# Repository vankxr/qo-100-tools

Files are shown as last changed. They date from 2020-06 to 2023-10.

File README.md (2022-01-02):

# qo-100-tools
Various tools for transmission and reception on the QO-100 satellite amateur transponder bands. Includes everything I need (hopefully) to build a fully remote managed RF frontend to be placed on the roof, near the antenna while only bringing a few cables between it and the shack: power, two coax cables (TX IF and RX IF) and one UTP ethernet cable.

## Included tools
 - Upconverter - Converts the VHF/UHF IF signal to the uplink frequency of the satellite (2.4 GHz)
 - PA - Boosts the output power to 20 W (v1) and 250 W (v2) maximum
 - PA Driver - Amplifier to drive the main 250W PA
 - Directional Couplers - Experimental, manually constructed with simple scalpel cut traces on some Rogers RO4350B substrate
 - GPSDO - GPS Disciplined Oscillator to generate different precise reference frequencies
 - LNB Controller - LNB Bias and reference injection controller
 - Digital Power Meter - Module to measure DC power, used to calculate the PA efficiency
 - Digital RF Power Meter - Module to measure RF power, used to calculate the PA efficiency
 - Generic Filter - Footprints to build up to 11th order Butterworth/Chebyshev filters
 - Orange Pi Dock - Main board to house an OPi that will be the main brain of the system
 - Relay Controller - Module to provide relay coil switching capabilities
 - RF Switch - Implements a 5PST or 4PST RF switch for routing purposes
 - PSU Interface - Interface board for HP Common Slot Power supplies
 - SAW Filter adapter - Footprints for various SAW filter packages
 - PA Bias controller - Bias generator and monitor for the Power Amplifiers
 - PA TEC controller - Peltier cooler controller for the big PA
 - I2C Buffer - I2C bus signal buffer
 - Environment sensors - Sensor carrier board
 - LoRa Transceiver - SX1276 breakout for LoRa experiments

## Dependencies
 - [icyradio](https://github.com/vankxr/icyradio/tree/qo100) - IcyRadio Software Defined Radio to transmit and receive IF signals to the roof RF frontend
 - [icestorm](https://github.com/cliffordwolf/icestorm) - FPGA toolchain
 - [arm-none-eabi-gcc](https://developer.arm.com/tools-and-software/open-source-software/developer-tools/gnu-toolchain/gnu-rm/downloads) - MCUs toolchain
 - [Device CMSIS](https://www.keil.com/dd2/) - CMSIS headers defining the MCU memories, peripherals, etc...
 - [Core CMSIS](https://github.com/ARM-software/CMSIS_5) - CMSIS headers defining the ARM Cores
 - [armmem](https://github.com/vankxr/armmem) - ELF file analyzer (required for the MCU Makefiles to work)

## Authors

* **João Silva** - [vankxr](https://github.com/vankxr)

## Special thanks

* [JLCPCB](https://jlcpcb.com) for sponsoring most of the PCBs needed for this project.
* [raplin](https://github.com/raplin) for the work on [reverse engineering the HP power supplies](https://github.com/raplin/DPS-1200FB)

## License

The content of this repository is licensed under the [GNU General Public License v3.0](LICENSE).

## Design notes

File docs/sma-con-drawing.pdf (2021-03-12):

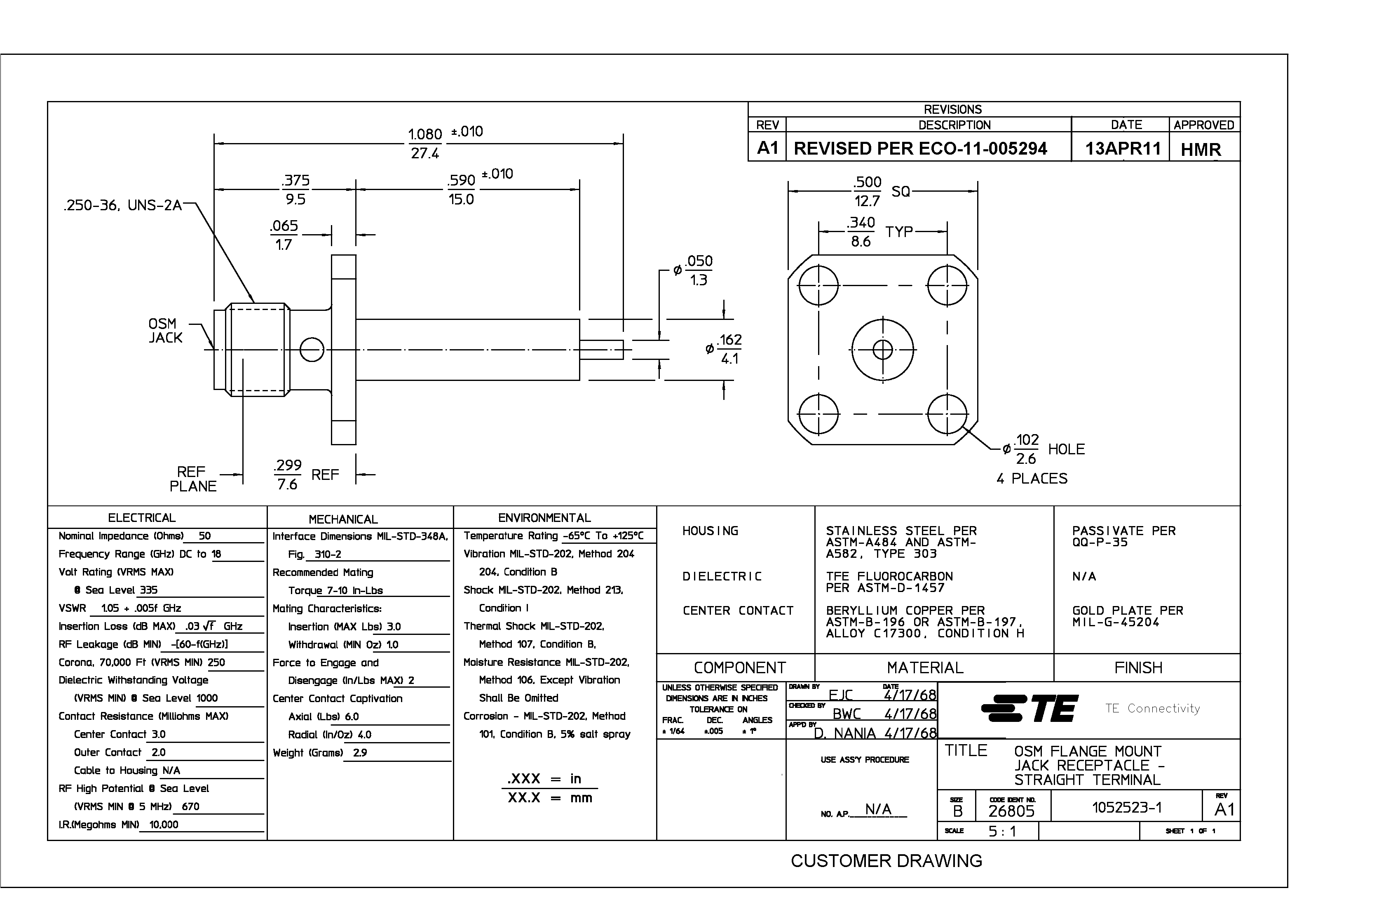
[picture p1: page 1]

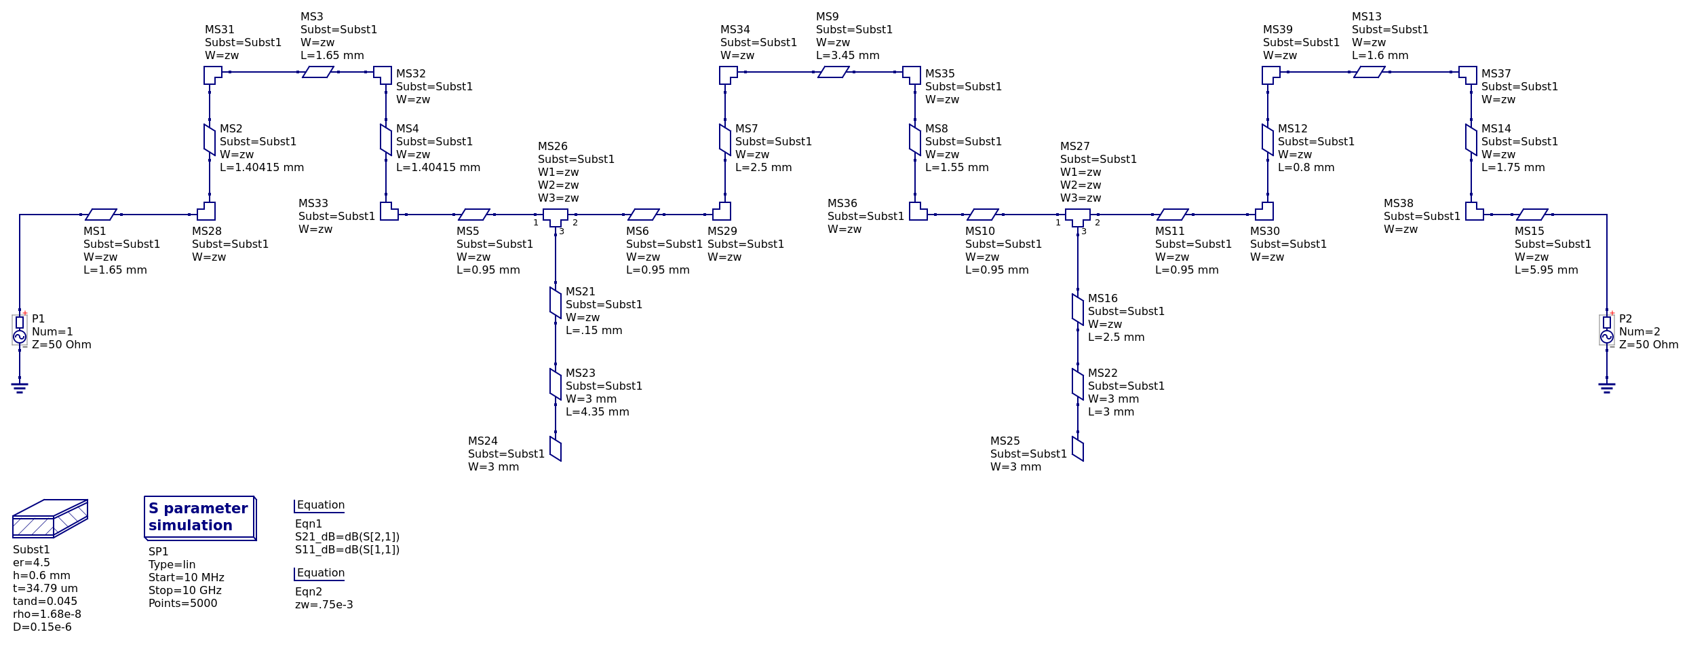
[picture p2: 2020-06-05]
util/pa-lpf-simulation/schematic.png

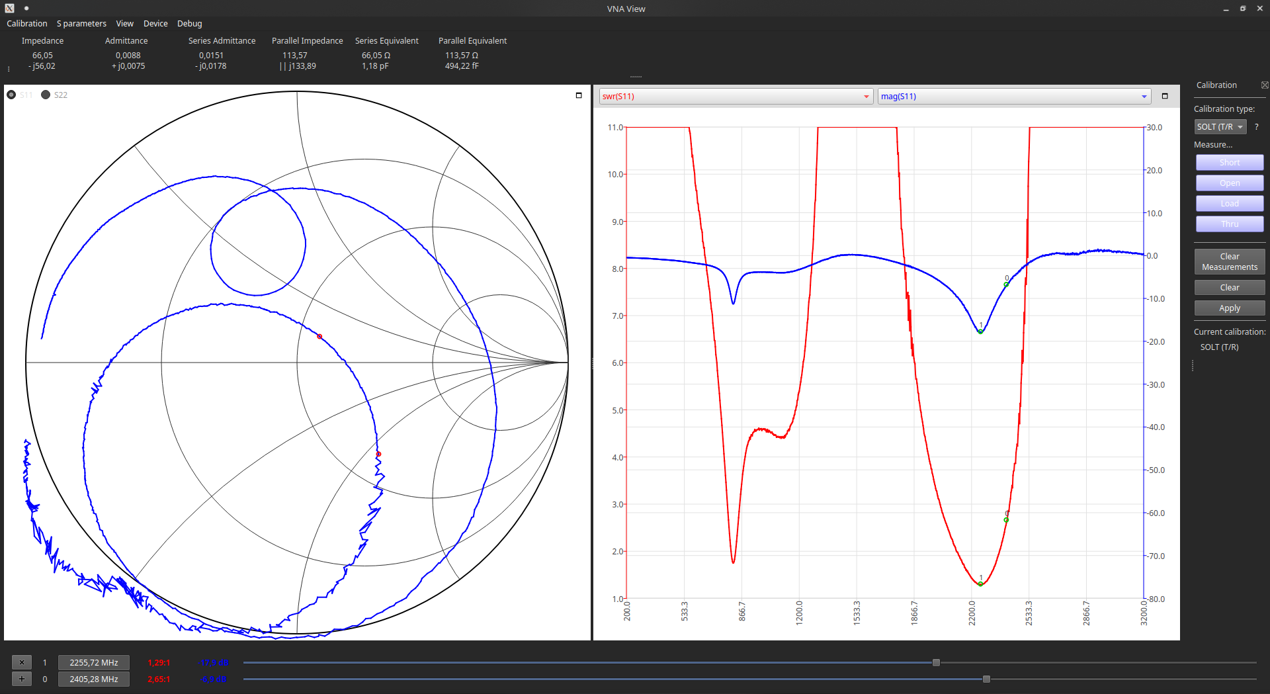
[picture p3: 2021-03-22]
docs/upconverter/upconverter_v3_mixer_output.png

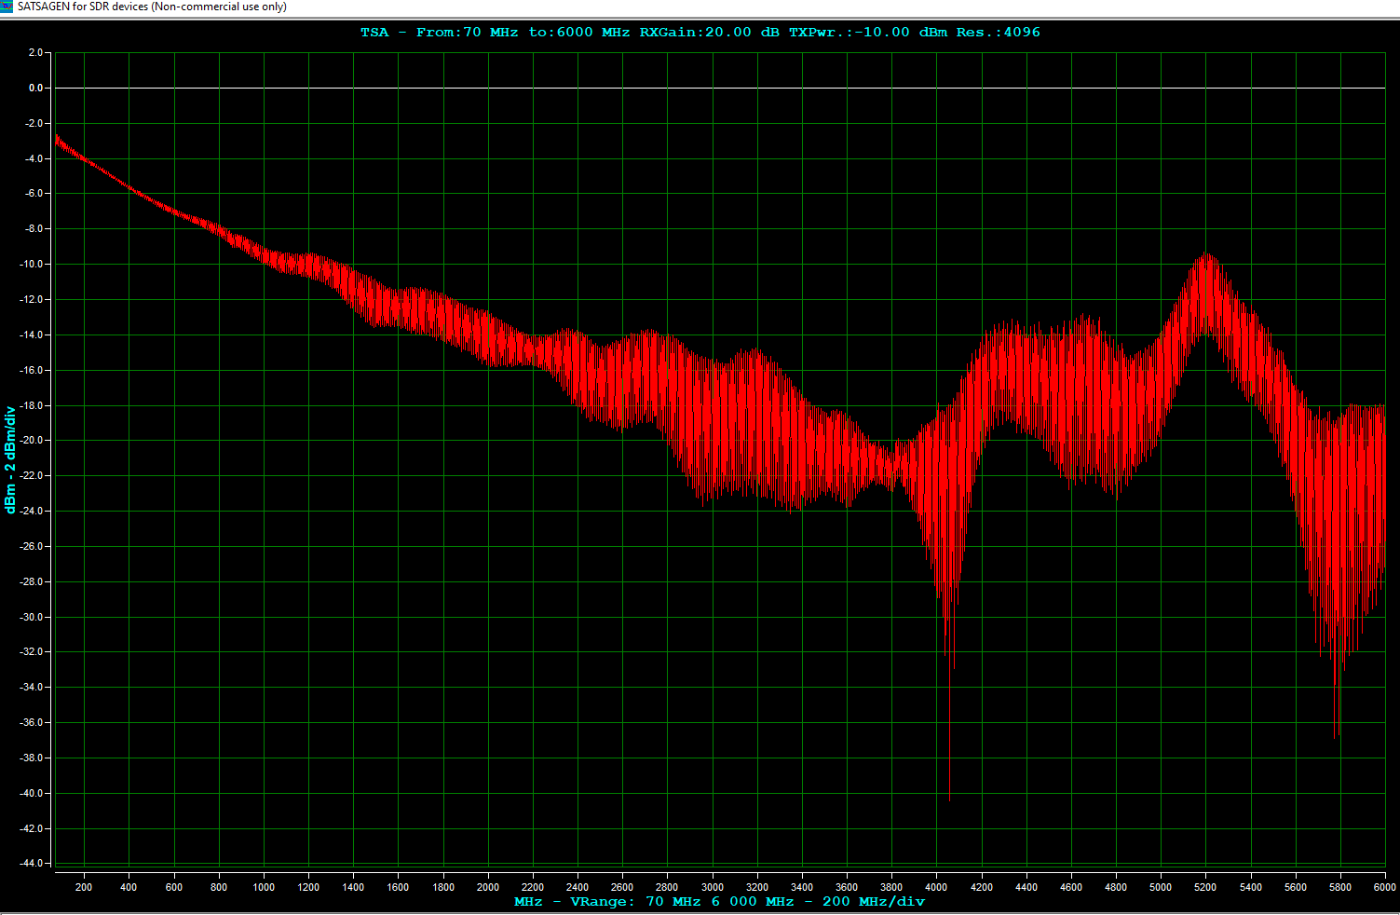
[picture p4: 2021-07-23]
docs/roof-cables/atten_1_2.png

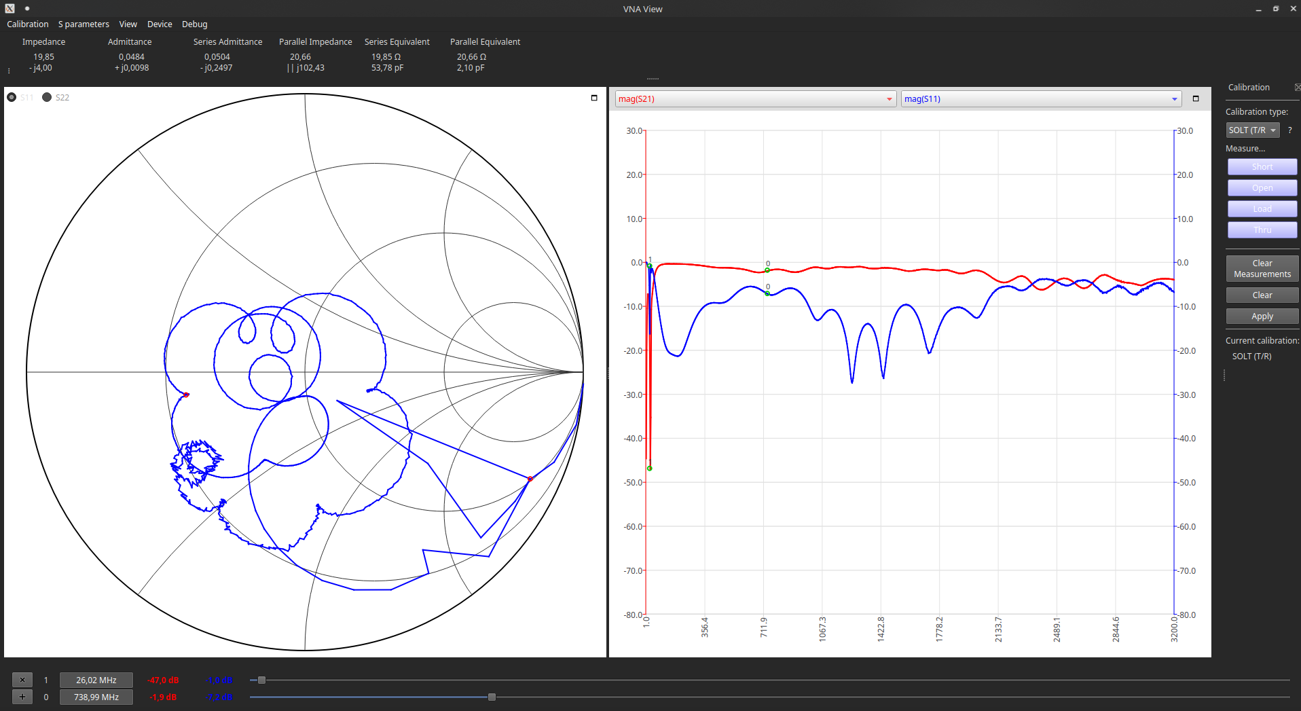
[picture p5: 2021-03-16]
docs/lnb-controller/lnb-controller-v2-path1-IF-to-RF.png

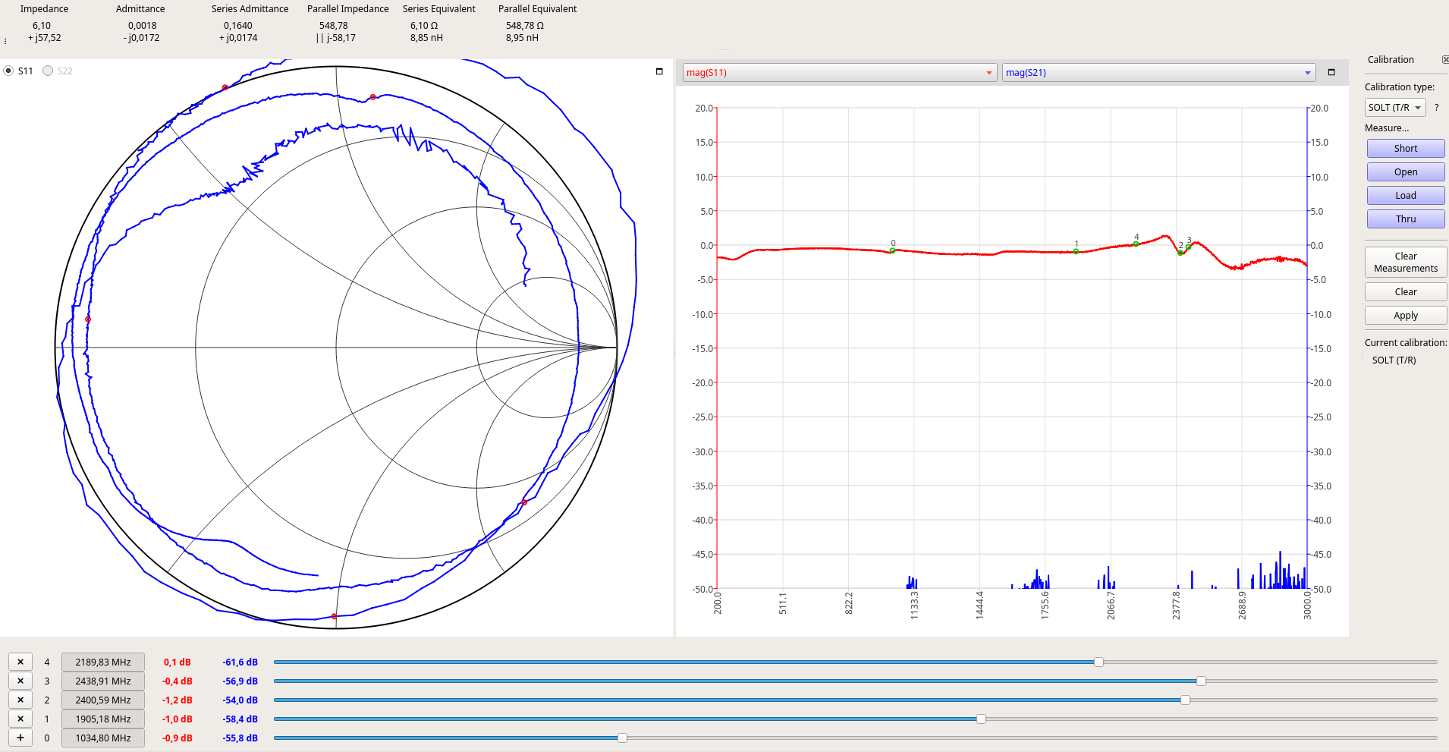
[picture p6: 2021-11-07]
docs/pa-driver/pa_20W_vdd_31V_idq_400mA_s22.png

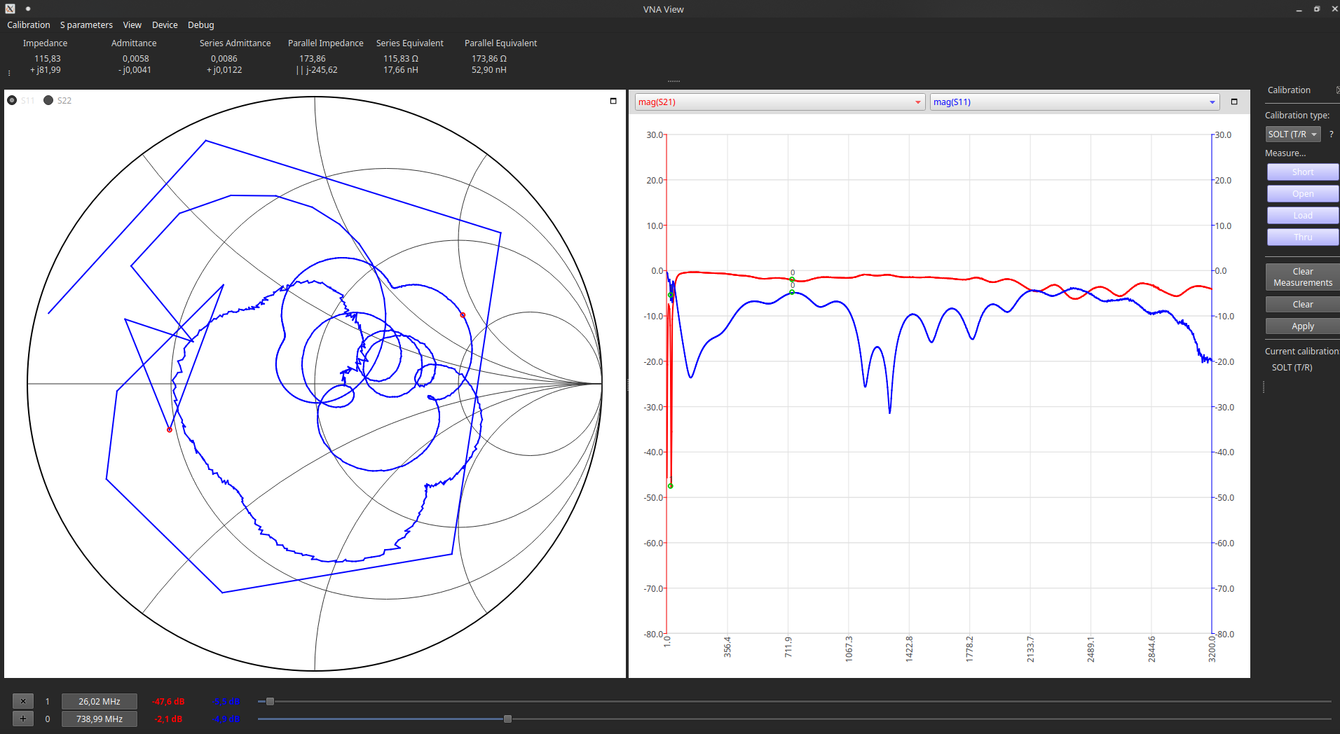
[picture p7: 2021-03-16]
docs/lnb-controller/lnb-controller-v2-path1-RF-to-IF.png

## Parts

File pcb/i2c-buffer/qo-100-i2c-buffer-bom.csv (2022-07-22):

Comment | Footprint | Designator
100nF | CAP0402 | C1, C2, C3, C5, C6, C7, C8, C9, C10, C11, C12
10K Ohms | RES0402 | R1, R13, R14, R15, R16, R17, R18, R19, R20
10uF | CAP0603 | C13, C14
1K Ohms | RES0402 | R2, R3, R5, R6, R7, R8, R9, R10, R11, R12, R21, R22, R23, R24, R25
1uF | CAP0402 | C4, C15
330 Ohms | RES0402 | R4
LED0603 | 0603 | D1
LED0603 | 0603 | D2, D3, D4, D5
LED0603 | 0603 | D10
LED0603 | 0603 | D6, D7, D8, D9

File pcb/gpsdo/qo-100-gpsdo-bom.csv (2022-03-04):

Comment | Footprint | Designator
0 Ohms | RES0402 | R22, R41, R42, R43, R44, R45
10 Ohms | RES0603 | R10
100 Ohms | RES0402 | R2, R3, R27, R29, R31, R33, R35
100K Ohms | POT3MM | R36, R37, R38, R39, R40
100K Ohms | RES0402 | R57, R59
100nF | CAP0402 | C2, C3, C4, C5, C6, C7, C9, C12, C13, C14, C18, C19, C24, C25, C27, C29, C31, C32, C42, C45, C68, C69, C70, C71, C72, C73, C74, C75, C76, C77, C80, C81, C82, C83, C84, C88, C89, C90, C101, C103, C104, C106, C107, C112, C114
100nH | IND0402 | L36
100pF | CAP0402 | C55, C56
100uF | CAP1206 | C11, C30, C108, C110, C111
10K Ohms | RES0402 | R7, R9, R14, R15, R16, R17, R23, R24, R25, R47, R48, R49, R50, R58
10nF | CAP0402 | C93, C96, C99, C109
10pF | CAP0402 | C40, C105
10uF | CAP0603 | C1, C10, C16, C17, C20, C23, C33, C43, C100, C102, C113
10uF | CAP1206 | C117
10uH | IND0603 | FB3
120nH | IND0402 | L21, L29, L30
150nH | IND0402 | L6, L34, L35
180nH | IND0402 | L16, L19, L20, L26
180pF | CAP0402 | C58, C59, C63, C64
1K Ohms | RES0402 | R12
1M Ohms | RES0402 | R54
1uF | CAP0402 | C8, C21, C22, C26, C28, C34, C35, C36, C37, C38, C39, C41, C44, C46, C48, C49, C78, C79, C85, C86, C87, C98
1uF | CAP0603 | C94, C95
1uH | IND0603 | FB1, FB2, FB4, FB5, FB6
2.2uH | IND3515 | L37
2.6A Hold | 1206 | F1
220nF | CAP0402 | C47, C50
220nH | IND0402 | L4, L5
226K Ohms | RES0402 | R55
22nH | IND0402 | L11
270 Ohms | RES0402 | R21
270nH | IND0402 | L14, L15, L24, L25
270pF | CAP0402 | C53, C54
27nH | IND0805 | L1
280 Ohms | RES0402 | R18
2EDG-2P-5MM | 2EDG-2P-5MM | CON4
3.9nF | CAP0402 | C51, C52
309K Ohms | RES0402 | R52
330 Ohms | RES0402 | R4, R19
330nH | IND0402 | L27, L28
33nH | IND0402 | L9, L10
390nH | IND0402 | L32, L33
3P-SH-SIDE | SH-03-SIDE | CON1
3P-SH-TOP | SH-03-TOP | CON3
4.7K Ohms | RES0402 | R1, R5, R6, R8
4.7uF | CAP0603 | C91, C92
4.7uH | IND0404 | L38
41.2K Ohms | RES0402 | R51
470 Ohms | RES0402 | R13
470nH | IND0402 | L17, L18
470pF | CAP0402 | C97, C115, C116
47pF | CAP0402 | C15, C62, C67
49.9 Ohms | RES0402 | R26, R28, R30, R32, R34
4P-SH-TOP | SH-04-TOP | CON2
510 Ohms | RES0402 | R20, R56
560nH | IND0402 | L2, L3
680nH | IND0402 | L22, L23
68pF | CAP0402 | C57, C60, C61, C65, C66
71.5K Ohms | RES0402 | R53
74LVC1G17 | SC70-5 | U2, U3, U11, U12, U13, U14, U15
75K Ohms | RES0402 | R46, R60
820nH | IND0402 | L12, L13
82nH | IND0402 | L7, L8, L31
AD5541ACPZ | DFN10 | U6
AD9544 | QFN48_2 | U10
ADM7171ACPZ-1.8 | LFCSP8_3X3 | U16
ADM7171ACPZ-3.3 | LFCSP8_3X3 | U20
ADM7171ACPZ-5.0 | LFCSP8_3X3 | U17
B0530W | SOD-123 | D3
BAV99 | SOT23 | D4, D5, D6, D7, D8
CR2032 | CR2032 | BAT1
DCJACK | DC-050 | J1
DNP | RES0603 | R11
DSB321SDA | TCXO-3225 | U9
EFM32GG11B420F2048GL112 | BGA112 | U1
JS-5MM | JS_5MM | LOGO1
LED0603 | 603 | D1, D9
LEDTH3MM | LED_3MM | D2, D10
LT8636 | QFN20_ASYM_3X4_CORNER | U19
MAX-M8Q | MAX-M8 | U4
MCP1501-40 | SOT23-6 | U5
MCP6V31 | SOT23-5 | U7
MIC23155 | DFN10 | U18
OSC5A2B02 | OSC5A2B02 | U8
RFCON-SMA-EDGE | SMA-EDGE | RFCON1
RFCON-U.FL | U.FL | RFCON2, RFCON3, RFCON4, RFCON5, RFCON6, RFCON7, RFCON8, RFCON9, RFCON10, RFCON11
SMAJ24A | DO214AC | D11
TC2050-IDC | TC2050-IDC | TC1

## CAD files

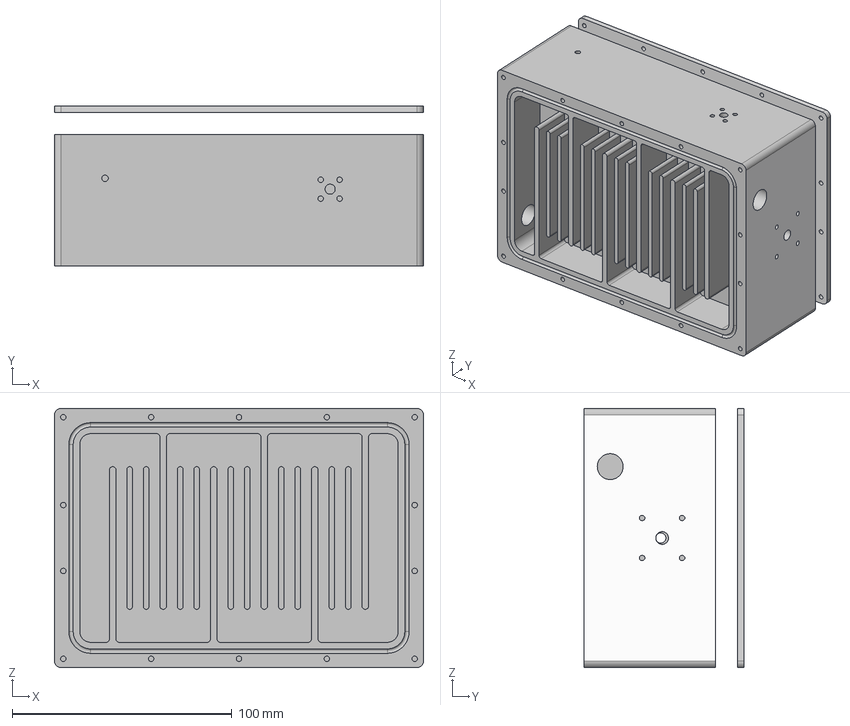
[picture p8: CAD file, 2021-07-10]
models/pa-case/pa-case.step
168.0 x 73.0 x 118.0 mm

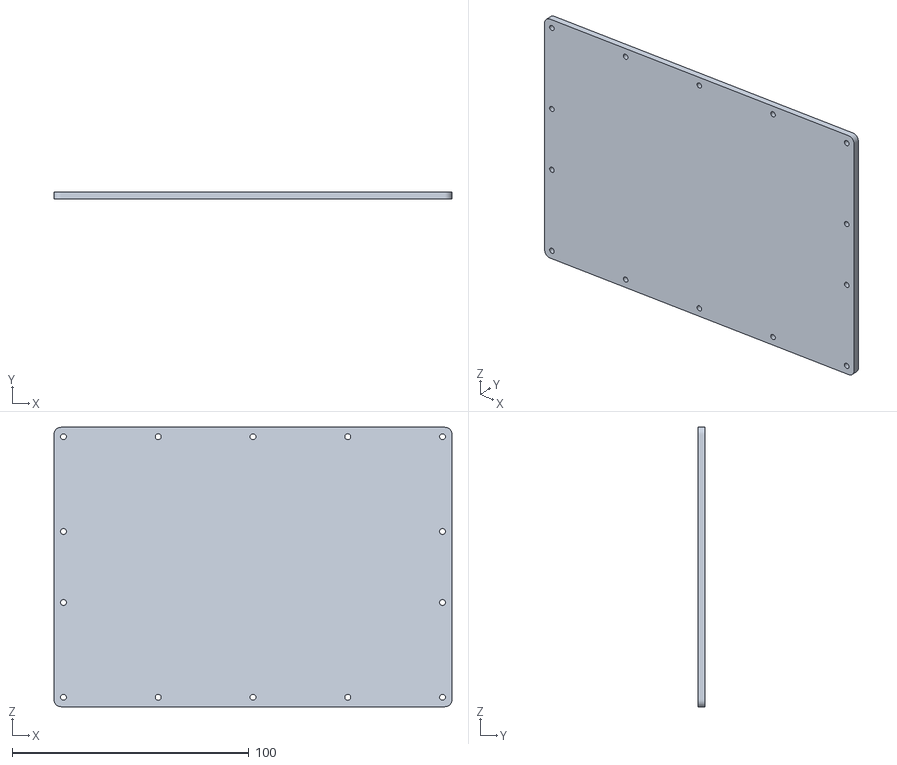
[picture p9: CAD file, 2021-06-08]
models/pa-case/pa-case-lid.stl
168.0 x 3.00 x 118.0

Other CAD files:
docs/pa-driver/BLP9G0722-20G_2100MHz_ref_pcb.dwg
docs/pa/BLC2425M9LS250_ref_pcb.dxf
models/pa-case/pa-case.stl

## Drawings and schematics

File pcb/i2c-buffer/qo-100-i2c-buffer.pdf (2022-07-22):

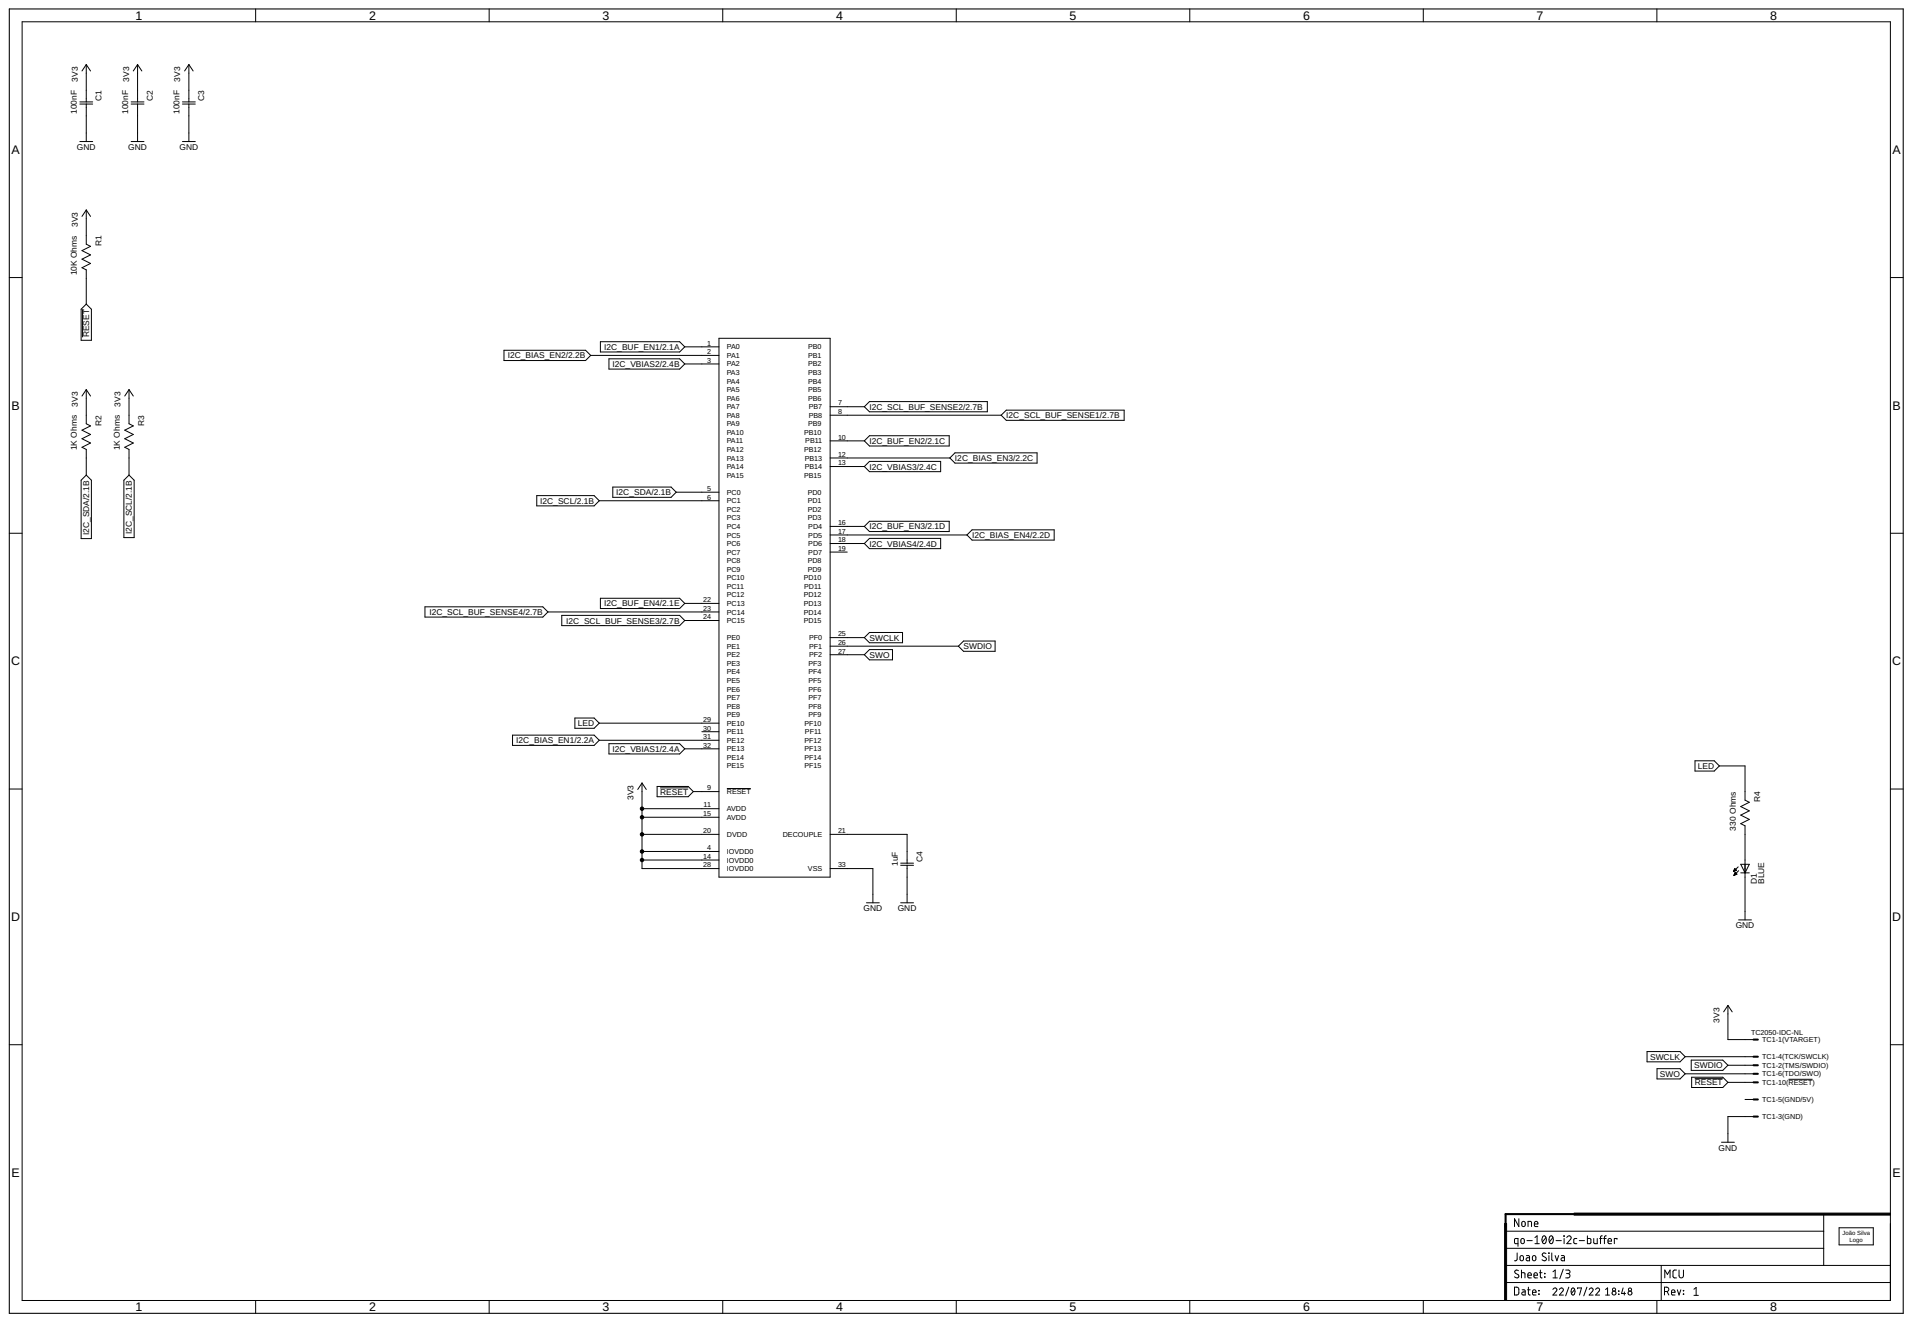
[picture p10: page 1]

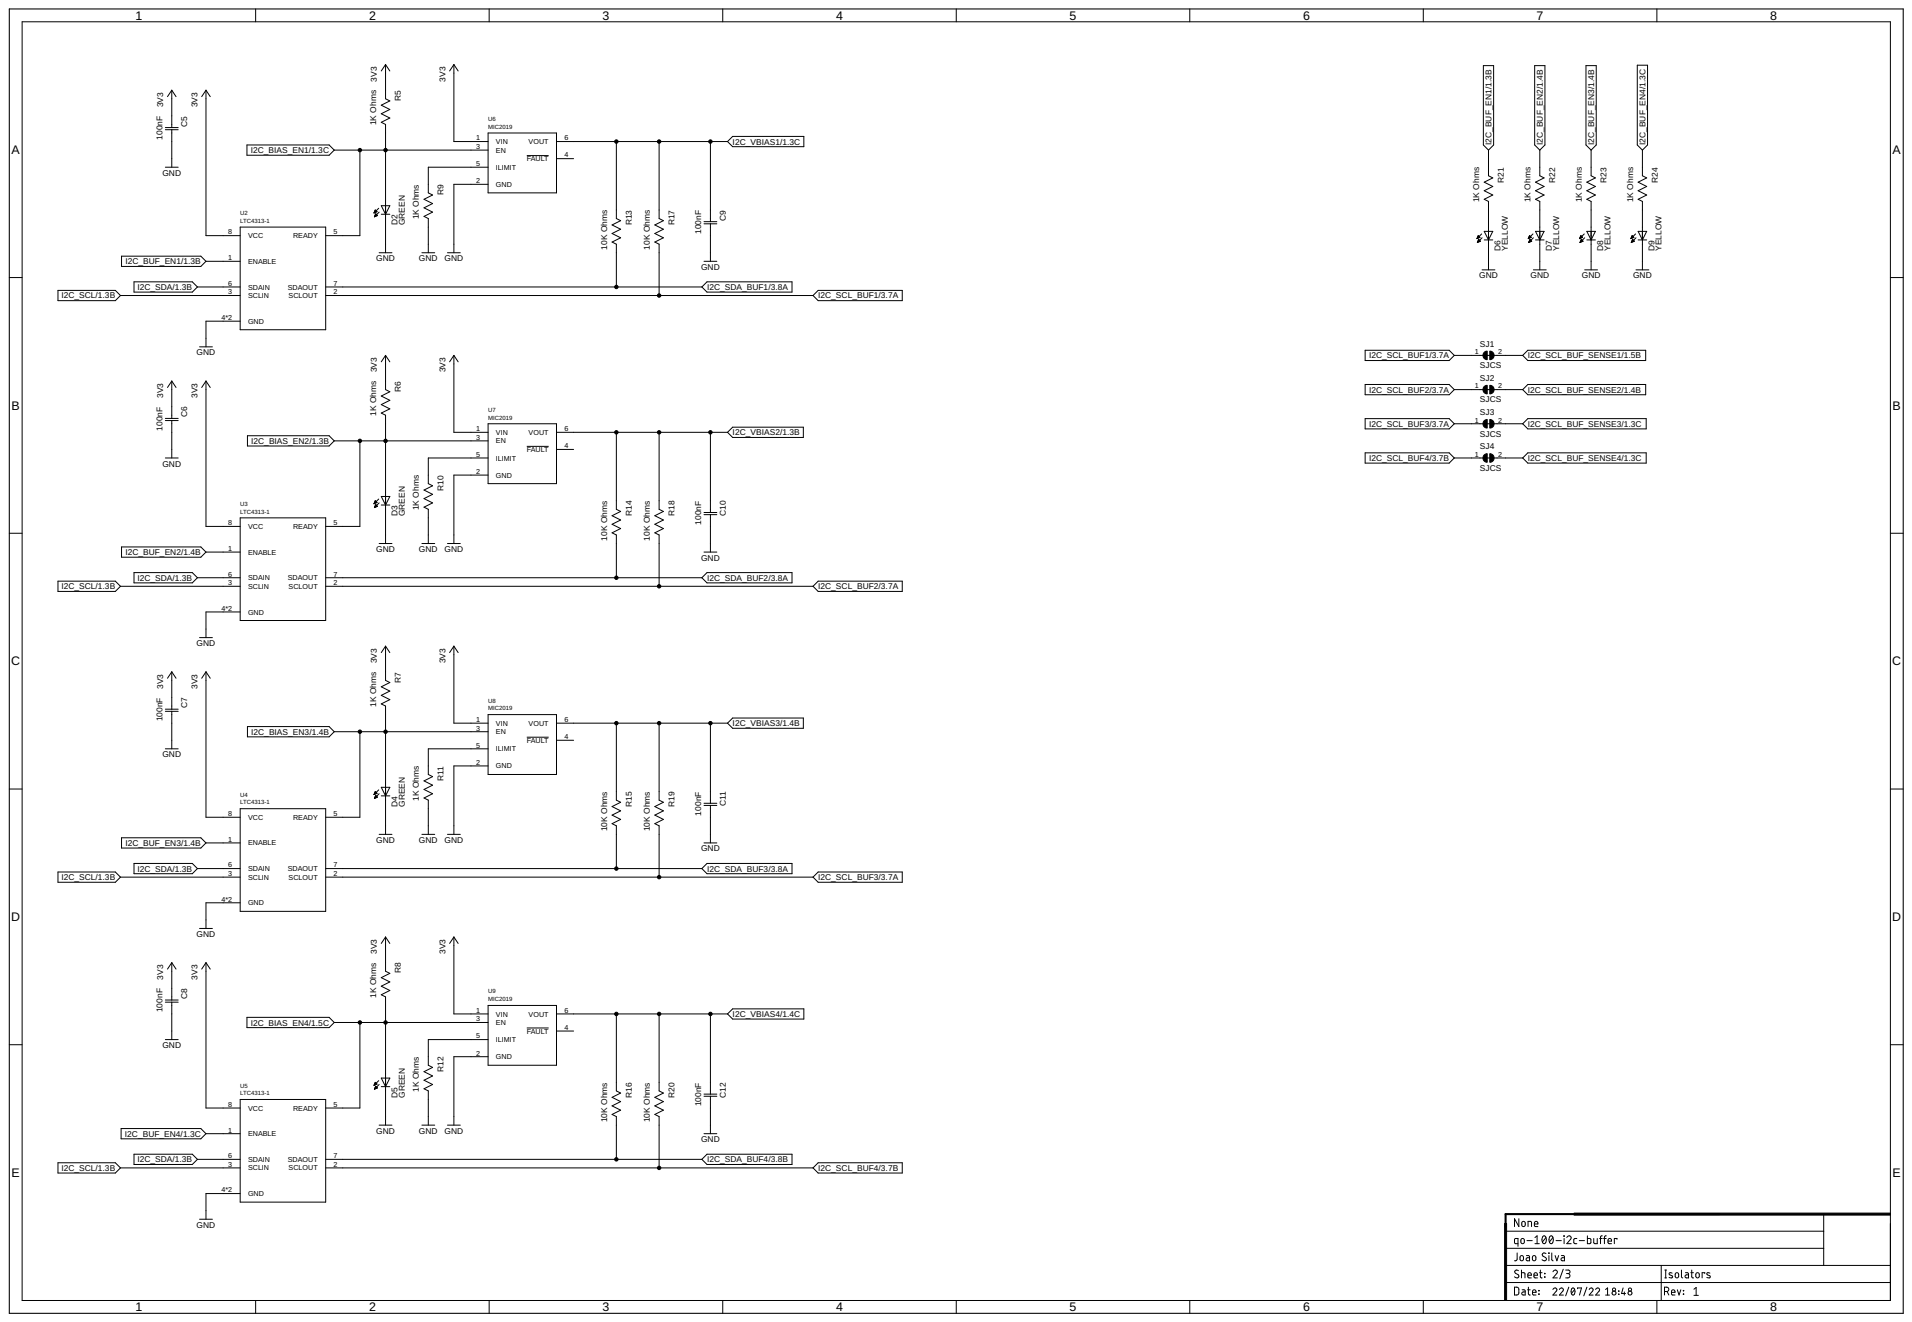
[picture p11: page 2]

10K Ohms 10K Ohms LTC4313-1 100nF GND 3V3 GND 3V3 1K Ohms GREEN 3V3 GND MIC2019 1K Ohms GND GND 3V3 100nF GND 10K Ohms 10K Ohms LTC4313-1 100nF GND 3V3 GND 3V3 1K Ohms GREEN 3V3 GND MIC2019 1K Ohms GND GND 3V3 100nF GND 10K Ohms 10K Ohms LTC4313-1 100nF GND 3V3 GND 3V3 1K Ohms GREEN 3V3 GND MIC2019 1K Ohms GND GND 3V3 100nF GND 10K Ohms 10K Ohms LTC4313-1 100nF GND 3V3 GND 3V3 1K Ohms GREEN 3V3 GND MIC2019 1K Ohms GND GND 3V3 100nF GND YELLOW GND 1K Ohms YELLOW GND 1K Ohms YELLOW GND 1K Ohms YELLOW GND 1K Ohms SJCS SJCS SJCS SJCS R13 R17 SDAIN 6 SCLIN 3 VCC 8 GND 4*2 SDAOUT 7 SCLOUT 2 ENABLE 1 READY 5 U2 C5 R5 D2 VOUT 6 FAULT 4 EN 3 GND 2 VIN 1 ILIMIT 5 U6 R9 C9 R14 R18 SDAIN 6 SCLIN 3 VCC 8 GND 4*2 SDAOUT 7 SCLOUT 2 ENABLE 1 READY 5 U3 C6 R6 D3 VOUT 6 FAULT 4 EN 3 GND 2 VIN 1 ILIMIT 5 U7 R10 C10 R15 R19 SDAIN 6 SCLIN 3 VCC 8 GND 4*2 SDAOUT 7 SCLOUT 2 ENABLE 1 READY 5 U4 C7 R7 D4 VOUT 6 FAULT 4 EN 3 GND 2 VIN 1 ILIMIT 5 U8 R11 C11 R16 R20 SDAIN 6 SCLIN 3 VCC 8 GND 4*2 SDAOUT 7 SCLOUT 2 ENABLE 1 READY 5 U5 C8 R8 D5 VOUT 6 FAULT 4 EN 3 GND 2 VIN 1 ILIMIT 5 U9 R12 C12 D6 R21 D7 R22 D8 R23 D9 R24 1 2 SJ1 1 2 SJ2 1 2 SJ3 1 2 SJ4 I2C_SCL/1.3B I2C_SCL/1.3B I2C_SCL/1.3B I2C_SCL/1.3B I2C_SDA/1.3B I2C_SDA/1.3B I2C_SDA/1.3B I2C_SDA/1.3B I2C_SDA_BUF1/3.8A I2C_SCL_BUF1/3.7A I2C_SCL_BUF1/3.7A I2C_BIAS_EN1/1.3C I2C_BUF_EN1/1.3B I2C_BUF_EN1/1.3B I2C_VBIAS1/1.3C I2C_BUF_EN2/1.4B I2C_BUF_EN2/1.4B I2C_BIAS_EN2/1.3B I2C_VBIAS2/1.3B I2C_SDA_BUF2/3.8A I2C_SCL_BUF2/3.7A I2C_SCL_BUF2/3.7A I2C_SDA_BUF3/3.8A I2C_SCL_BUF3/3.7A I2C_SCL_BUF3/3.7A I2C_SDA_BUF4/3.8B I2C_SCL_BUF4/3.7B I2C_SCL_BUF4/3.7B I2C_VBIAS4/1.4C I2C_BIAS_EN4/1.5C I2C_BUF_EN4/1.3C I2C_BUF_EN4/1.3C I2C_VBIAS3/1.4B I2C_BIAS_EN3/1.4B I2C_BUF_EN3/1.4B I2C_BUF_EN3/1.4B I2C_SCL_BUF_SENSE1/1.5B I2C_SCL_BUF_SENSE2/1.4B I2C_SCL_BUF_SENSE3/1.3C I2C_SCL_BUF_SENSE4/1.3C ABCDE 1 2 3 4 5 6 7 8 ABCDE 1 2 3 4 5 6 7 8

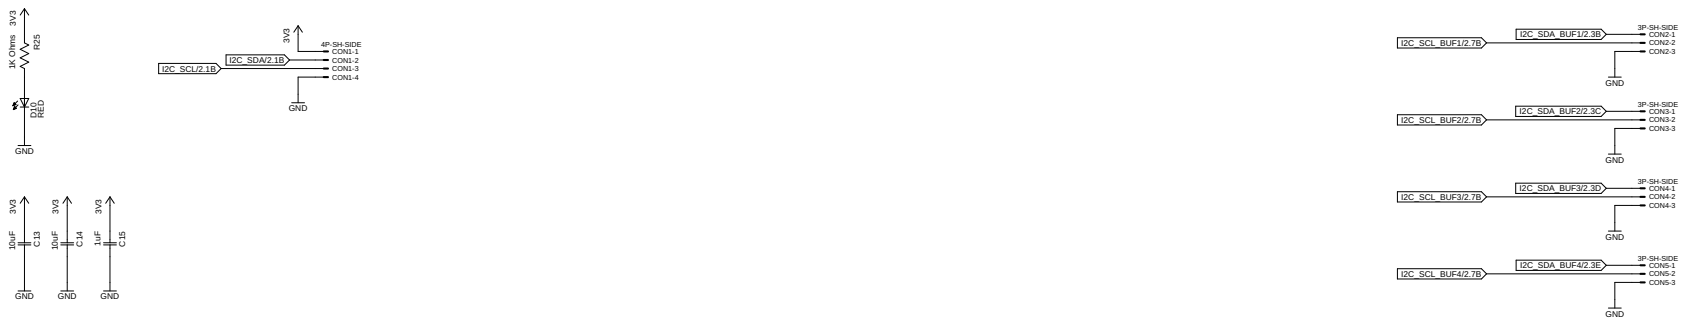
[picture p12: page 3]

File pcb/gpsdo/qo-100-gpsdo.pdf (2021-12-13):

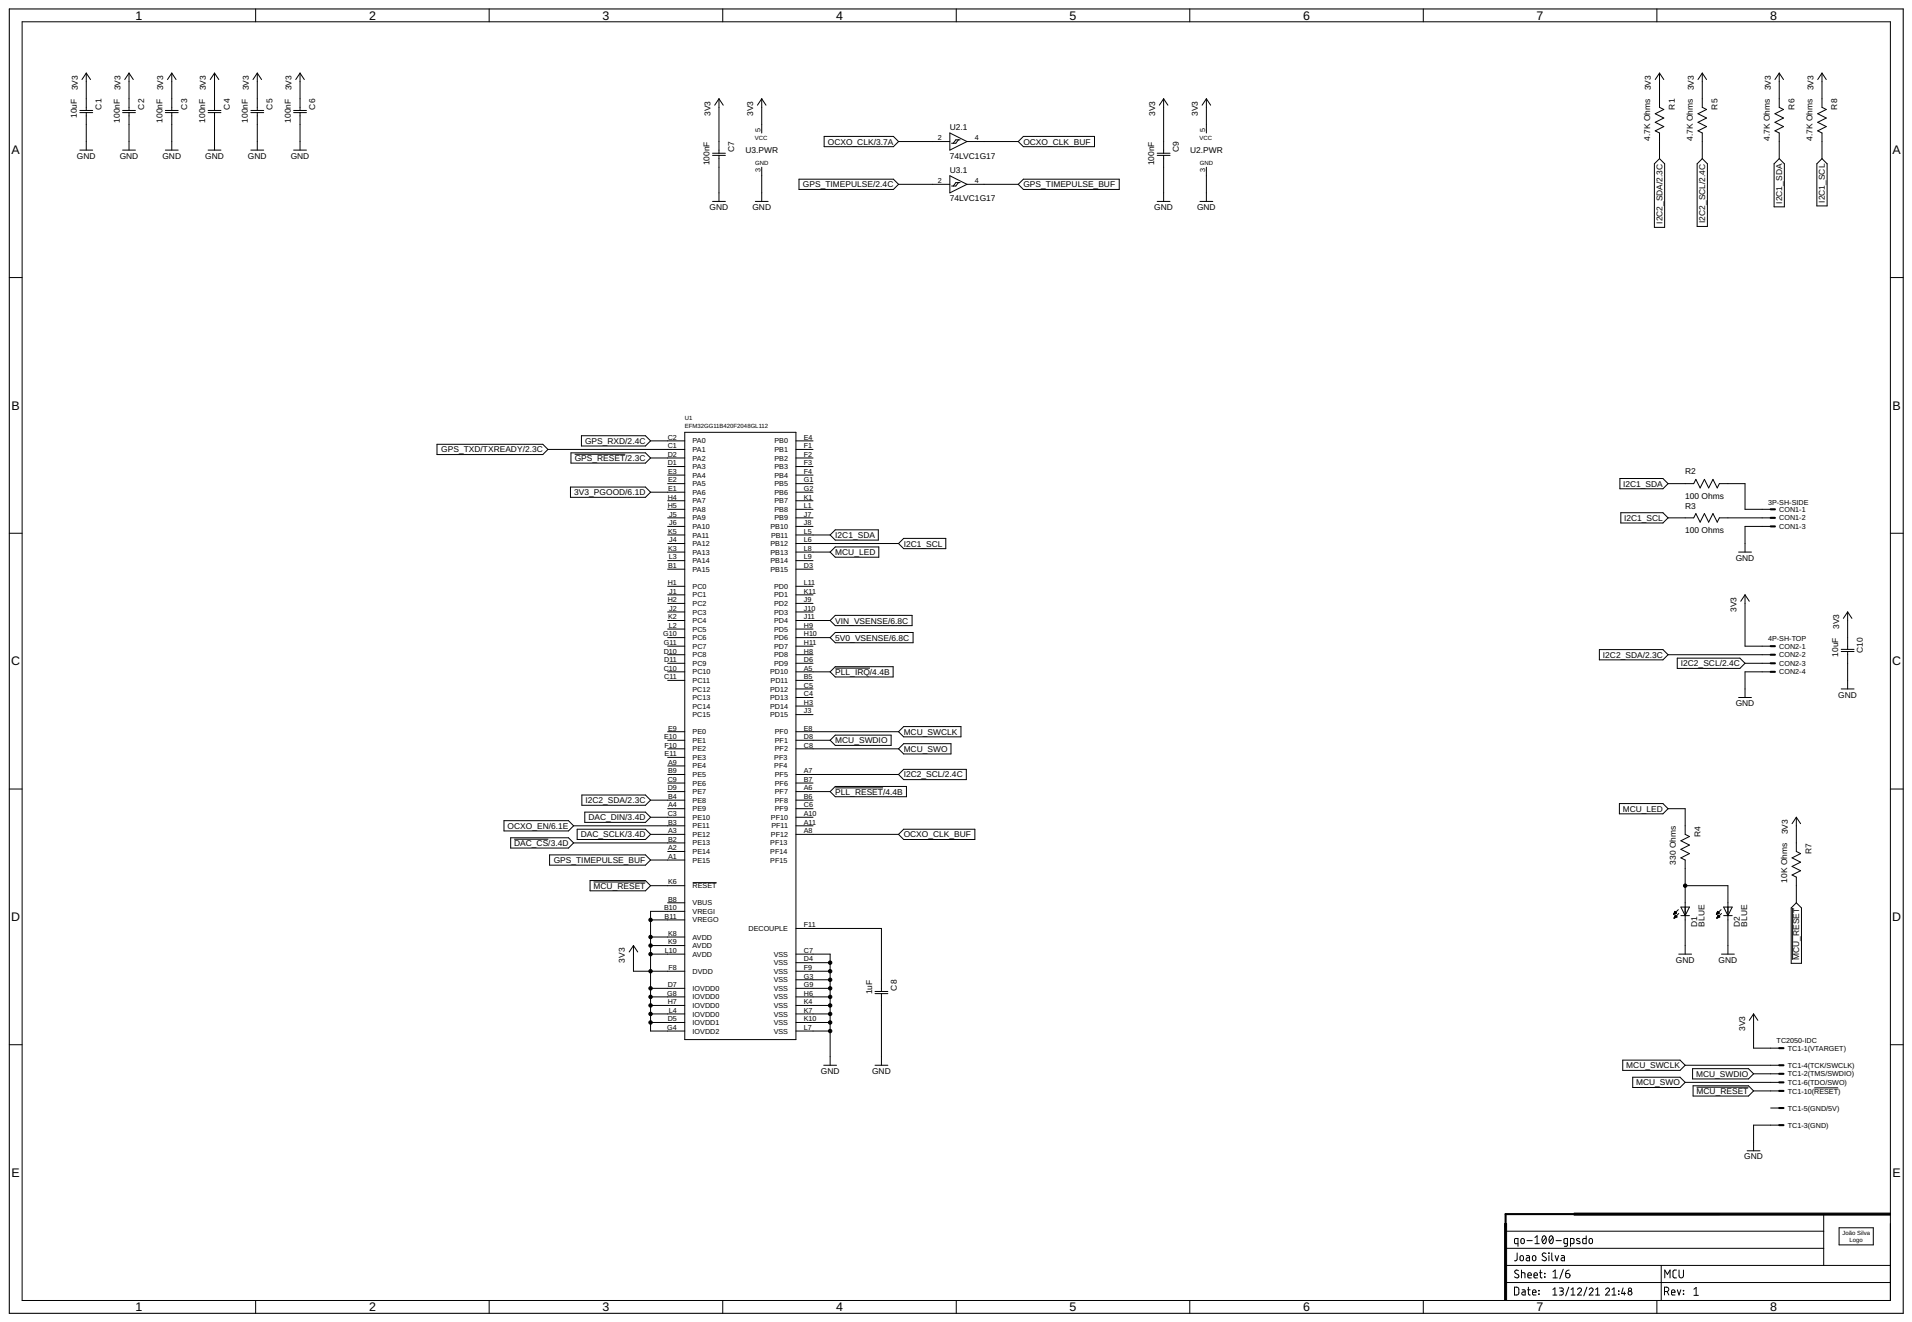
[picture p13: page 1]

10uF GND 3V3 100nF GND 3V3 100nF GND 3V3 100nF GND 3V3 100nF GND 3V3 4.7K Ohms 3V3 4.7K Ohms 3V3 10K Ohms 3V3 330 Ohms BLUE 3GND V3 GND GND 1uF TC2050-IDC GND 3V3 BLUE GND 4P-SH-TOP 3P-SH-SIDE GND 100 Ohms 100 Ohms GND 3V3 4.7K Ohms 3V3 4.7K Ohms 3V3 10uF GND 3V3 100nF GND 3V3 74LVC1G17 3V3 GND 74LVC1G17 100nF GND 3V3 3V3 GND 100nF GND 3V3 EFM32GG11B420F2048GL112 C1 C2 C3 C4 C5 R8 R6 R7 R4 D1 C8 TC1-1(VTARGET) TC1-2(TMS/SWDIO) TC1-3(GND) TC1-4(TCK/SWCLK) TC1-5(GND/5V) TC1-6(TDO/SWO) TC1-10(RESET) D2 CON2-1 CON2-2 CON2-3 CON2-4 CON1-1 CON1-2 CON1-3 R2 R3 R5 R1 C10 C7 5 3 VCC GND U3.PWR 2 4 U3.1 5 3 VCC GND U2.PWR 2 4 U2.1 C9 C6 PA0 C2 PA1 C1 PA2 D2 PA3 D1 PA4 E3 PA5 E2 PA6 E1 PA7 H4 PA8 H5 PA9 J5 PA10 J6 PA11 K5 PA12 J4 PA13 K3 PA14 L3 PA15 B1 PB0 E4 PB1 F1 PB2 F2 PB3 F3 PB4 F4 PB5 G1 PB6 G2 PB7 K1 PB8 L1 PB9 J7 PB10 J8 PB11 L5 PB12 L6 PB13 L8 PB14 L9 PC0 H1 PC1 J1 PC2 H2 PC3 J2 PC4 K2 PC5 L2 PC7 G11 PC8 D10 PC9 D11 PC10 C10 PC11 C11 PD0 L11 PD1 K11 PD2 J9 PD3 J10 PD4 J11 PD5 H9 PD6 H10 PD7 H11 PD8 H8 PD9 D6 PD10 A5 PD11 B5 PD12 C5 PE1 E10 PE2 F10 PE3 E11 PE4 A9 PE5 B9 PE6 C9 PE7 D9 PE8 B4 PE9 A4 PE10 C3 PE11 B3 PE12 A3 PE13 B2 PE14 A2 PE15 A1 PF0 E8 PF1 D8 PF2 C8 PF5 A7 PF6 B7 PF7 A6 PF8 B6 PF9 C6 PF10 A10 PF11 A11 PF12 A8 RESET K6 IOVDD0 D7 AVDD K9 DVDD F8 DECOUPLE F11 VBUS B8 VREGI B10 VREGO B11 VSS C7 IOVDD0 G8 IOVDD0 H7 IOVDD0 L4 IOVDD1 D5 VSS D4 VSS F9 VSS G3 PC6 G10 PE0 E9 AVDD K8 PB15 D3 PD13 C4 PD14 H3 PD15 J3 IOVDD2 G4 VSS G9 VSS H6 VSS K4 VSS K7 VSS K10 VSS L7 AVDD L10 U1 MCU_LED MCU_LED I2C2_SDA/2.3CI2C2_SDA/2.3C I2C2_SDA/2.3C I2C2_SCL/2.4C I2C2_SCL/2.4C I2C2_SCL/2.4C MCU_SWO MCU_SWO MCU_SWDIO MCU_SWDIO MCU_SWCLK MCU_SWCLK MCU_RESET MCU_RESET MCU_RESET I2C1_SDA I2C1_SDA I2C1_SDA I2C1_SCL I2C1_SCL I2C1_SCL GPS_TIMEPULSE/2.4C OCXO_CLK/3.7A VIN_VSENSE/6.8C 5V0_VSENSE/6.8C DAC_DIN/3.4D DAC_SCLK/3.4D DAC_CS/3.4D OCXO_EN/6.1E GPS_TIMEPULSE_BUF GPS_TIMEPULSE_BUF OCXO_CLK_BUF OCXO_CLK_BUF 3V3_PGOOD/6.1D GPS_RXD/2.4C GPS_TXD/TXREADY/2.3C GPS_RESET/2.3C PLL_IRQ/4.4B PLL_RESET/4.4B ABCDE 1 2 3 4 5 6 7 8 ABCDE 1 2 3 4 5 6 7 8 João Silva Logo PC12 PC13 PC14 PC15 PF3 PF4 PF13 PF14 PF15

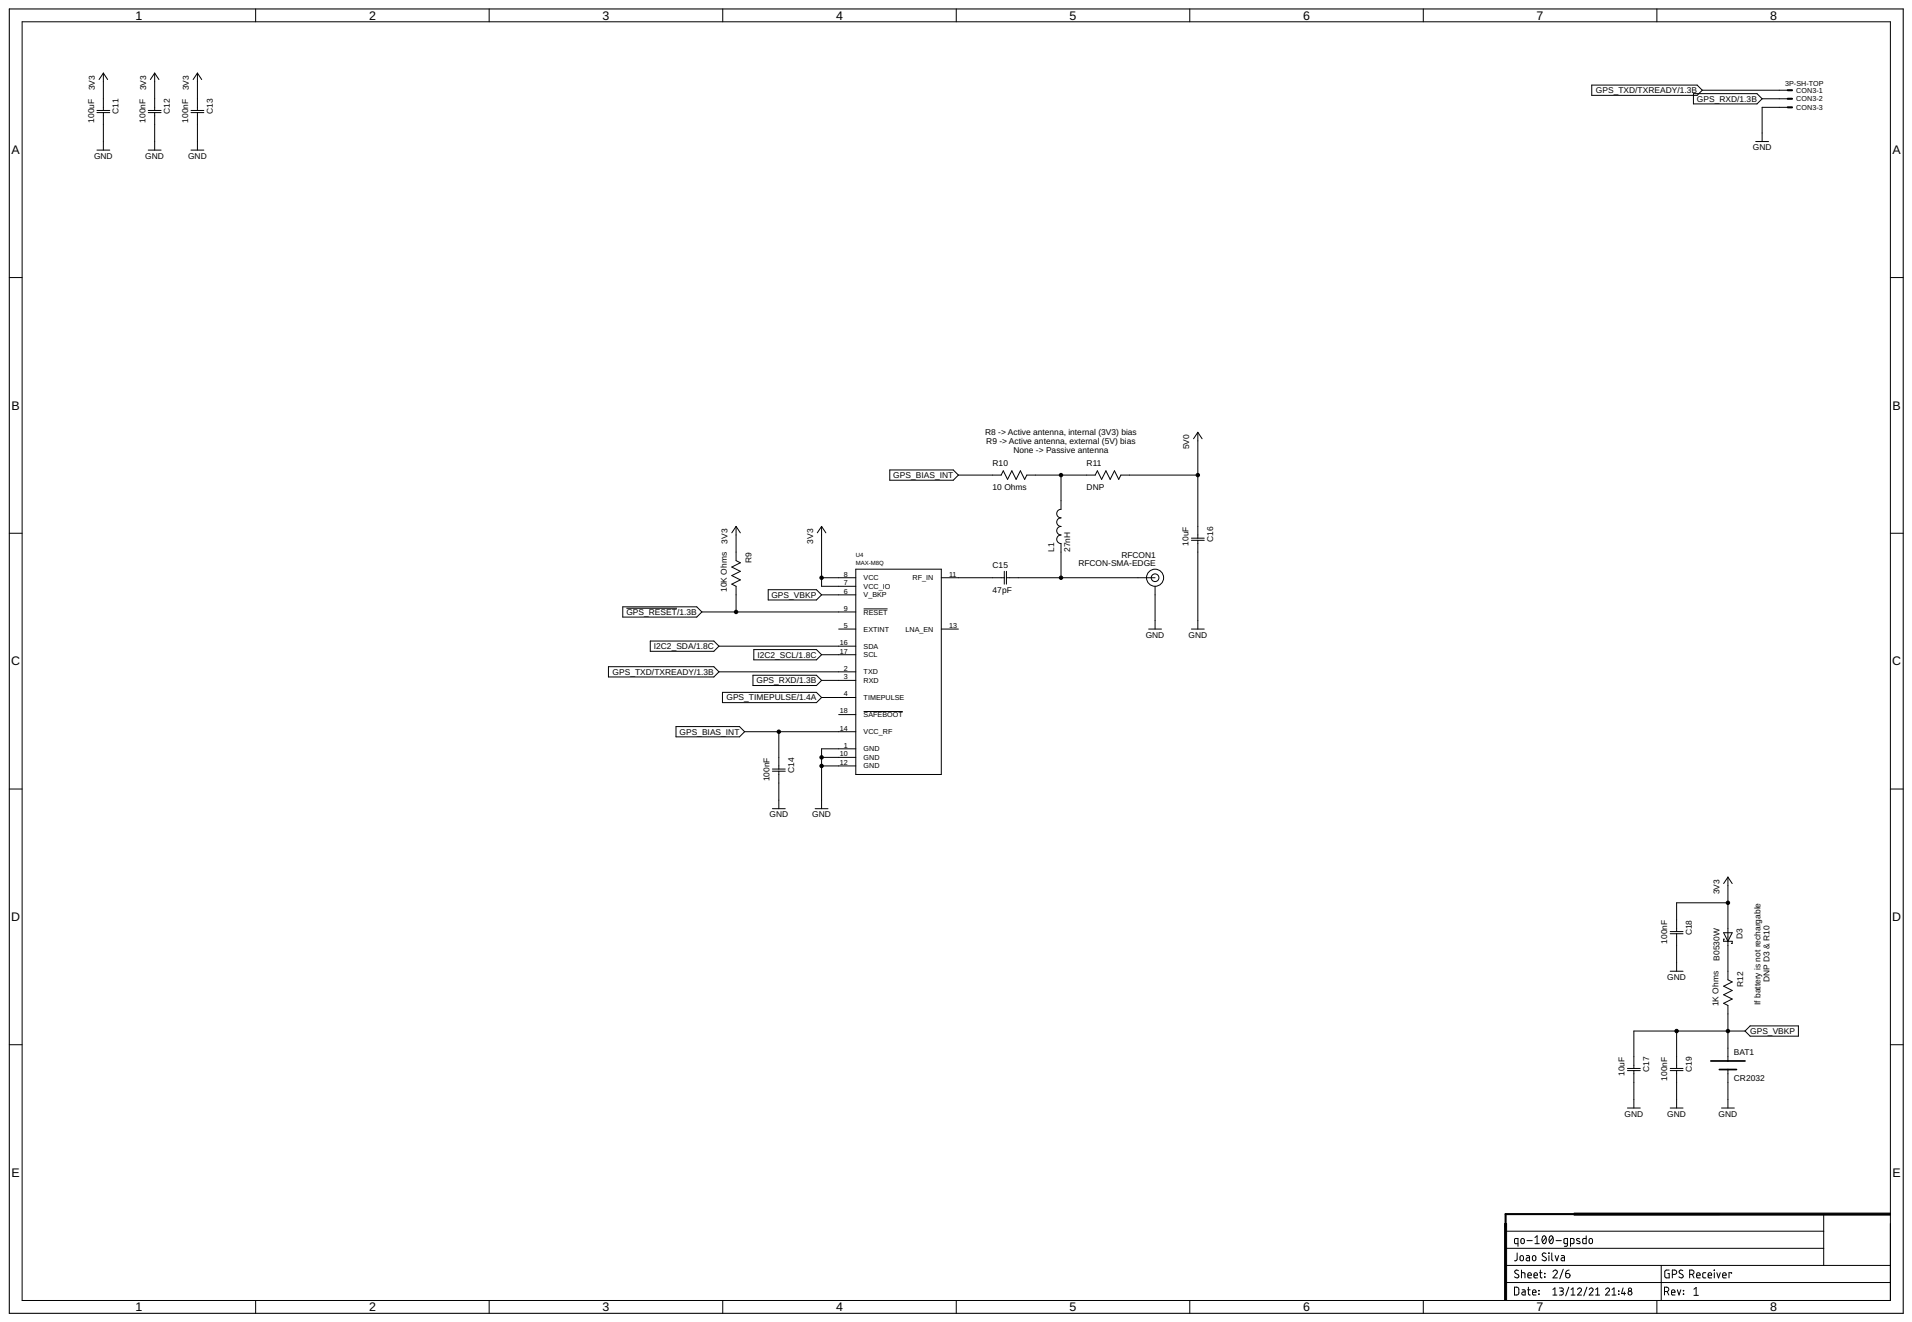
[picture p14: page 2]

R8 -> Active antenna, internal (3V3) bias R9 -> Active antenna, external (5V) bias None -> Passive antenna

If battery is not rechargable DNP D3 & R10

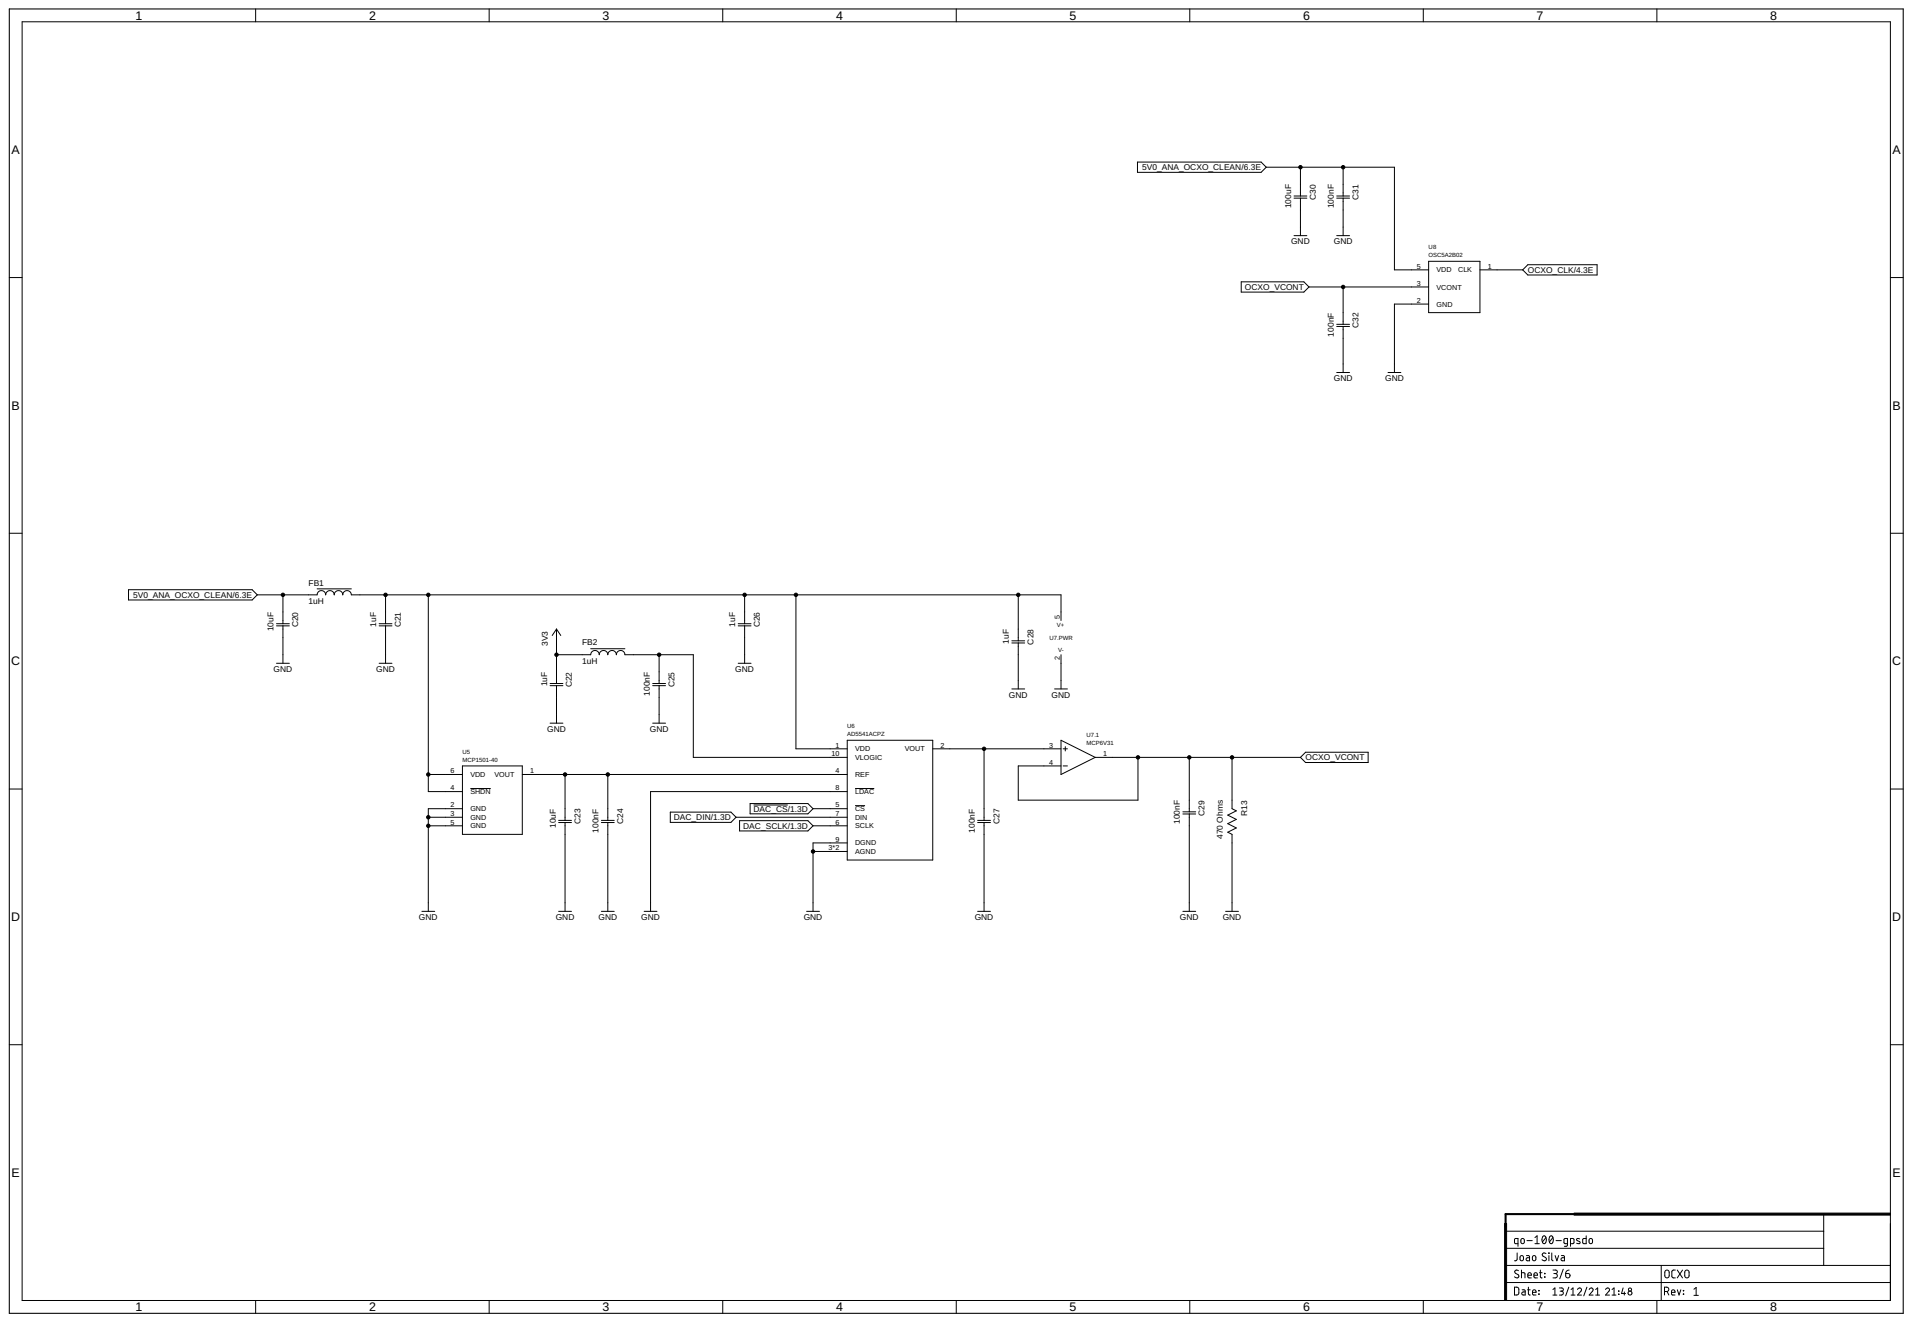
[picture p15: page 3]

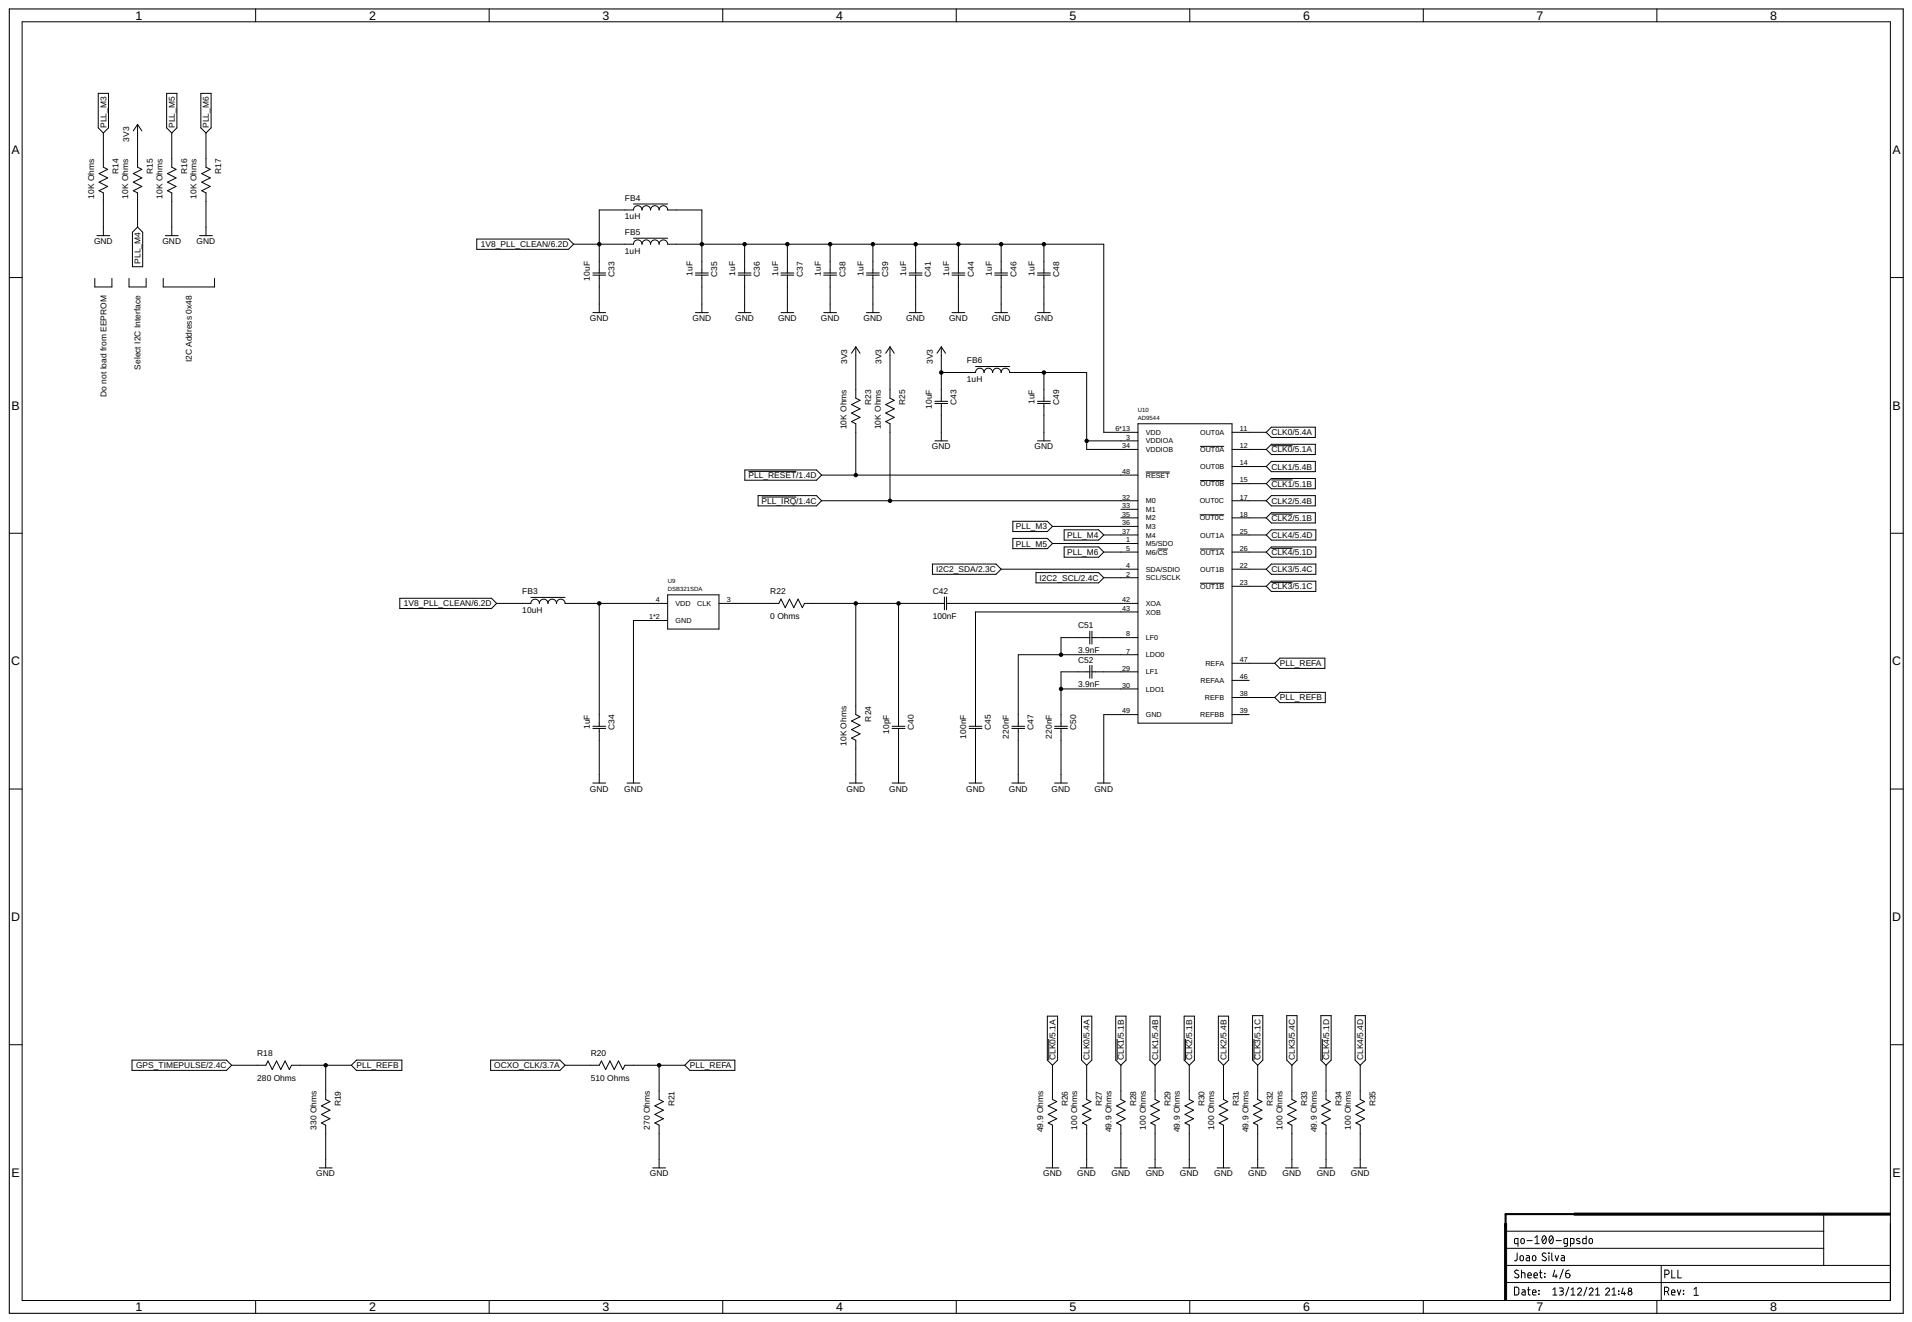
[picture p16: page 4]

Do not load from EEPRO

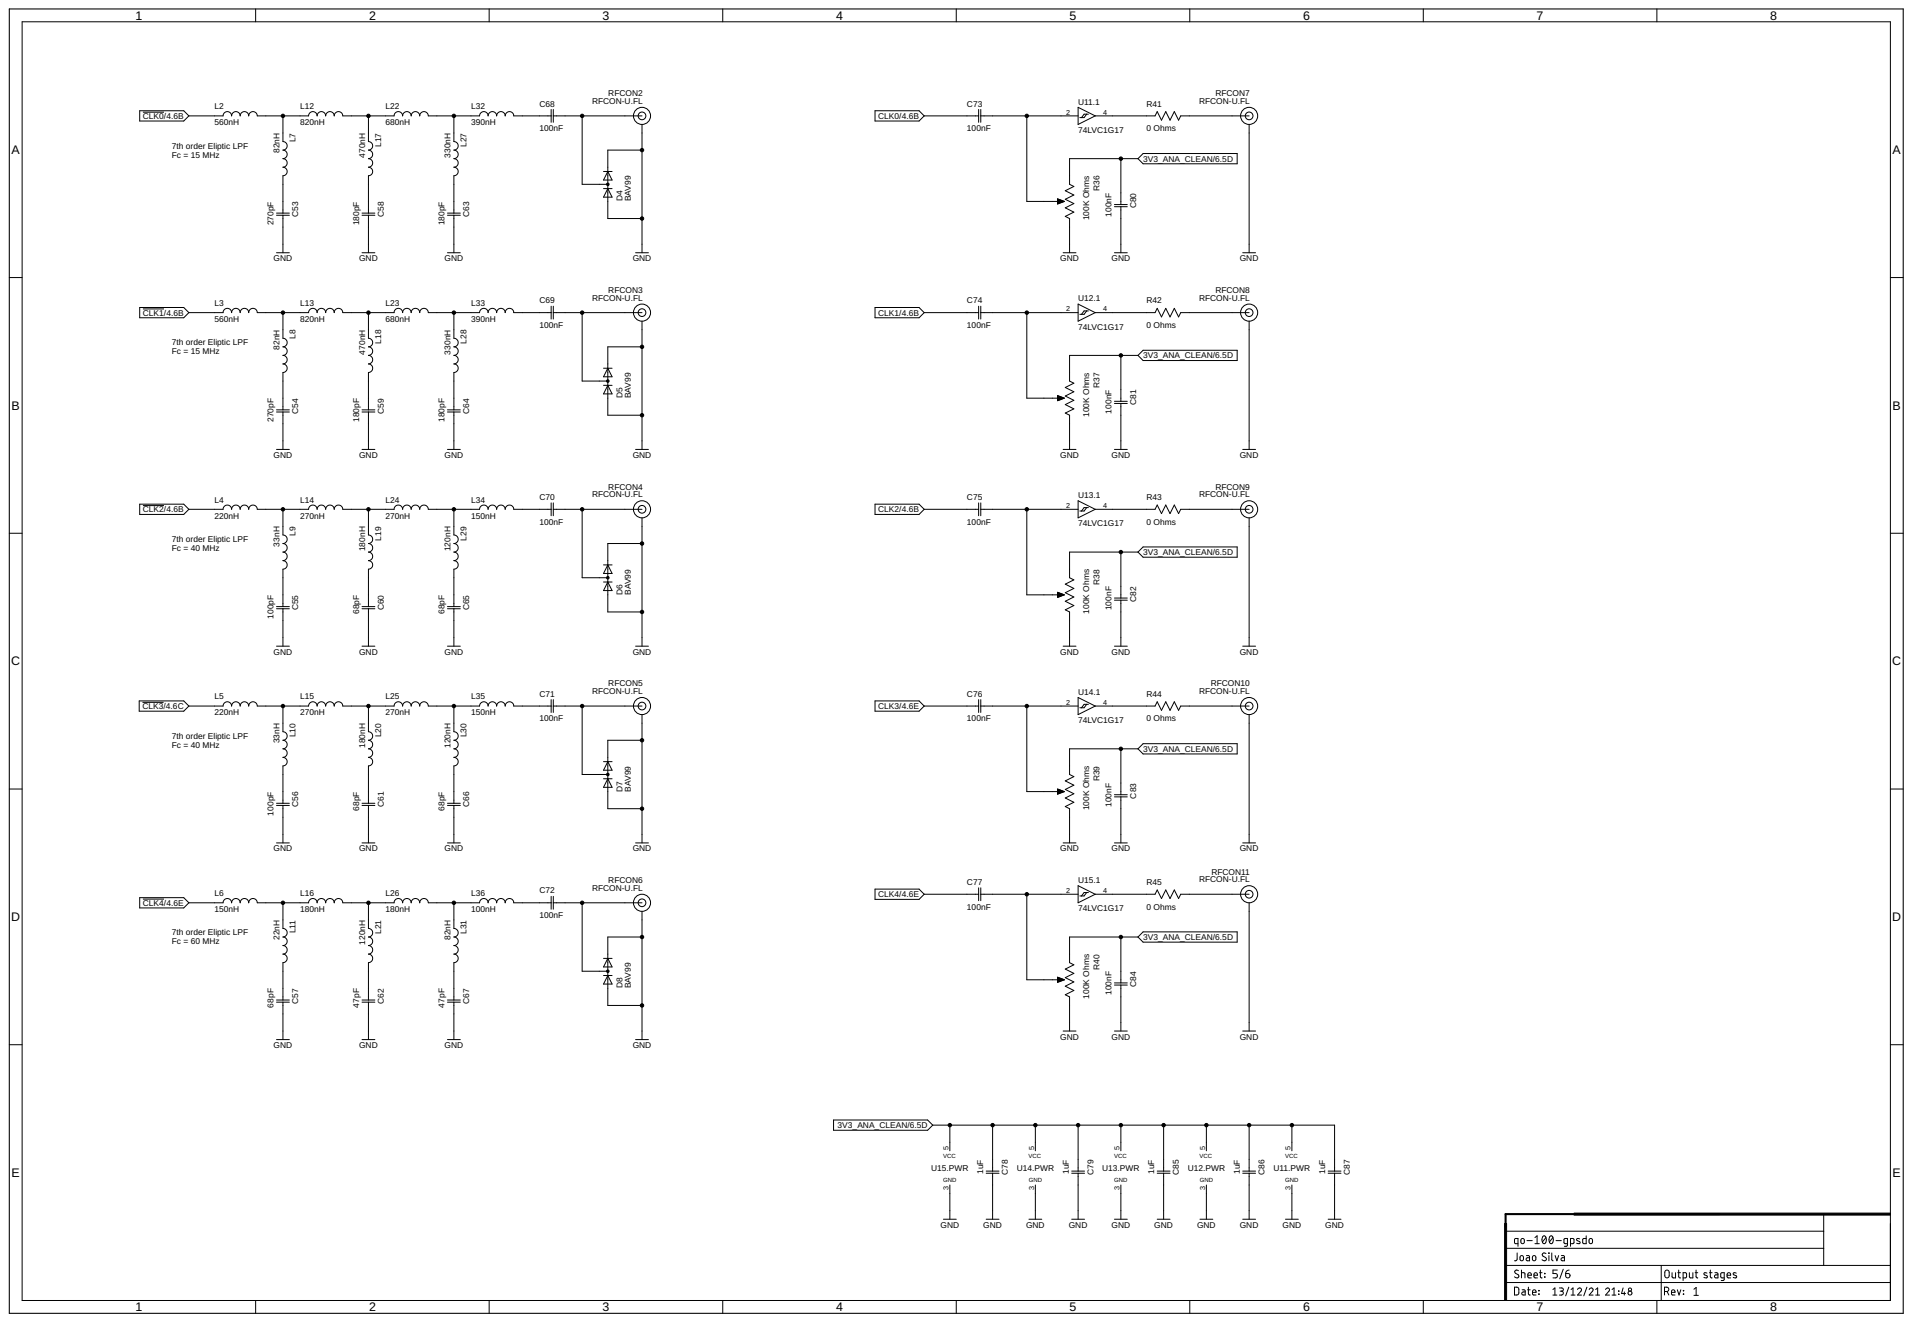
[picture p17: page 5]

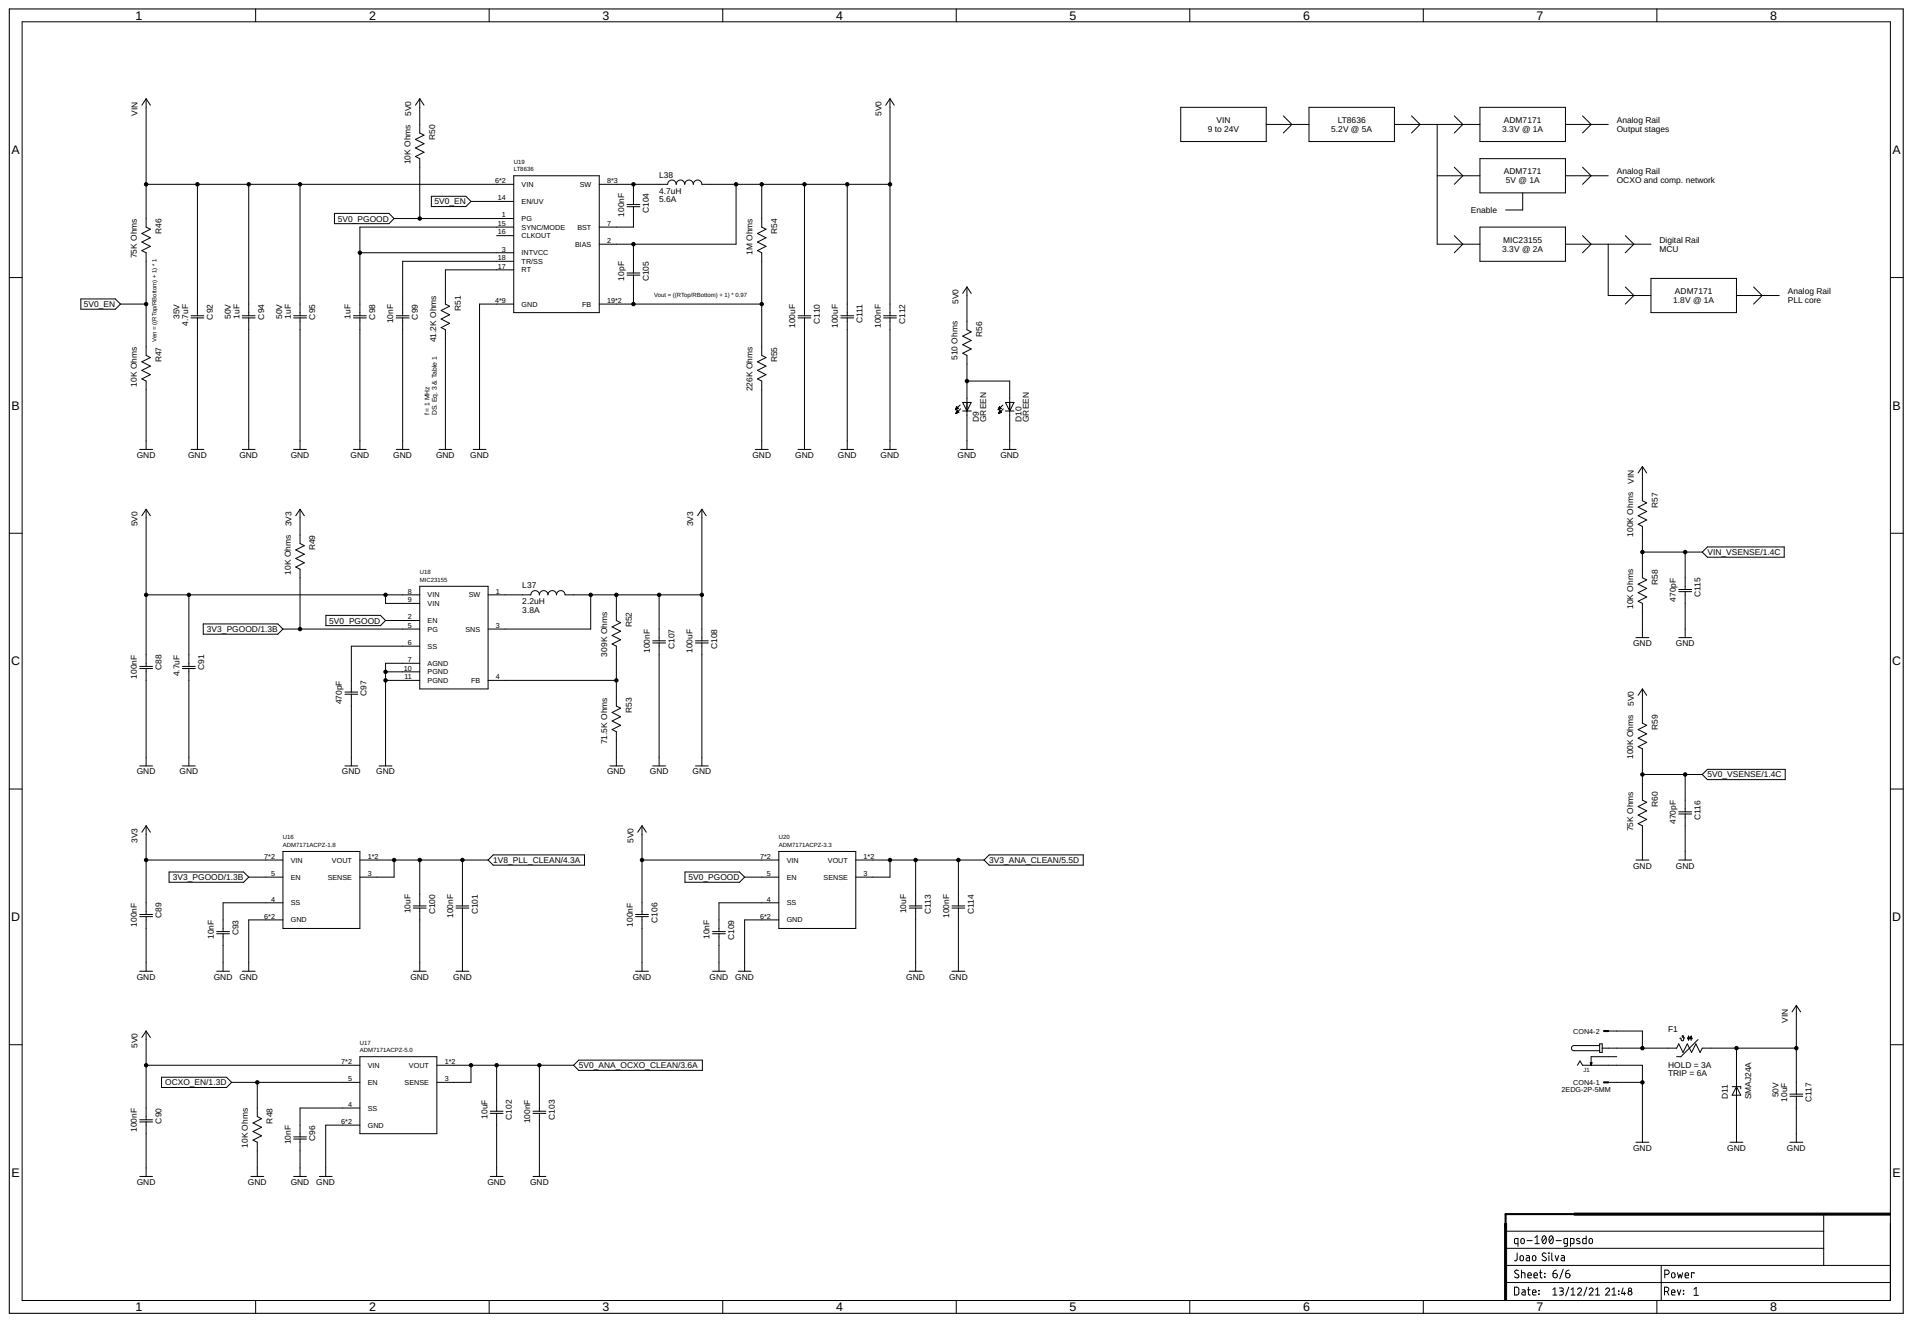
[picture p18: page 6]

Analog Rail
OCXO and comp. network

Vout = ((RTop/RBottom) + 1) * 0.97 Ven = ((RTop/RBottom) + 1) * 1

4.7uF GND GND GND GND GND GND

f = 1 MHz DS. Eq. 3 & Table 1

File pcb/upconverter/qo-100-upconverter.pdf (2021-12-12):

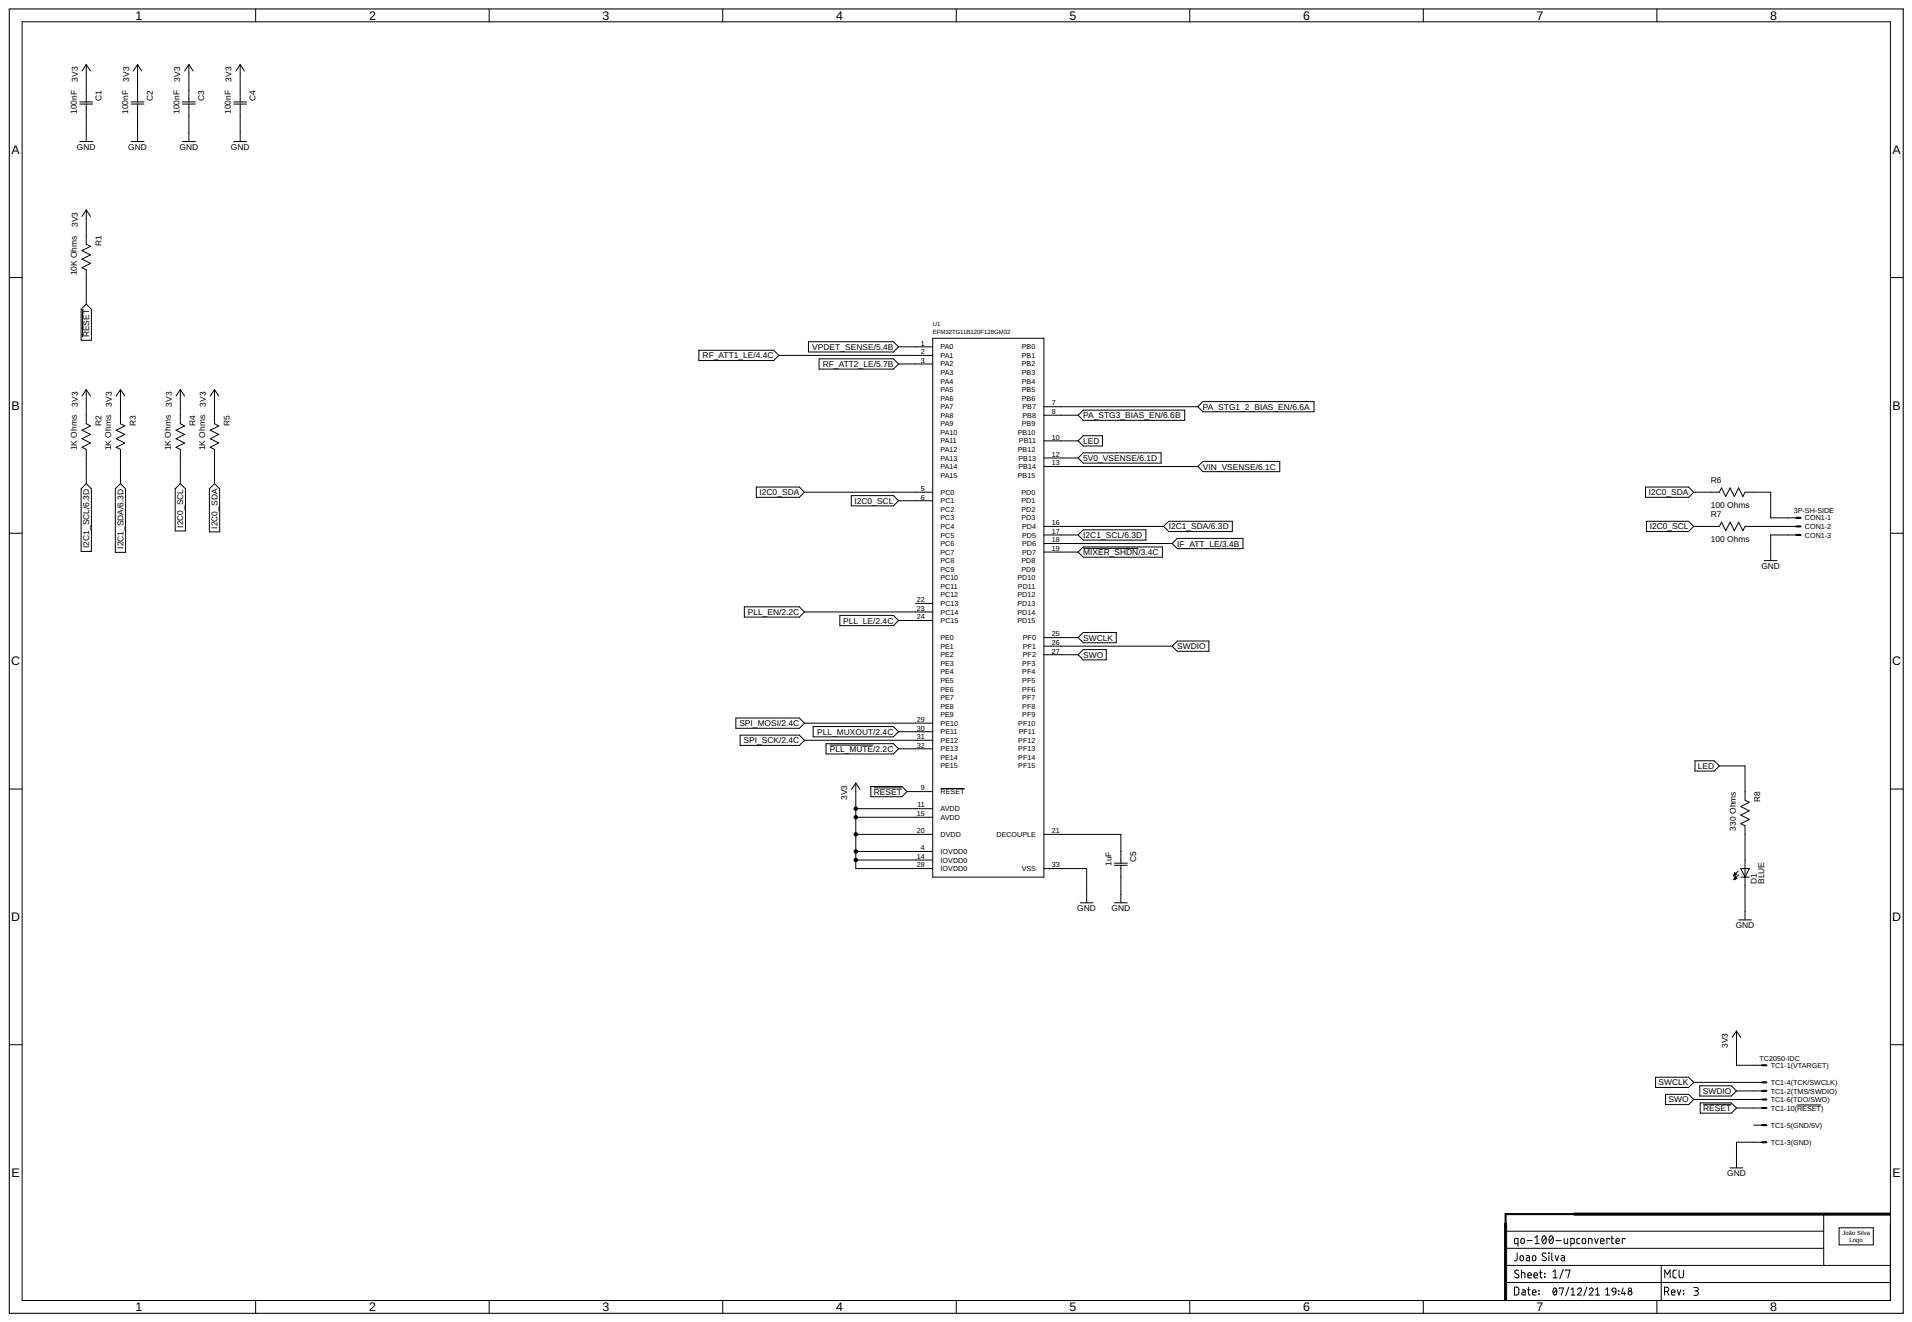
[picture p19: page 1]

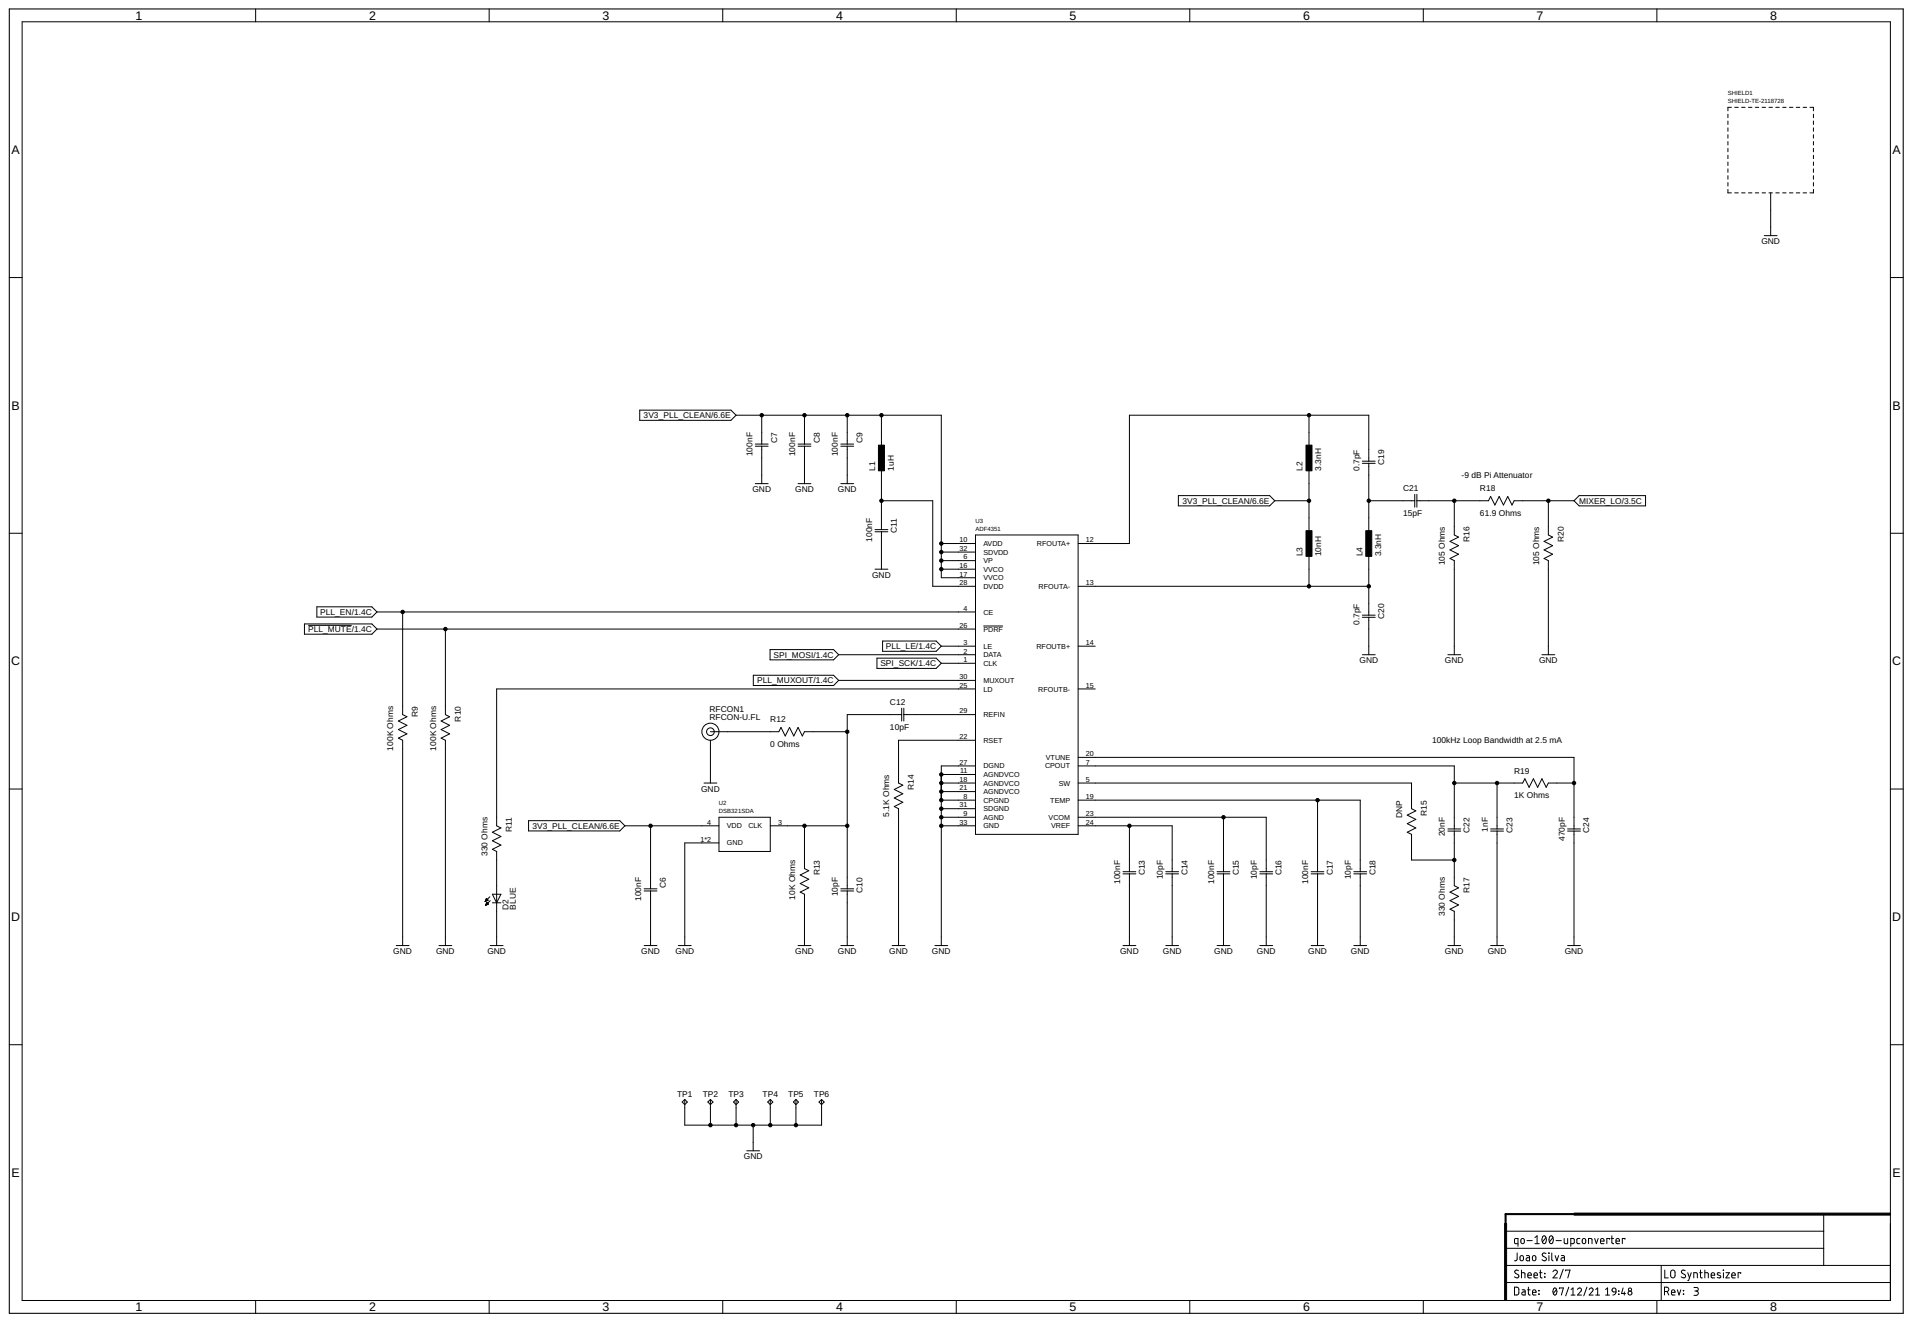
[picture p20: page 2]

100kHz Loop Bandwidth at 2.5 mA

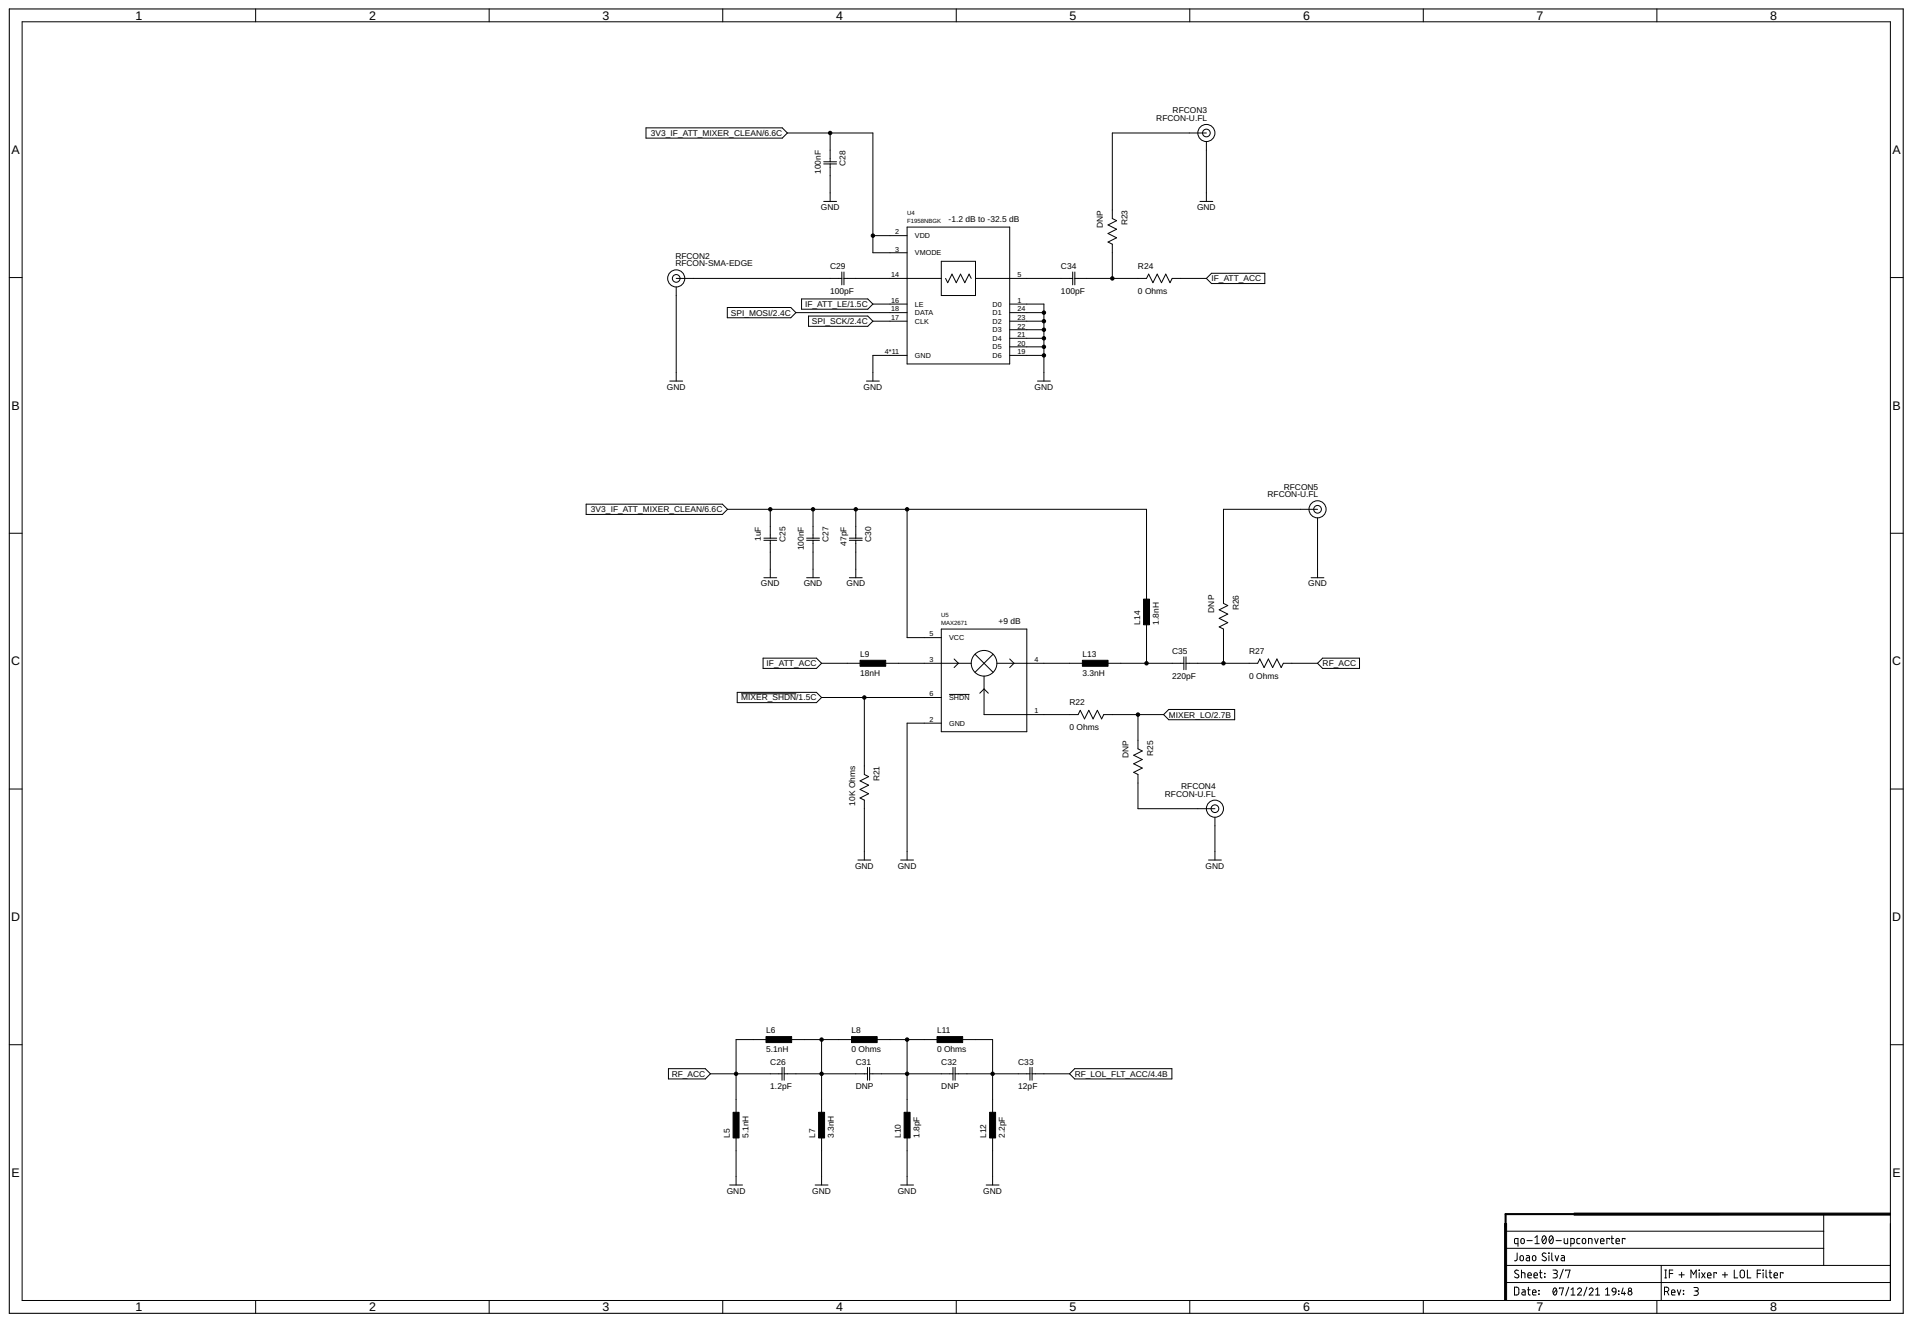
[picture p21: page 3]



100uF GND GND GND GND


4.7uF GND GND GND GND GND GND

f = 1 MHz DS. Eq. 3 & Table 1


RF Attenuators, Power detector ADP150/ADP7142

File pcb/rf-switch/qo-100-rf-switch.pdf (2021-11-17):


Always check PWR_SENSE before asserting PWR_FILTER_EN.
If PWR_SENSE = 1 and PWR_FILTER_EN = 0, external power is applied and PWR_FILTER_EN should NOT be asserted if this is the

case. Doing so will short out both supplies!

Install R4 for F2914
Do not install R4 for F2915

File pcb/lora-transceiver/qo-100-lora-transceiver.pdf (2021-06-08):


10K Ohms TC2050-IDC GND 100nF GND 3V3 3V3 3V3 330 Ohms BLUE GND 100nF GND 3V3 3P-SH-SIDE GND 100 Ohms 100 Ohms 100nF GND 3V3 3V3 GND GND 1uF EFM32TG11B120F128GM32 47K Ohms 3V3 47K Ohms 3V3 R1 TC1-1(VTARGET) TC1-2(TMS/SWDIO) TC1-3(GND) TC1-4(TCK/SWCLK) TC1-5(GND/5V) TC1-6(TDO/SWO) TC1-10(RESET) C1 R6 D1 C2 CON1-1 CON1-2 CON1-3 R4 R5 C3 C4 PA0 1 PA1 2 PB11 10 PB13 12 PB14 13 PC14 23 PC15 24 PD4 16 PD5 17 PD6 18 PD7 19 PF0 25 PF1 26 PF2 27 RESET 9 IOVDD0 4 AVDD 11 DVDD 20 DECOUPLE 21 VSS 33 AVDD 15 PC0 5 PC1 6 PC13 22 PA2 3 PB7 7 PB8 8 PE12 31 PE13 32 PE11 30 PE10 29 IOVDD0 14 IOVDD0 28 U1 R2 R3 SWO SWO SWDIO SWDIO SWCLK SWCLK RESET RESET RESET LED LED I2C0_SDA I2C0_SDA I2C0_SDA I2C0_SCL I2C0_SCL I2C0_SCL VIN_VSENSE/3.1C 5V0_VSENSE/3.2C SPI_MOSI/2.4B SPI_MISO/2.4B SPI_SCK/2.4B LORA_CS/2.4B LORA_DIO5/2.4C LORA_DIO4/2.4C LORA_DIO3/2.4C LORA_DIO2/2.4C LORA_DIO1/2.4C LORA_DIO0/2.4C LORA_RX/TX/2.4C LORA_RESET/2.4B João Silva Logo ABCDE 1 2 3 4 5 6 7 8 ABCDE 1 2 3 4 5 6 7 8 LoRa PC6 PC7 PC8 PC9 PC10 PE0 PA6 PA7 PA9 PA10 PA11 PA13 PA15 PC4 PC5 PC3 PC2 PC12 PC11 PE1 PE2 PE3 PF5 PF13 PF14 PF15 PB10 PB9 PB2 PB1 PB0 PF6 PF7 PF8 PF9 PF10 PF11 PF12 PE5 PE6 PE7 PE4 PE8 PE9 PE14 PE15 PD8 PD9 PD3 PD2 PD1 PD0 PB3 PB4 PB5 PB6 PA14 PA12 PA8 PA5 PA4 PA3 PB12 PB15 PD13 PD14 PD15 PD10 PD11 PD12 PF3 PF4



4.7uF GND GND GND GND GND GND

f = 1 MHz DS. Eq. 3 & Table 1







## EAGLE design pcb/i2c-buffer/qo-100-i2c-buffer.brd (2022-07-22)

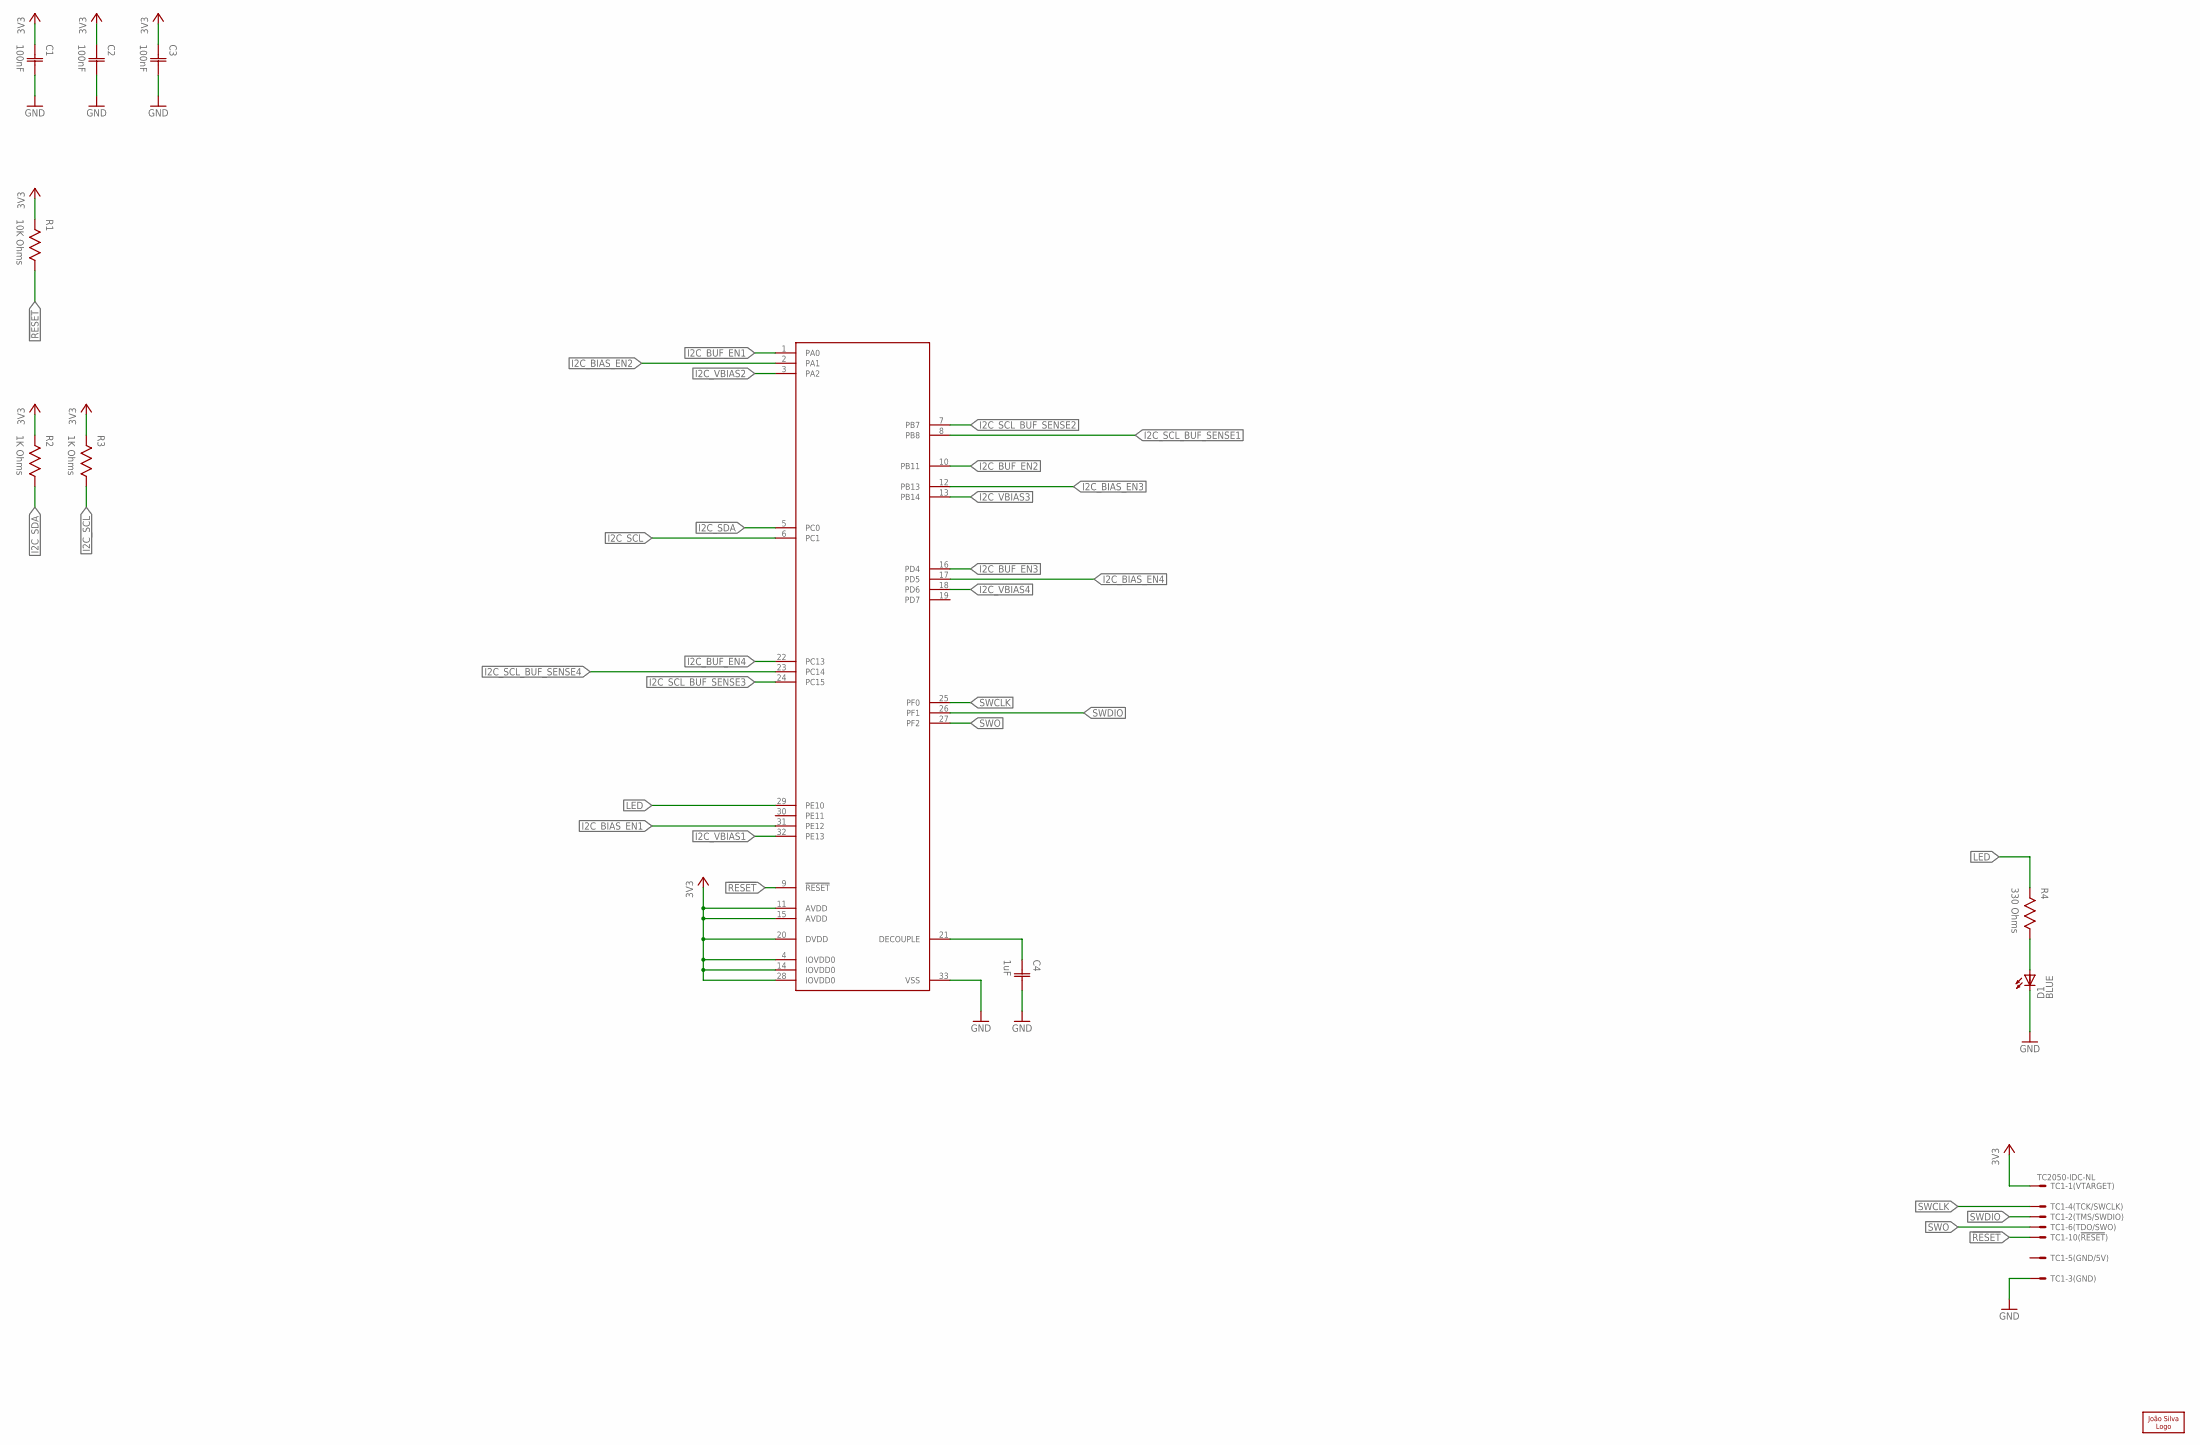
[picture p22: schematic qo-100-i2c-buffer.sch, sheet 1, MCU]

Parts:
C1, C2, C3: 100nF; CAP0402
C4: 1uF; CAP0402
D1: LED0603; 0603
LOGO1: JS-5MM; JS_5MM
R1: 10K Ohms; RES0402
R2, R3: 1K Ohms; RES0402
R4: 330 Ohms; RES0402
TC1: TC2050-IDC-NL
U1: EFM32TG11B120F128GM32; QFN32_0.5P_TG

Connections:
3V3: C1.1 (C1), C2.1 (C1), C3.1 (C1), R1.2, R2.2, R3.2, TC1.1, U1.4 (IOVDD0), U1.11 (AVDD), U1.14 (IOVDD0), U1.15 (AVDD), U1.20 (DVDD), U1.28 (IOVDD0); also elsewhere on the board
!RESET: R1.1, TC1.10, U1.9 (!RESET)
GND: C1.2 (C2), C2.2 (C2), C3.2 (C2), C4.2 (C2), D1.C, TC1.3, U1.33 (VSS); also elsewhere on the board
I2C_BIAS_EN1: U1.31 (PE12); also elsewhere on the board
I2C_BIAS_EN2: U1.2 (PA1); also elsewhere on the board
I2C_BIAS_EN3: U1.12 (PB13); also elsewhere on the board
I2C_BIAS_EN4: U1.17 (PD5); also elsewhere on the board
I2C_BUF_EN1: U1.1 (PA0); also elsewhere on the board
I2C_BUF_EN2: U1.10 (PB11); also elsewhere on the board
I2C_BUF_EN3: U1.16 (PD4); also elsewhere on the board
I2C_BUF_EN4: U1.22 (PC13); also elsewhere on the board
I2C_SCL: R3.1, U1.6 (PC1); also elsewhere on the board
I2C_SCL_BUF_SENSE1: U1.8 (PB8); also elsewhere on the board
I2C_SCL_BUF_SENSE2: U1.7 (PB7); also elsewhere on the board
I2C_SCL_BUF_SENSE3: U1.24 (PC15); also elsewhere on the board
I2C_SCL_BUF_SENSE4: U1.23 (PC14); also elsewhere on the board
I2C_SDA: R2.1, U1.5 (PC0); also elsewhere on the board
I2C_VBIAS1: U1.32 (PE13); also elsewhere on the board
I2C_VBIAS2: U1.3 (PA2); also elsewhere on the board
I2C_VBIAS3: U1.13 (PB14); also elsewhere on the board
I2C_VBIAS4: U1.18 (PD6); also elsewhere on the board
LED: R4.2, U1.29 (PE10)
unnamed: C4.1 (C1), U1.21 (DECOUPLE)
unnamed: D1.A, R4.1
SWCLK: TC1.4, U1.25 (PF0)
SWDIO: TC1.2, U1.26 (PF1)
SWO: TC1.6, U1.27 (PF2)

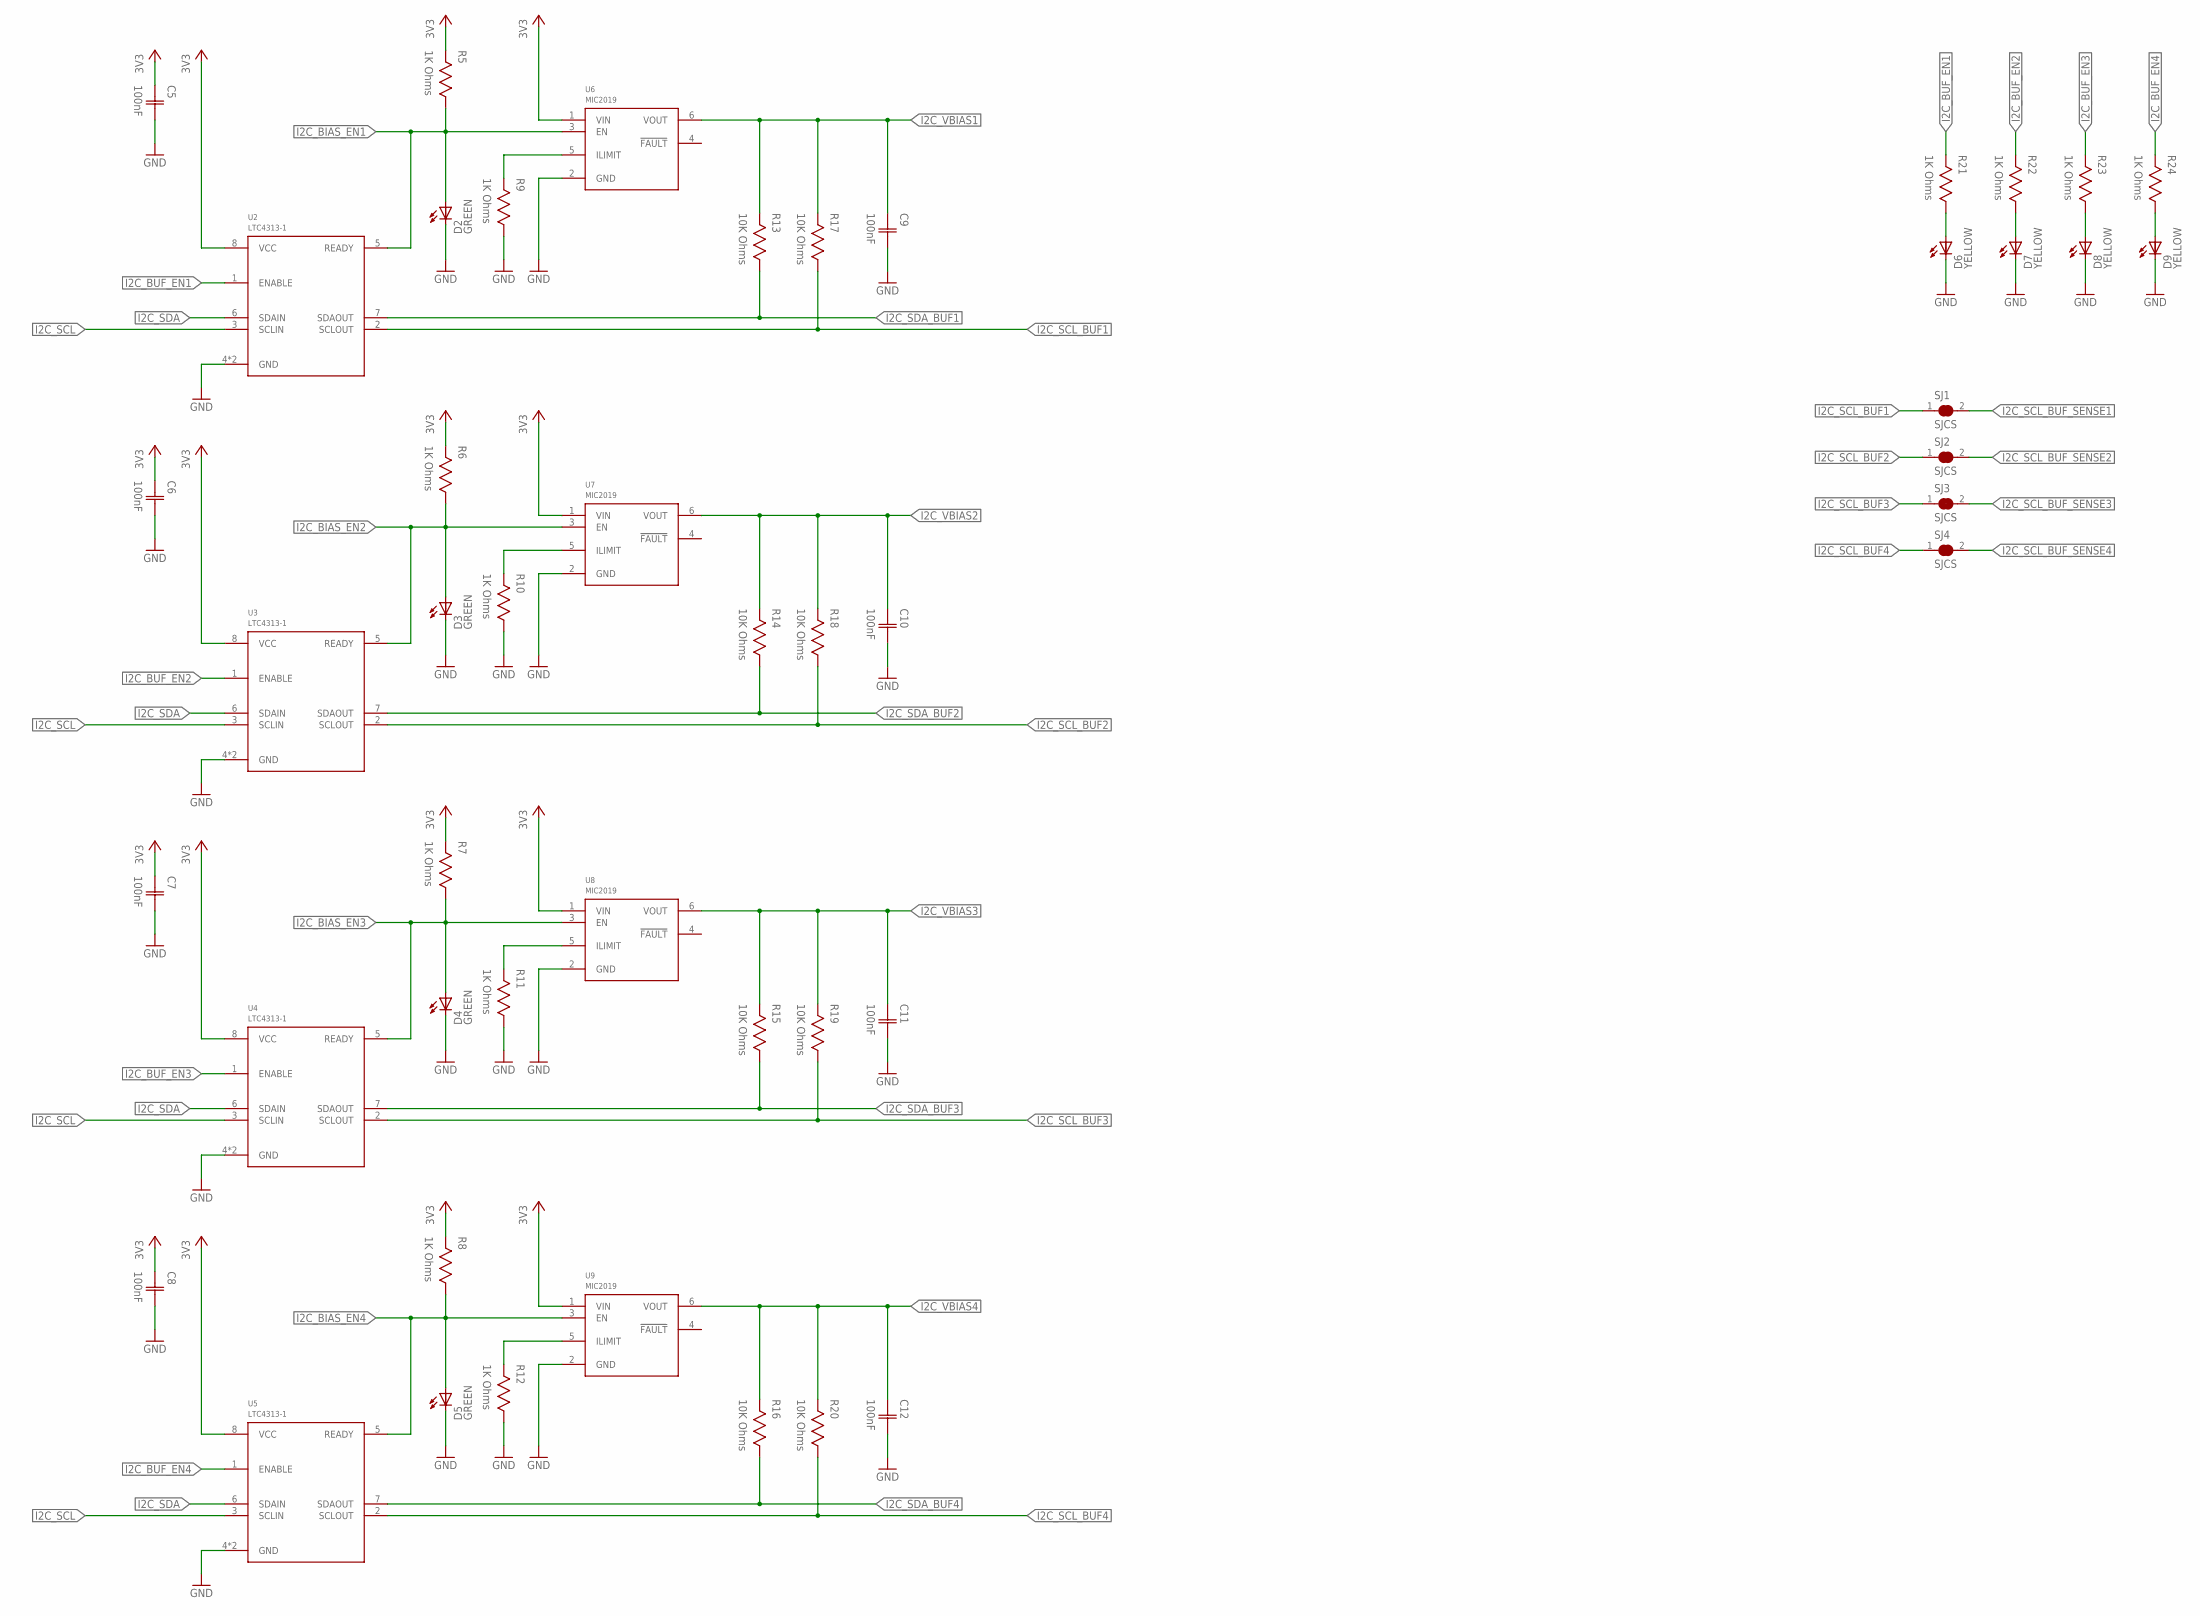
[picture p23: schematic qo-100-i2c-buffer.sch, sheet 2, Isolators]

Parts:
C5, C6, C7, C8, C9, C10, C11, C12: 100nF; CAP0402
D2, D3, D4, D5, D6, D7, D8, D9: LED0603; 0603
R5, R6, R7, R8, R9, R10, R11, R12, R21, R22, R23, R24: 1K Ohms; RES0402
R13, R14, R15, R16, R17, R18, R19, R20: 10K Ohms; RES0402
SJ1, SJ2, SJ3, SJ4: SJCS; SJC_S
U2, U3, U4, U5: LTC4313-1; DFN8
U6, U7, U8, U9: MIC2019; SOT23-6

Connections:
3V3: C5.1 (C1), C6.1 (C1), C7.1 (C1), C8.1 (C1), R5.2, R6.2, R7.2, R8.2, U2.8 (VCC), U3.8 (VCC), U4.8 (VCC), U5.8 (VCC), U6.1 (VIN), U7.1 (VIN), U8.1 (VIN), U9.1 (VIN); also elsewhere on the board
GND: C5.2 (C2), C6.2 (C2), C7.2 (C2), C8.2 (C2), C9.2 (C2), C10.2 (C2), C11.2 (C2), C12.2 (C2), D2.C, D3.C, D4.C, D5.C, D6.C, D7.C, D8.C, D9.C, R9.1, R10.1, R11.1, R12.1, U2.4 (GND), U2.9 (GND), U3.4 (GND), U3.9 (GND), U4.4 (GND), U4.9 (GND), U5.4 (GND), U5.9 (GND), U6.2 (GND), U7.2 (GND), U8.2 (GND), U9.2 (GND); also elsewhere on the board
I2C_BIAS_EN1: D2.A, R5.1, U2.5 (READY), U6.3 (EN); also elsewhere on the board
I2C_BIAS_EN2: D3.A, R6.1, U3.5 (READY), U7.3 (EN); also elsewhere on the board
I2C_BIAS_EN3: D4.A, R7.1, U4.5 (READY), U8.3 (EN); also elsewhere on the board
I2C_BIAS_EN4: D5.A, R8.1, U5.5 (READY), U9.3 (EN); also elsewhere on the board
I2C_BUF_EN1: R21.2, U2.1 (ENABLE); also elsewhere on the board
I2C_BUF_EN2: R22.2, U3.1 (ENABLE); also elsewhere on the board
I2C_BUF_EN3: R23.2, U4.1 (ENABLE); also elsewhere on the board
I2C_BUF_EN4: R24.2, U5.1 (ENABLE); also elsewhere on the board
I2C_SCL: U2.3 (SCLIN), U3.3 (SCLIN), U4.3 (SCLIN), U5.3 (SCLIN); also elsewhere on the board
I2C_SCL_BUF1: R17.1, SJ1.1, U2.2 (SCLOUT); also elsewhere on the board
I2C_SCL_BUF2: R18.1, SJ2.1, U3.2 (SCLOUT); also elsewhere on the board
I2C_SCL_BUF3: R19.1, SJ3.1, U4.2 (SCLOUT); also elsewhere on the board
I2C_SCL_BUF4: R20.1, SJ4.1, U5.2 (SCLOUT); also elsewhere on the board
I2C_SCL_BUF_SENSE1: SJ1.2; also elsewhere on the board
I2C_SCL_BUF_SENSE2: SJ2.2; also elsewhere on the board
I2C_SCL_BUF_SENSE3: SJ3.2; also elsewhere on the board
I2C_SCL_BUF_SENSE4: SJ4.2; also elsewhere on the board
I2C_SDA: U2.6 (SDAIN), U3.6 (SDAIN), U4.6 (SDAIN), U5.6 (SDAIN); also elsewhere on the board
I2C_SDA_BUF1: R13.1, U2.7 (SDAOUT); also elsewhere on the board
I2C_SDA_BUF2: R14.1, U3.7 (SDAOUT); also elsewhere on the board
I2C_SDA_BUF3: R15.1, U4.7 (SDAOUT); also elsewhere on the board
I2C_SDA_BUF4: R16.1, U5.7 (SDAOUT); also elsewhere on the board
I2C_VBIAS1: C9.1 (C1), R13.2, R17.2, U6.6 (VOUT); also elsewhere on the board
I2C_VBIAS2: C10.1 (C1), R14.2, R18.2, U7.6 (VOUT); also elsewhere on the board
I2C_VBIAS3: C11.1 (C1), R15.2, R19.2, U8.6 (VOUT); also elsewhere on the board
I2C_VBIAS4: C12.1 (C1), R16.2, R20.2, U9.6 (VOUT); also elsewhere on the board
unnamed: R9.2, U6.5 (ILIMIT)
unnamed: R10.2, U7.5 (ILIMIT)
unnamed: R11.2, U8.5 (ILIMIT)
unnamed: R12.2, U9.5 (ILIMIT)
unnamed: D6.A, R21.1
unnamed: D7.A, R22.1
unnamed: D8.A, R23.1
unnamed: D9.A, R24.1

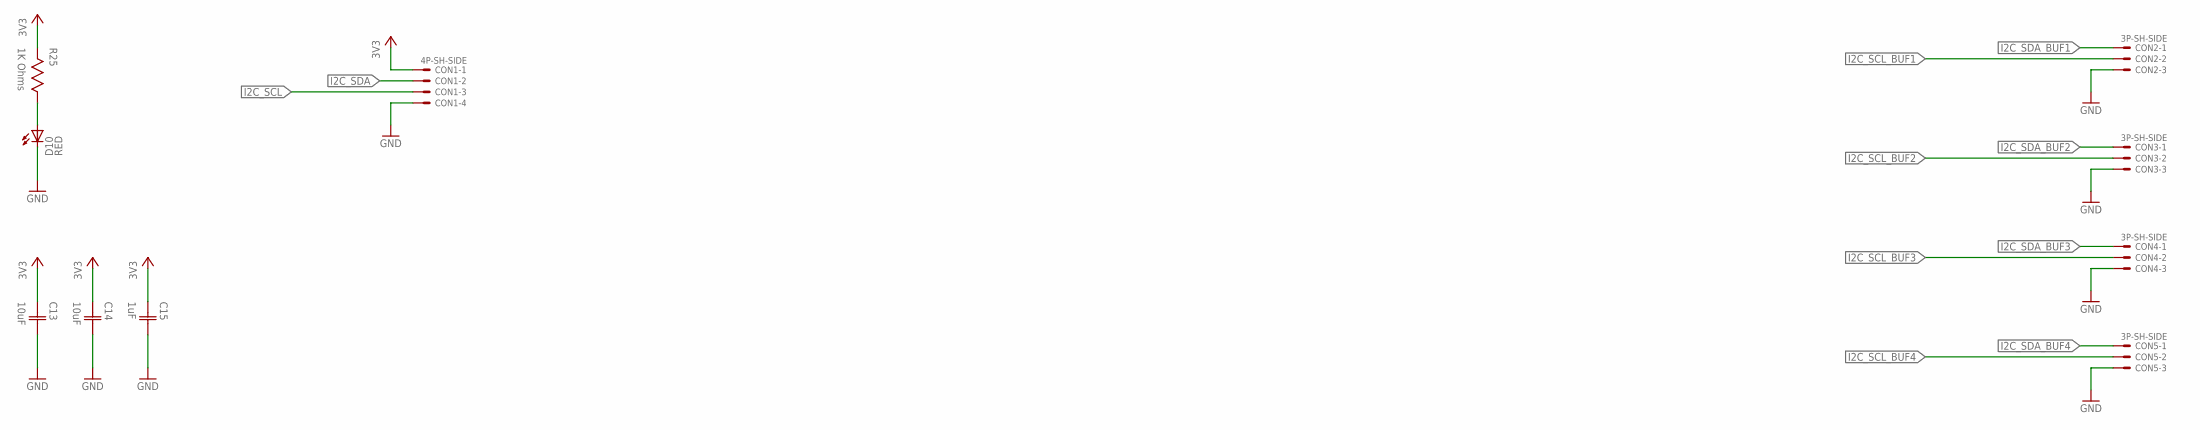
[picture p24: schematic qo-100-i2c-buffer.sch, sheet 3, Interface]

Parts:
C13, C14: 10uF; CAP0603
C15: 1uF; CAP0402
CON1: 4P-SH-SIDE; SH-04-SIDE
CON2, CON3, CON4, CON5: 3P-SH-SIDE; SH-03-SIDE
D10: LED0603; 0603
R25: 1K Ohms; RES0402

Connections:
3V3: C13.1 (C1), C14.1 (C1), C15.1 (C1), CON1.1, R25.2; also elsewhere on the board
GND: C13.2 (C2), C14.2 (C2), C15.2 (C2), CON1.4, CON2.3, CON3.3, CON4.3, CON5.3, D10.C; also elsewhere on the board
I2C_SCL: CON1.3; also elsewhere on the board
I2C_SCL_BUF1: CON2.2; also elsewhere on the board
I2C_SCL_BUF2: CON3.2; also elsewhere on the board
I2C_SCL_BUF3: CON4.2; also elsewhere on the board
I2C_SCL_BUF4: CON5.2; also elsewhere on the board
I2C_SDA: CON1.2; also elsewhere on the board
I2C_SDA_BUF1: CON2.1; also elsewhere on the board
I2C_SDA_BUF2: CON3.1; also elsewhere on the board
I2C_SDA_BUF3: CON4.1; also elsewhere on the board
I2C_SDA_BUF4: CON5.1; also elsewhere on the board
unnamed: D10.A, R25.1

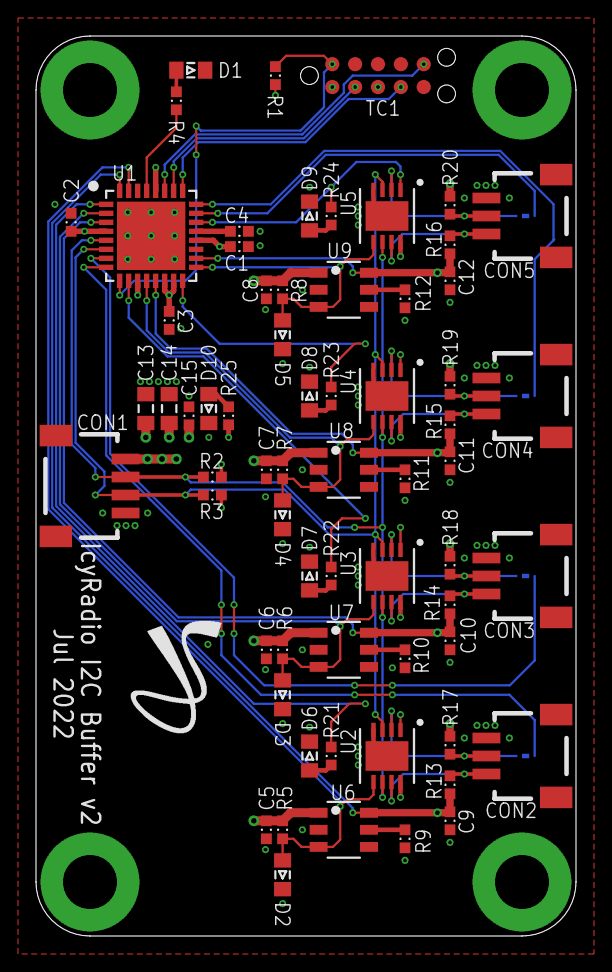
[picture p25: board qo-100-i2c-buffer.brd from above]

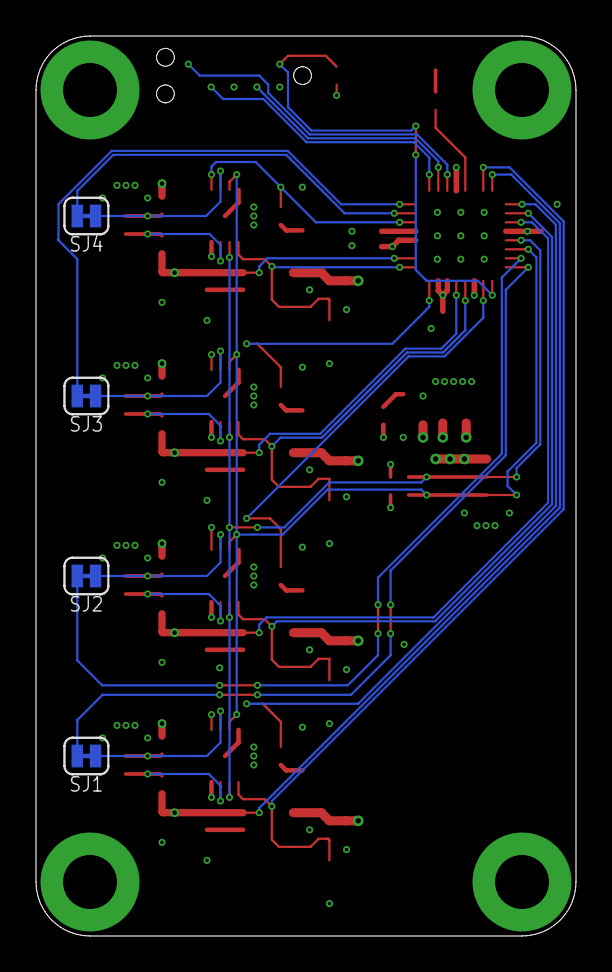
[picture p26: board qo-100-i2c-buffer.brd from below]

Board: 4 copper layers, 30.0 x 50.0 mm, 70 parts (4 on the bottom side), 44 nets.

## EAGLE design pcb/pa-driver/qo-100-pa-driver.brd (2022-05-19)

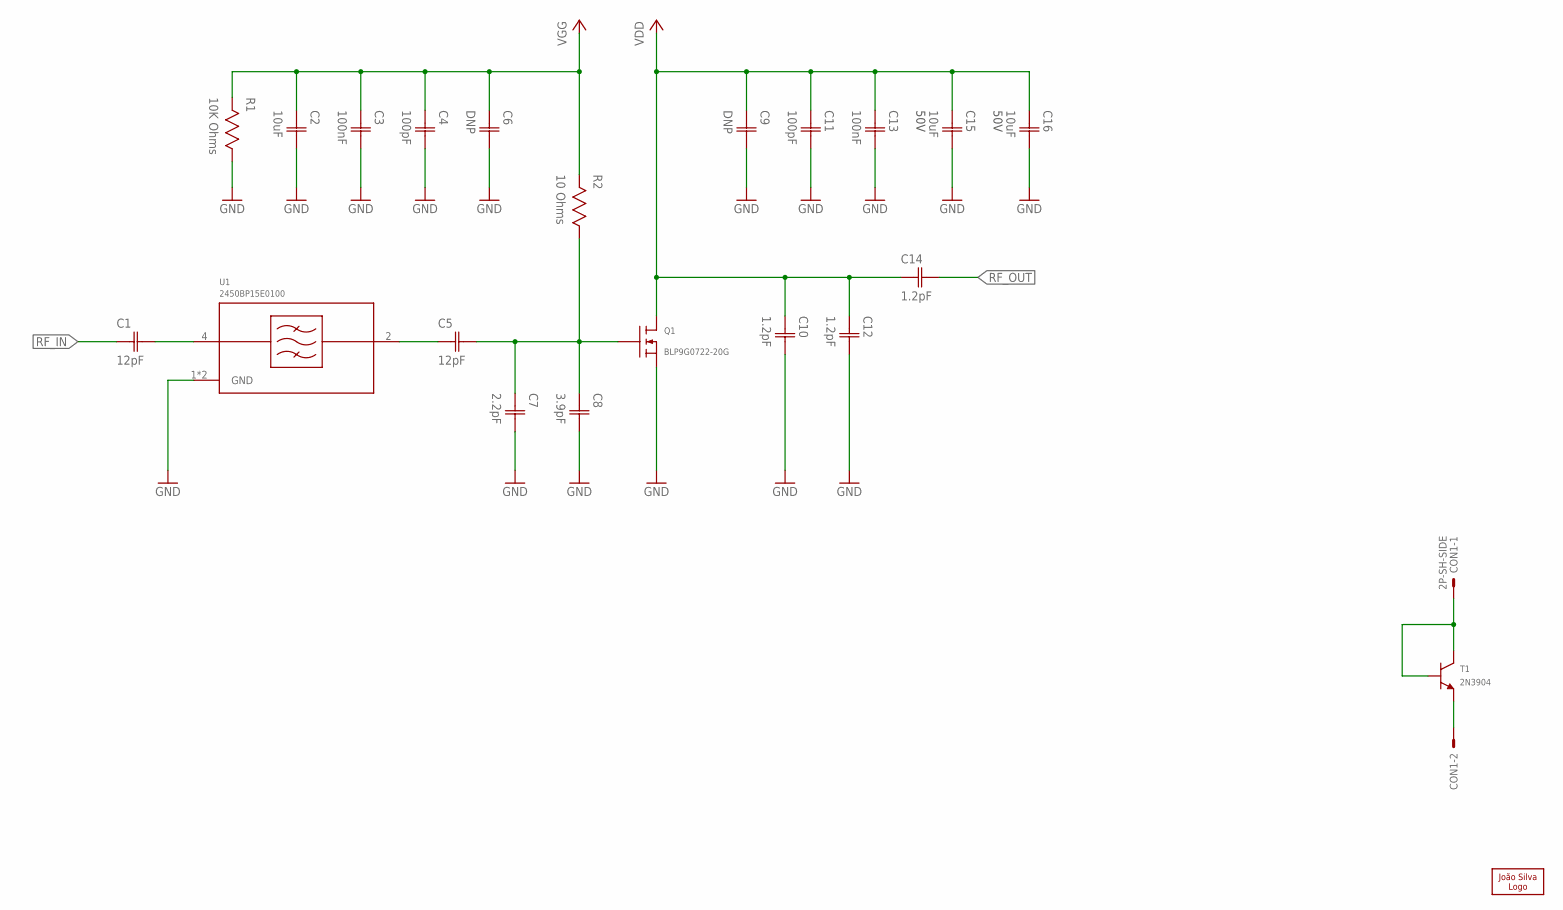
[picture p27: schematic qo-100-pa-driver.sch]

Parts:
C1, C5: 12pF; CAP0603
C2: 10uF; CAP0603
C3, C13: 100nF; CAP0603
C4, C11: 100pF; CAP0603
C6, C9: DNP; CAP0603
C7: 2.2pF; CAP0603
C8: 3.9pF; CAP0603
C10, C12, C14: 1.2pF; CAP0603
C15, C16: 10uF; CAP1206; VOLTAGE 50V
CON1: 2P-SH-SIDE; SH-02-SIDE
LOGO1: JS-5MM; JS_5MM
Q1: BLP9G0722-20G; SOT1483-1
R1: 10K Ohms; RES0603
R2: 10 Ohms; RES0603
T1: 2N3904; SOT23
U1: 2450BP15E0100

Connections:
GND: C2.2 (C2), C3.2 (C2), C4.2 (C2), C6.2 (C2), C7.2 (C2), C8.2 (C2), C9.2 (C2), C10.2 (C2), C11.2 (C2), C12.2 (C2), C13.2 (C2), C15.2 (C2), C16.2 (C2), Q1.3@0 (S), Q1.3@1 (S), Q1.3@2 (S), R1.1, U1.1 (GND), U1.3 (GND)
unnamed: CON1.2, T1.2 (E)
unnamed: C5.2 (C2), C7.1 (C1), C8.1 (C1), Q1.2 (G), R2.1
unnamed: CON1.1, T1.1 (B), T1.3 (C)
unnamed: C5.1 (C1), U1.2 (RFOUT)
unnamed: C1.2 (C2), U1.4 (RFIN)
RF_IN: C1.1 (C1)
RF_OUT: C14.2 (C2)
VDD: C9.1 (C1), C10.1 (C1), C11.1 (C1), C12.1 (C1), C13.1 (C1), C14.1 (C1), C15.1 (C1), C16.1 (C1), Q1.1 (D)
VGG: C2.1 (C1), C3.1 (C1), C4.1 (C1), C6.1 (C1), R1.2, R2.2

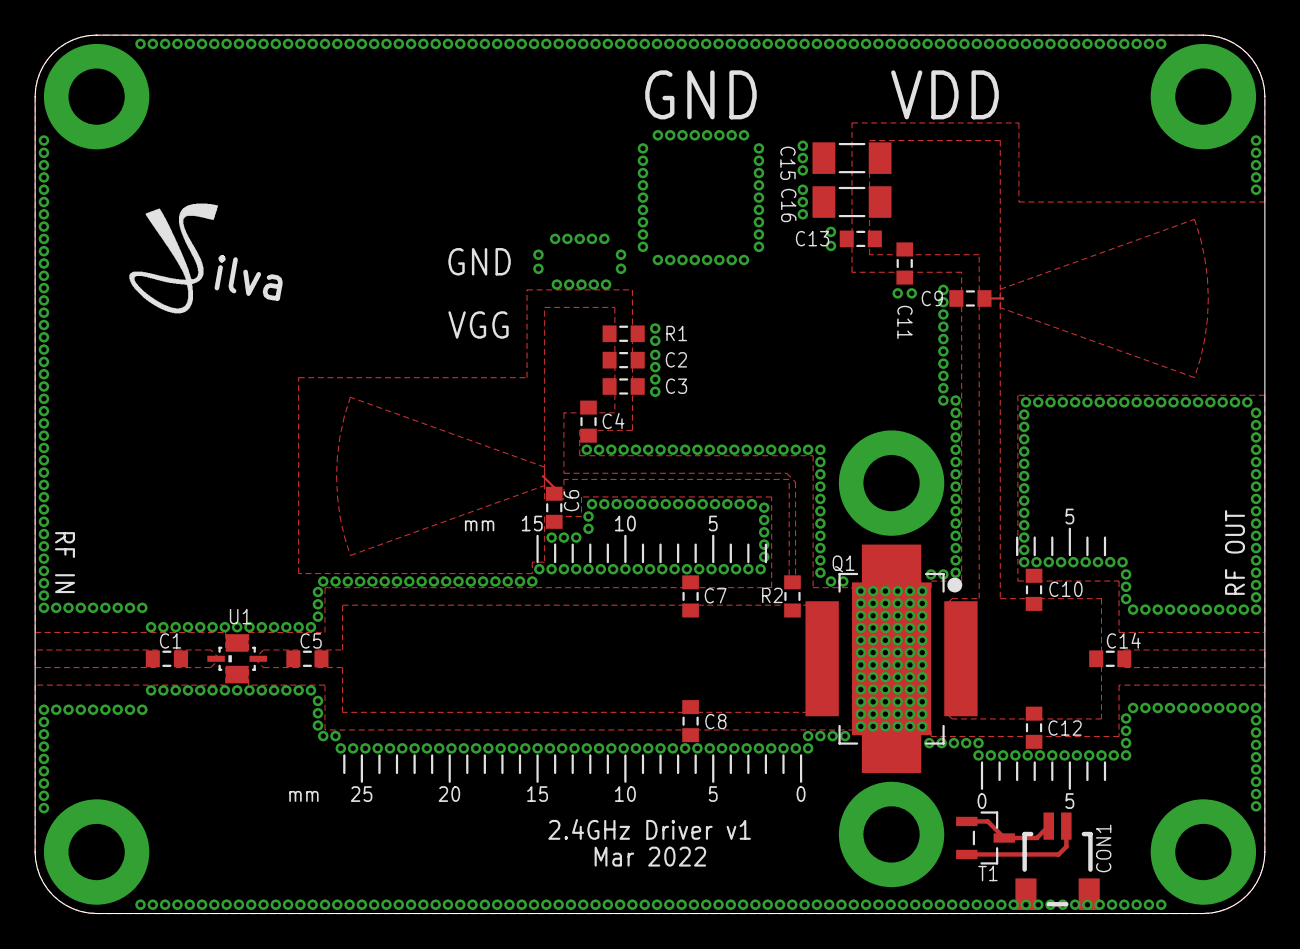
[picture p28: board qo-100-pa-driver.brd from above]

Board: 2 copper layers, 70.0 x 50.0 mm, 23 parts (0 on the bottom side), 8 nets.

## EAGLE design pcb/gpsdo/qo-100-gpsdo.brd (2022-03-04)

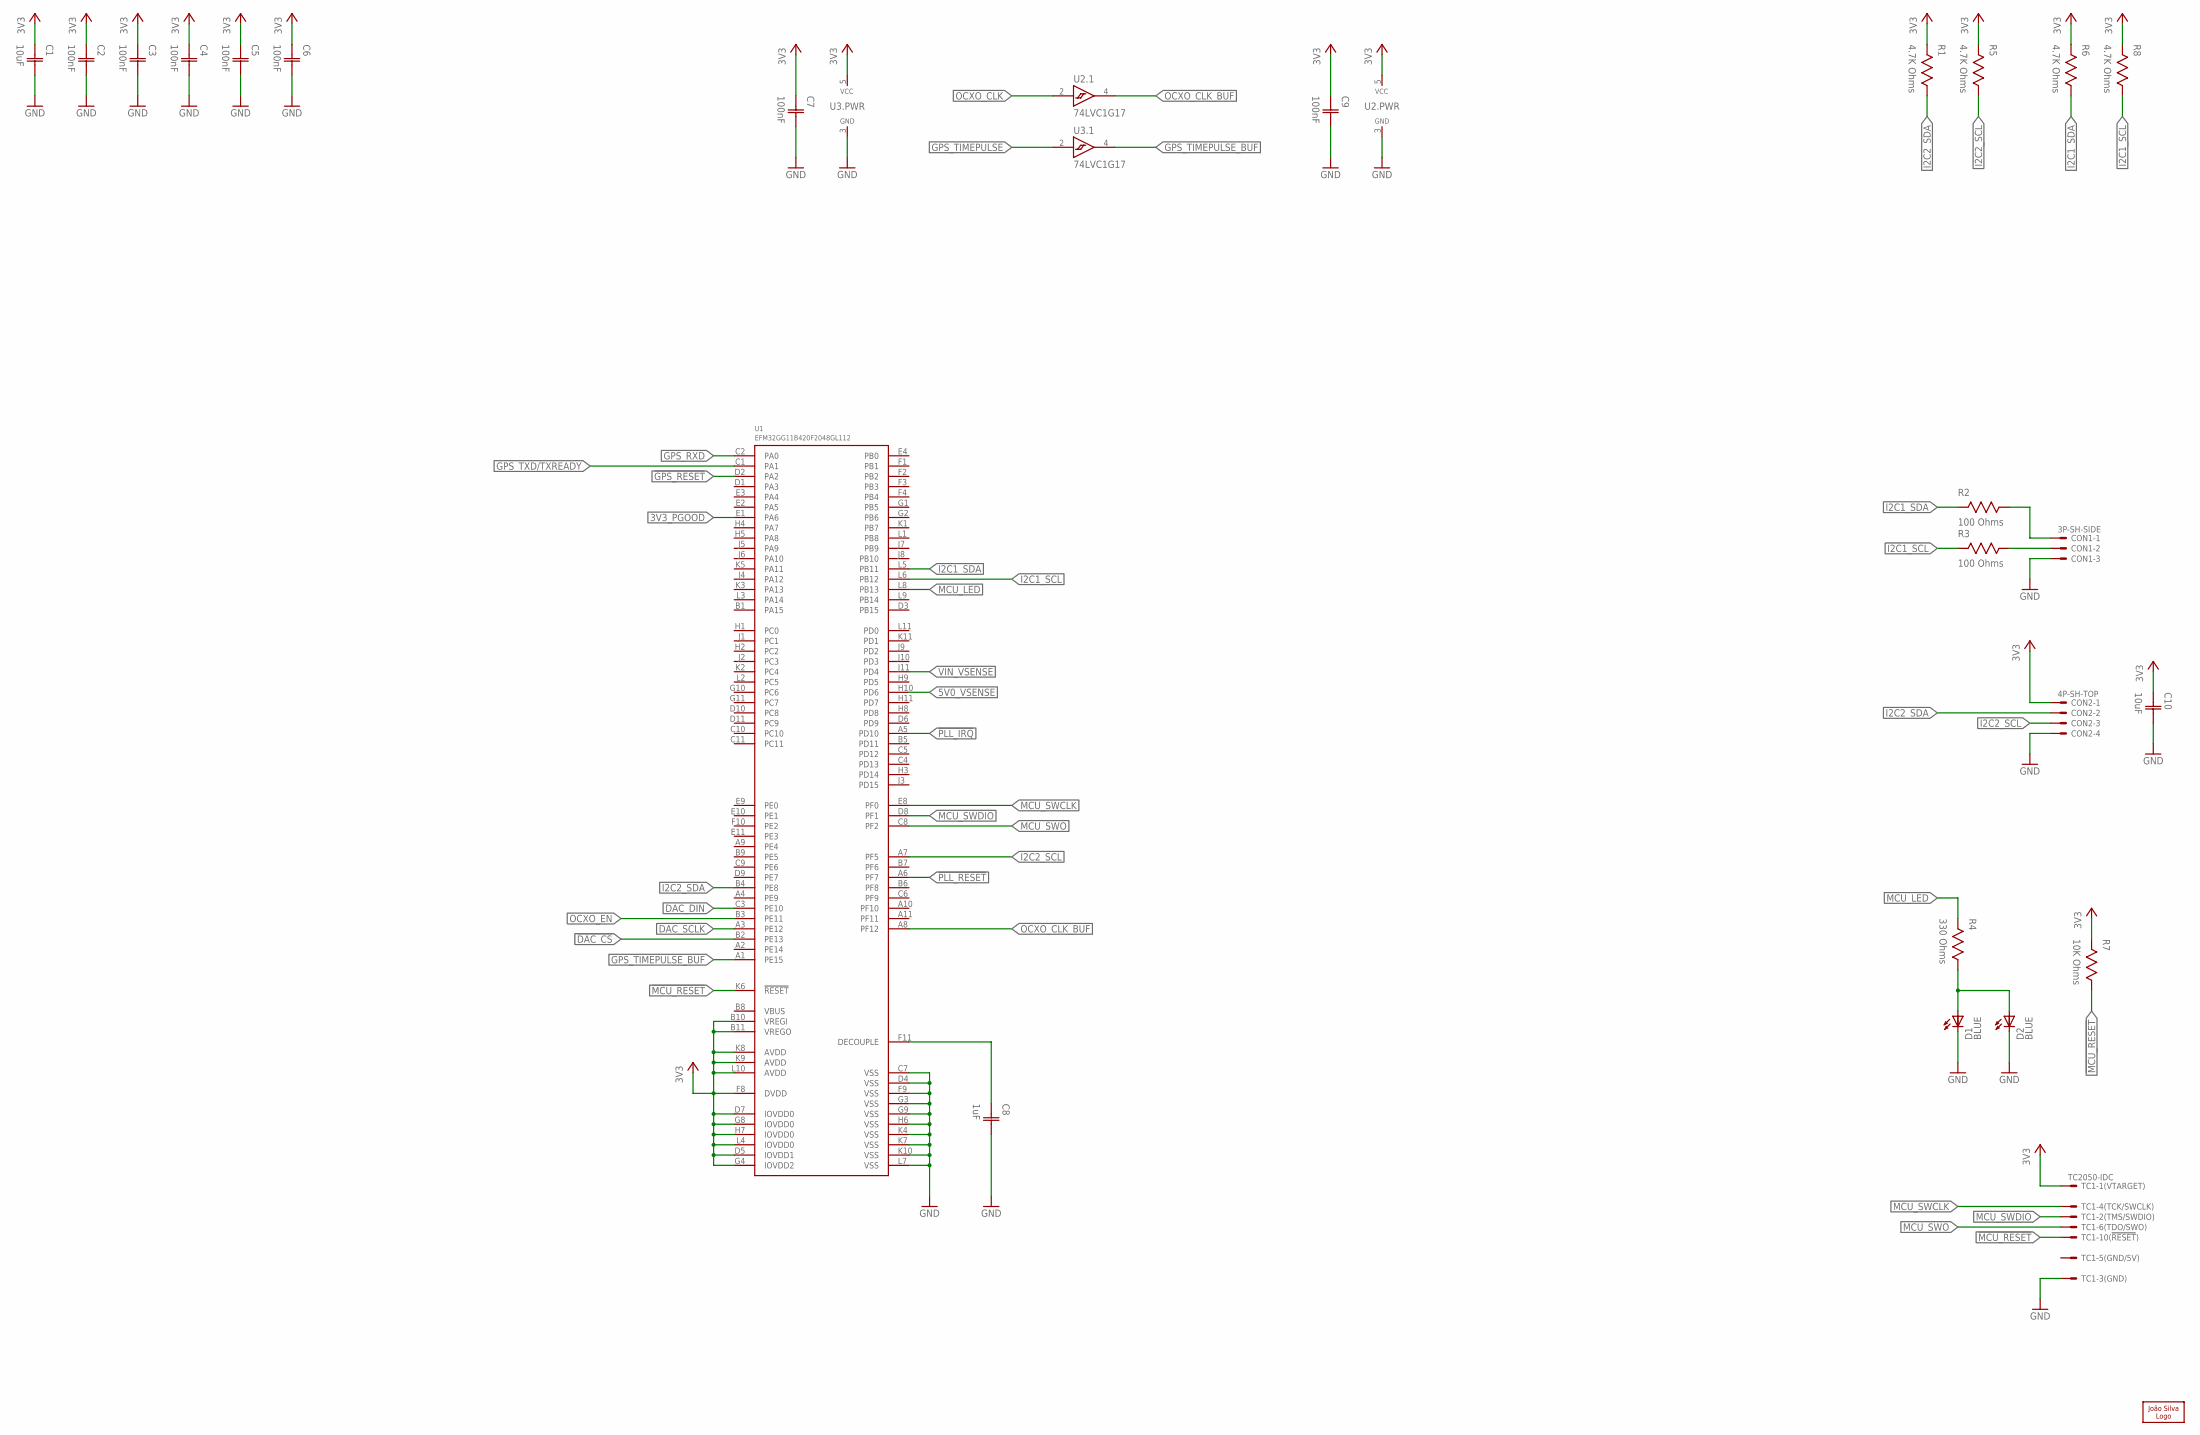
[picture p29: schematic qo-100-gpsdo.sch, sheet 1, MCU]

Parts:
C1, C10: 10uF; CAP0603
C2, C3, C4, C5, C6, C7, C9: 100nF; CAP0402
C8: 1uF; CAP0402
CON1: 3P-SH-SIDE; SH-03-SIDE
CON2: 4P-SH-TOP; SH-04-TOP
D1: LED0603; 0603
D2: LEDTH3MM; LED_3MM
LOGO1: JS-5MM; JS_5MM
R1, R5, R6, R8: 4.7K Ohms; RES0402
R2, R3: 100 Ohms; RES0402
R4: 330 Ohms; RES0402
R7: 10K Ohms; RES0402
TC1: TC2050-IDC
U1: EFM32GG11B420F2048GL112; BGA112
U2, U3: 74LVC1G17; SC70-5

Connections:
3V3: C1.1 (C1), C2.1 (C1), C3.1 (C1), C4.1 (C1), C5.1 (C1), C6.1 (C1), C7.1 (C1), C9.1 (C1), C10.1 (C1), CON2.1, R1.2, R5.2, R6.2, R7.2, R8.2, TC1.1, U1.B10 (VREGI), U1.B11 (VREGO), U1.D5 (IOVDD1), U1.D7 (IOVDD0), U1.F8 (DVDD), U1.G4 (IOVDD2), U1.G8 (IOVDD0), U1.H7 (IOVDD0), U1.K8 (AVDD), U1.K9 (AVDD), U1.L4 (IOVDD0), U1.L10 (AVDD), U2.5 (VCC), U3.5 (VCC); also elsewhere on the board
3V3_PGOOD: U1.E1 (PA6); also elsewhere on the board
5V0_VSENSE: U1.H10 (PD6); also elsewhere on the board
!DAC_CS: U1.B2 (PE13); also elsewhere on the board
!GPS_RESET: U1.D2 (PA2); also elsewhere on the board
!MCU_RESET: R7.1, TC1.10, U1.K6 (!RESET)
!PLL_IRQ: U1.A5 (PD10); also elsewhere on the board
!PLL_RESET: U1.A6 (PF7); also elsewhere on the board
DAC_DIN: U1.C3 (PE10); also elsewhere on the board
DAC_SCLK: U1.A3 (PE12); also elsewhere on the board
GND: C1.2 (C2), C2.2 (C2), C3.2 (C2), C4.2 (C2), C5.2 (C2), C6.2 (C2), C7.2 (C2), C8.2 (C2), C9.2 (C2), C10.2 (C2), CON1.3, CON2.4, D1.C, D2.K (C), TC1.3, U1.C7 (VSS), U1.D4 (VSS), U1.F9 (VSS), U1.G3 (VSS), U1.G9 (VSS), U1.H6 (VSS), U1.K4 (VSS), U1.K7 (VSS), U1.K10 (VSS), U1.L7 (VSS), U2.3 (GND), U3.3 (GND); also elsewhere on the board
GPS_RXD: U1.C2 (PA0); also elsewhere on the board
GPS_TIMEPULSE: U3.2 (A); also elsewhere on the board
GPS_TIMEPULSE_BUF: U1.A1 (PE15), U3.4 (Y)
GPS_TXD/TXREADY: U1.C1 (PA1); also elsewhere on the board
I2C1_SCL: R3.2, R8.1, U1.L6 (PB12)
I2C1_SDA: R2.2, R6.1, U1.L5 (PB11)
I2C2_SCL: CON2.3, R5.1, U1.A7 (PF5); also elsewhere on the board
I2C2_SDA: CON2.2, R1.1, U1.B4 (PE8); also elsewhere on the board
MCU_LED: R4.2, U1.L8 (PB13)
MCU_SWCLK: TC1.4, U1.E8 (PF0)
MCU_SWDIO: TC1.2, U1.D8 (PF1)
MCU_SWO: TC1.6, U1.C8 (PF2)
MCU_VCORE: C8.1 (C1), U1.F11 (DECOUPLE)
unnamed: CON1.2, R3.1
unnamed: CON1.1, R2.1
unnamed: D1.A, D2.A, R4.1
OCXO_CLK: U2.2 (A); also elsewhere on the board
OCXO_CLK_BUF: U1.A8 (PF12), U2.4 (Y)
OCXO_EN: U1.B3 (PE11); also elsewhere on the board
VIN_VSENSE: U1.J11 (PD4); also elsewhere on the board

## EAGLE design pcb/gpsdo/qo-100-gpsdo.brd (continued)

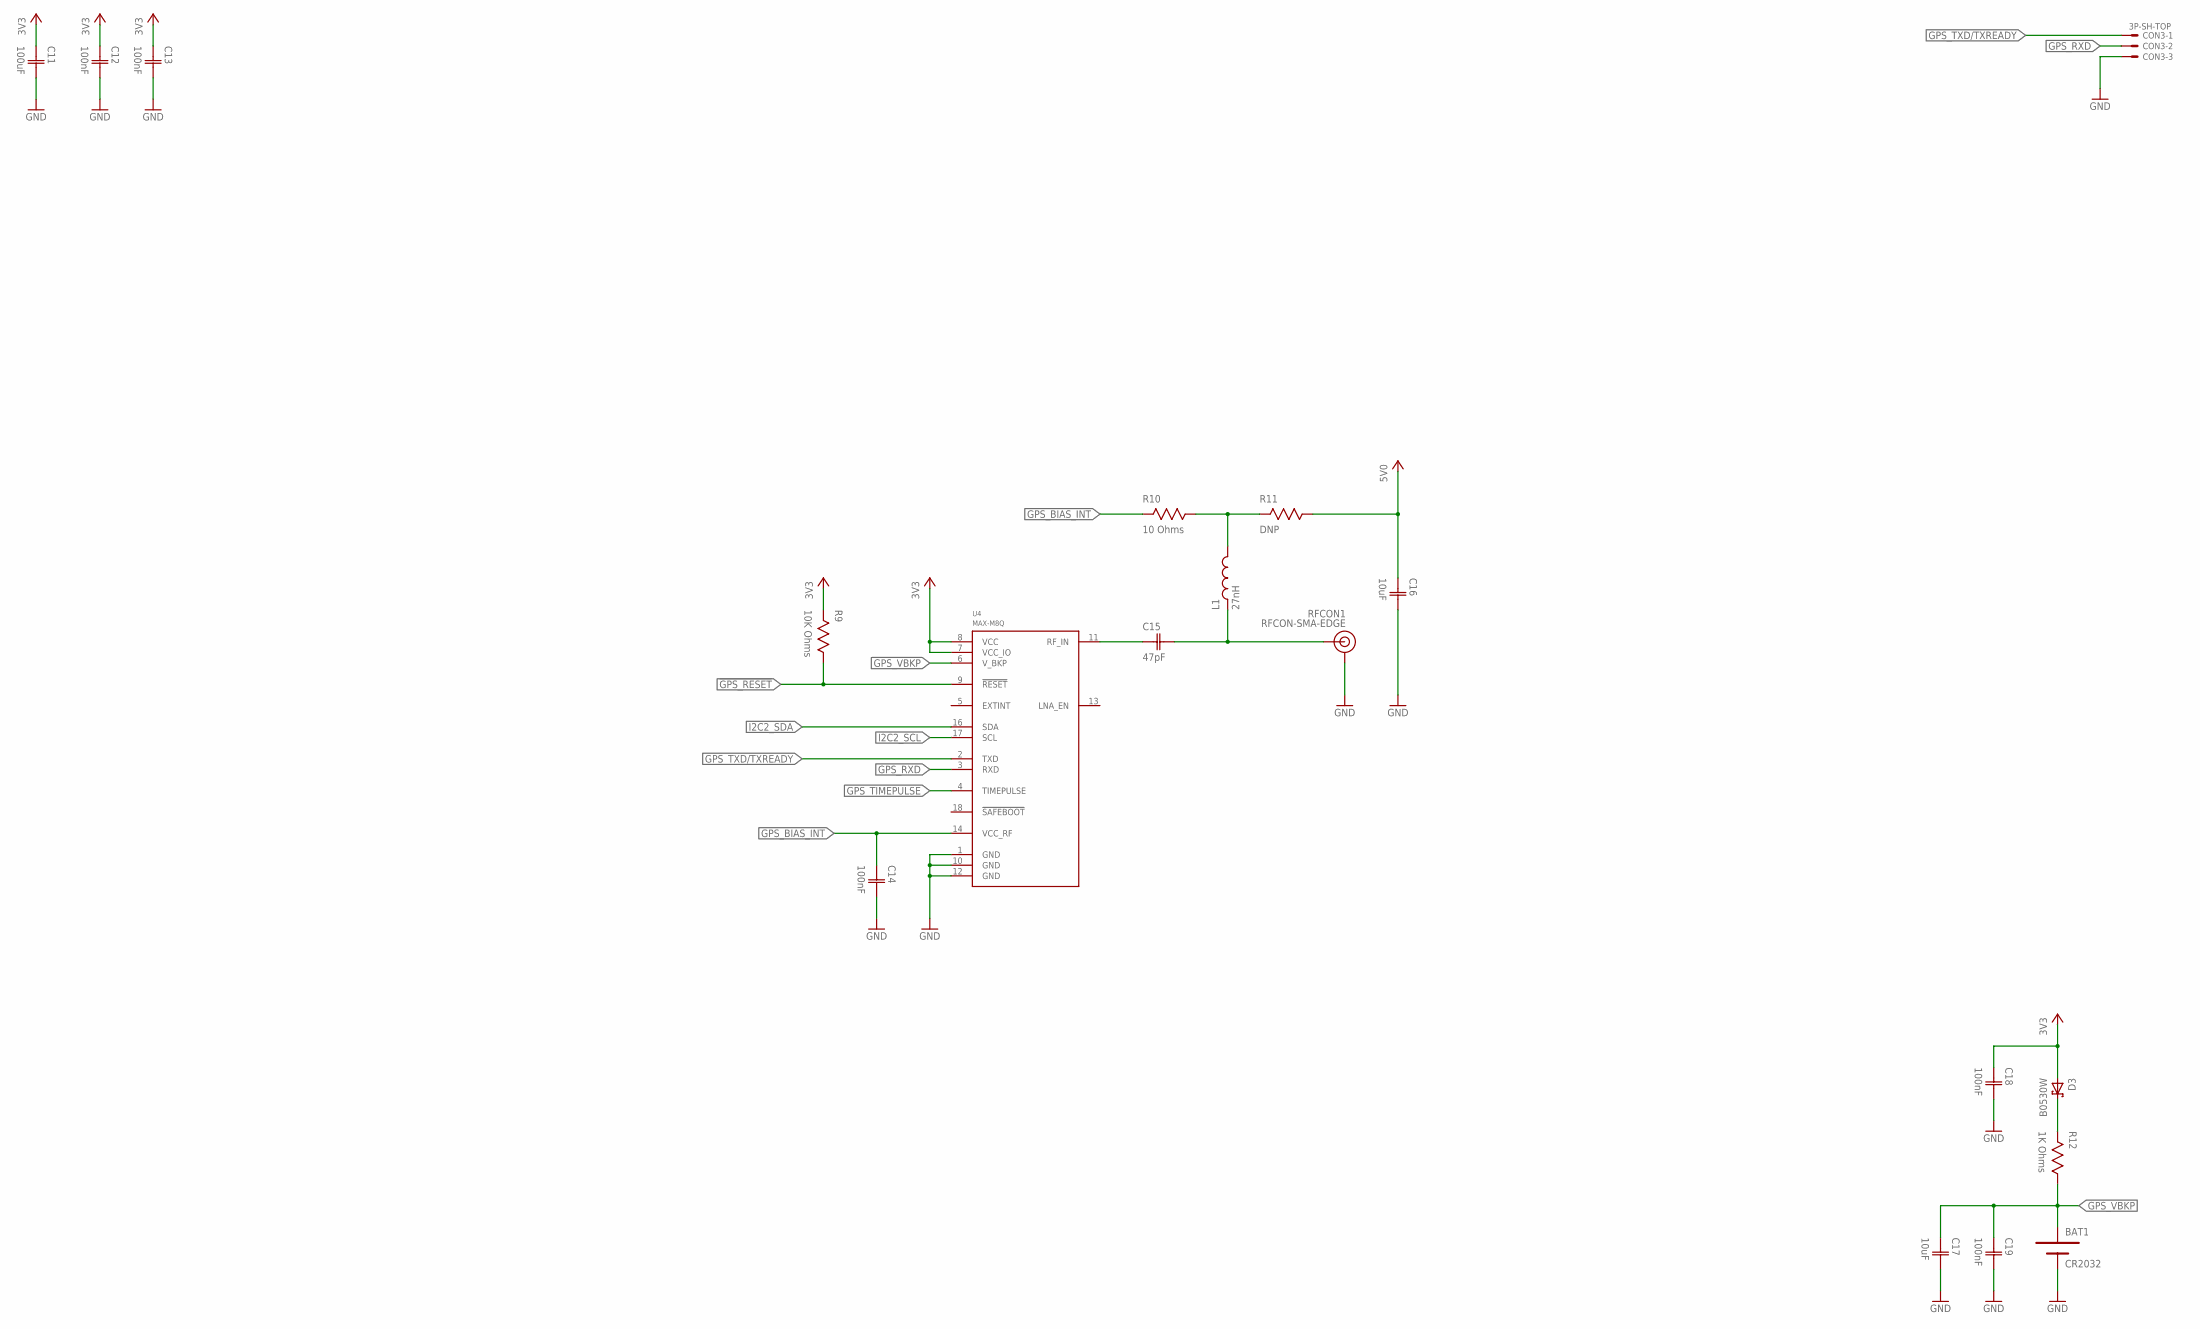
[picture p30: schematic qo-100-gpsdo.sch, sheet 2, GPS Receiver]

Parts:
BAT1: CR2032
C11: 100uF; CAP1206
C12, C13, C14, C18, C19: 100nF; CAP0402
C15: 47pF; CAP0402
C16, C17: 10uF; CAP0603
CON3: 3P-SH-TOP; SH-03-TOP
D3: B0530W; SOD-123
L1: 27nH; IND0805
R9: 10K Ohms; RES0402
R10: 10 Ohms; RES0603
R11: DNP; RES0603
R12: 1K Ohms; RES0402
RFCON1: RFCON-SMA-EDGE; SMA-EDGE
U4: MAX-M8Q; MAX-M8

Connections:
3V3: C11.1 (C1), C12.1 (C1), C13.1 (C1), C18.1 (C1), D3.A, R9.2, U4.7 (VCC_IO), U4.8 (VCC); also elsewhere on the board
5V0: C16.1 (C1), R11.1; also elsewhere on the board
!GPS_RESET: R9.1, U4.9 (!RESET); also elsewhere on the board
GND: BAT1.-, C11.2 (C2), C12.2 (C2), C13.2 (C2), C14.2 (C2), C16.2 (C2), C17.2 (C2), C18.2 (C2), C19.2 (C2), CON3.3, RFCON1.GND@0 (GND), RFCON1.GND@1 (GND), RFCON1.GND@2 (GND), RFCON1.GND@3 (GND), U4.1 (GND), U4.10 (GND), U4.12 (GND); also elsewhere on the board
GPS_BIAS_INT: C14.1 (C1), R10.2, U4.14 (VCC_RF)
GPS_RXD: CON3.2, U4.3 (RXD); also elsewhere on the board
GPS_TIMEPULSE: U4.4 (TIMEPULSE); also elsewhere on the board
GPS_TXD/TXREADY: CON3.1, U4.2 (TXD); also elsewhere on the board
GPS_VBKP: BAT1.+, C17.1 (C1), C19.1 (C1), R12.1, U4.6 (V_BKP)
I2C2_SCL: U4.17 (SCL); also elsewhere on the board
I2C2_SDA: U4.16 (SDA); also elsewhere on the board
unnamed: D3.C, R12.2
unnamed: C15.1 (C1), U4.11 (RF_IN)
unnamed: C15.2 (C2), L1.1, RFCON1.SIG (SIGNAL)
unnamed: L1.2, R10.1, R11.2

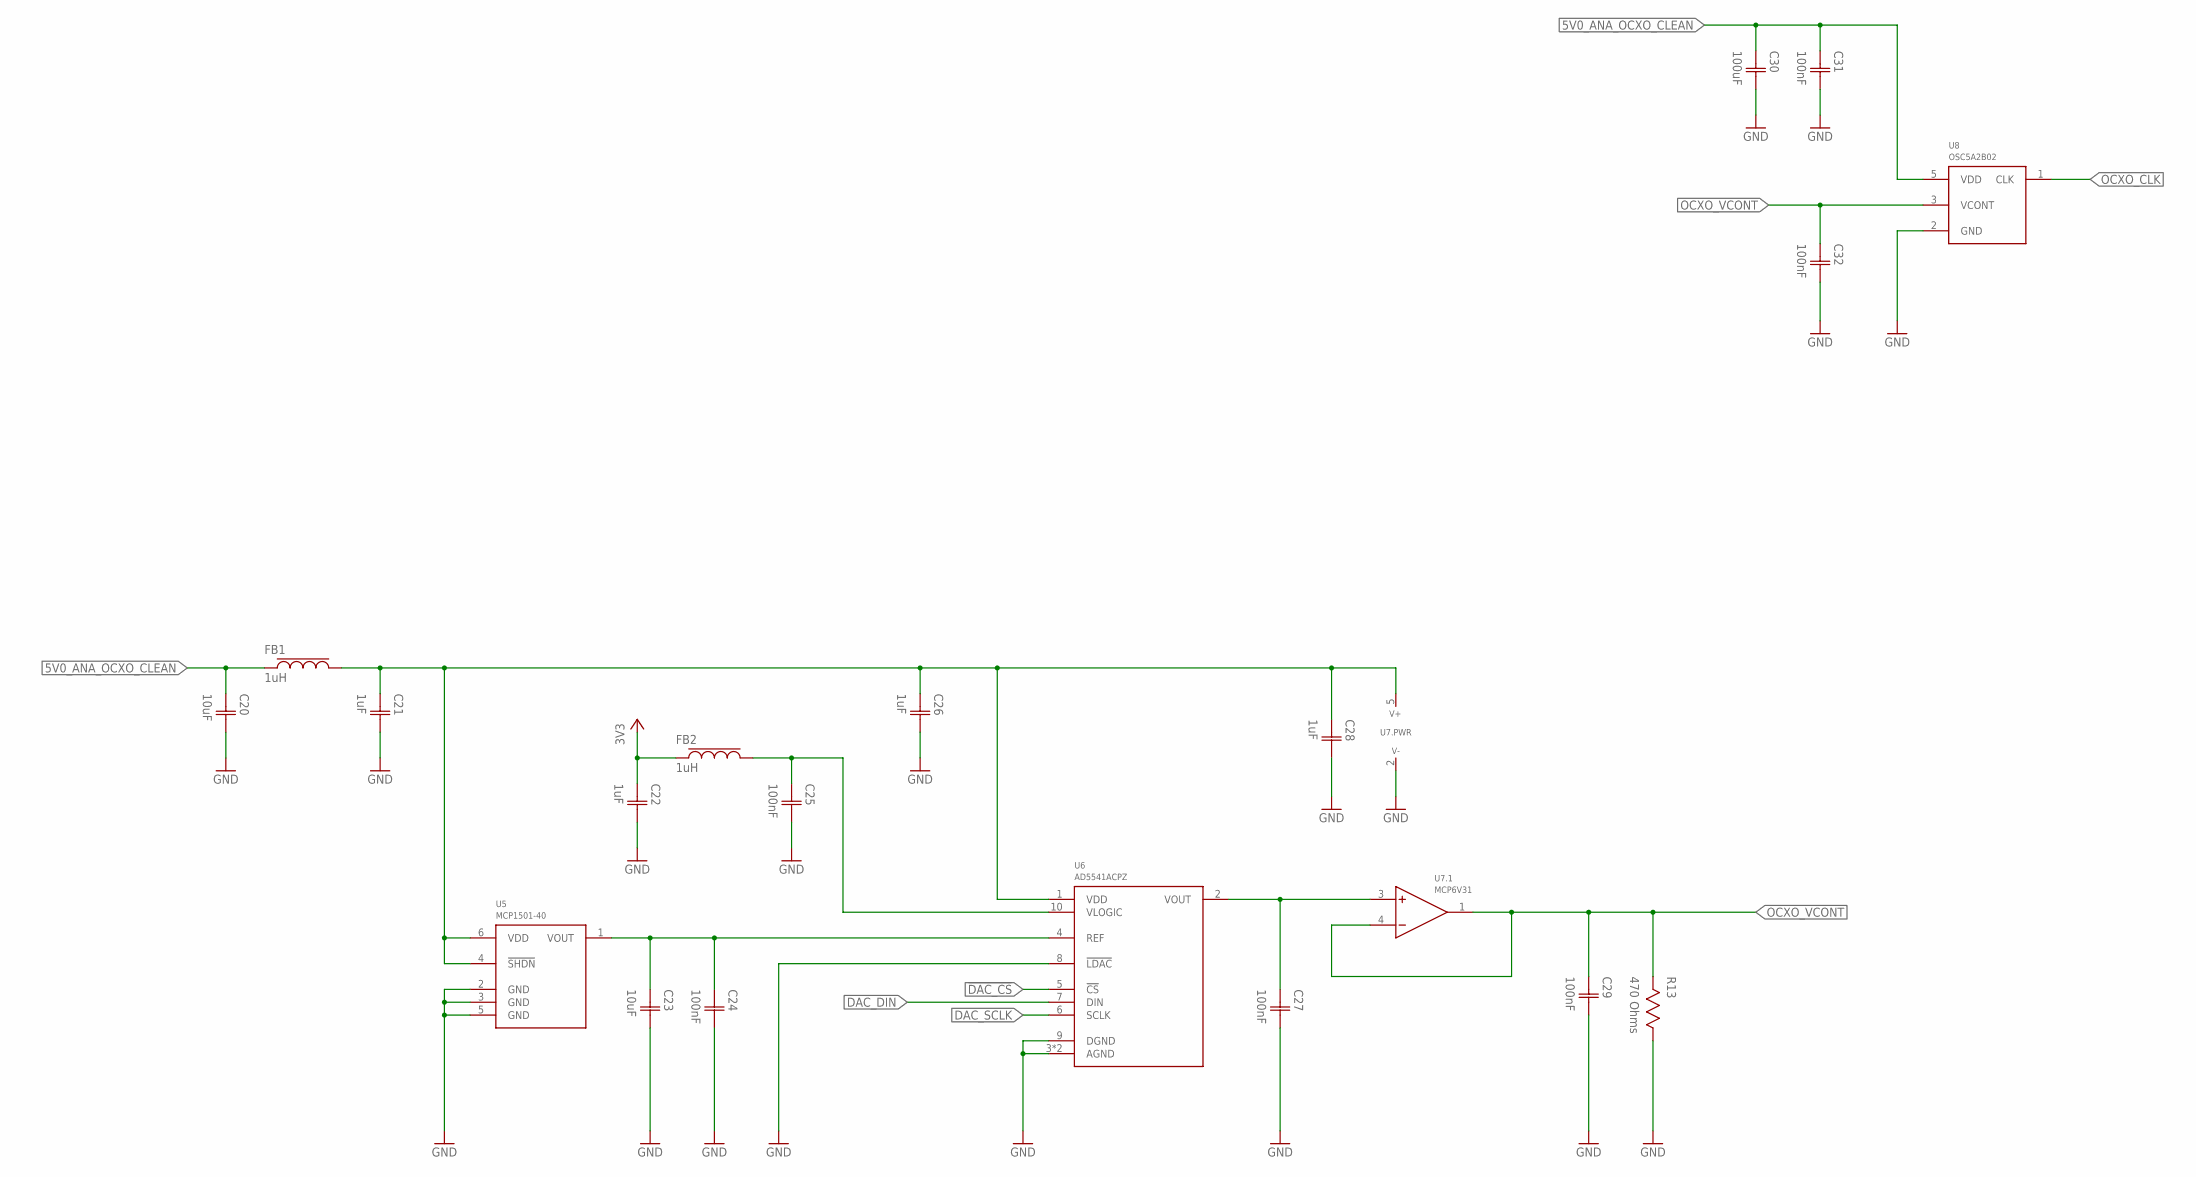
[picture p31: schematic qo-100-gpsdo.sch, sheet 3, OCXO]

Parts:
C20, C23: 10uF; CAP0603
C21, C22, C26, C28: 1uF; CAP0402
C24, C25, C27, C29, C31, C32: 100nF; CAP0402
C30: 100uF; CAP1206
FB1, FB2: 1uH; IND0603
R13: 470 Ohms; RES0402
U5: MCP1501-40; SOT23-6
U6: AD5541ACPZ; DFN10
U7: MCP6V31; SOT23-5
U8: OSC5A2B02

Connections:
3V3: C22.1 (C1), FB2.1; also elsewhere on the board
5V0_ANA_OCXO_CLEAN: C20.1 (C1), C30.1 (C1), C31.1 (C1), FB1.1, U8.5 (VDD); also elsewhere on the board
5V0_ANA_OCXO_CLEAN_FILT: C21.1 (C1), C26.1 (C1), C28.1 (C1), FB1.2, U5.4 (!SHDN), U5.6 (VDD), U6.1 (VDD), U7.5 (V+)
!DAC_CS: U6.5 (!CS); also elsewhere on the board
DAC_DIN: U6.7 (DIN); also elsewhere on the board
DAC_SCLK: U6.6 (SCLK); also elsewhere on the board
GND: C20.2 (C2), C21.2 (C2), C22.2 (C2), C23.2 (C2), C24.2 (C2), C25.2 (C2), C26.2 (C2), C27.2 (C2), C28.2 (C2), C29.2 (C2), C30.2 (C2), C31.2 (C2), C32.2 (C2), R13.1, U5.2 (GND), U5.3 (GND), U5.5 (GND), U6.3 (AGND), U6.8 (!LDAC), U6.9 (DGND), U6.11 (AGND), U7.2 (V-), U8.2 (GND); also elsewhere on the board
unnamed: C27.1 (C1), U6.2 (VOUT), U7.3 (+IN)
unnamed: C25.1 (C1), FB2.2, U6.10 (VLOGIC)
unnamed: C23.1 (C1), C24.1 (C1), U5.1 (VOUT), U6.4 (REF)
OCXO_CLK: U8.1 (CLK); also elsewhere on the board
OCXO_VCONT: C29.1 (C1), C32.1 (C1), R13.2, U7.1 (OUT), U7.4 (-IN), U8.3 (VCONT)

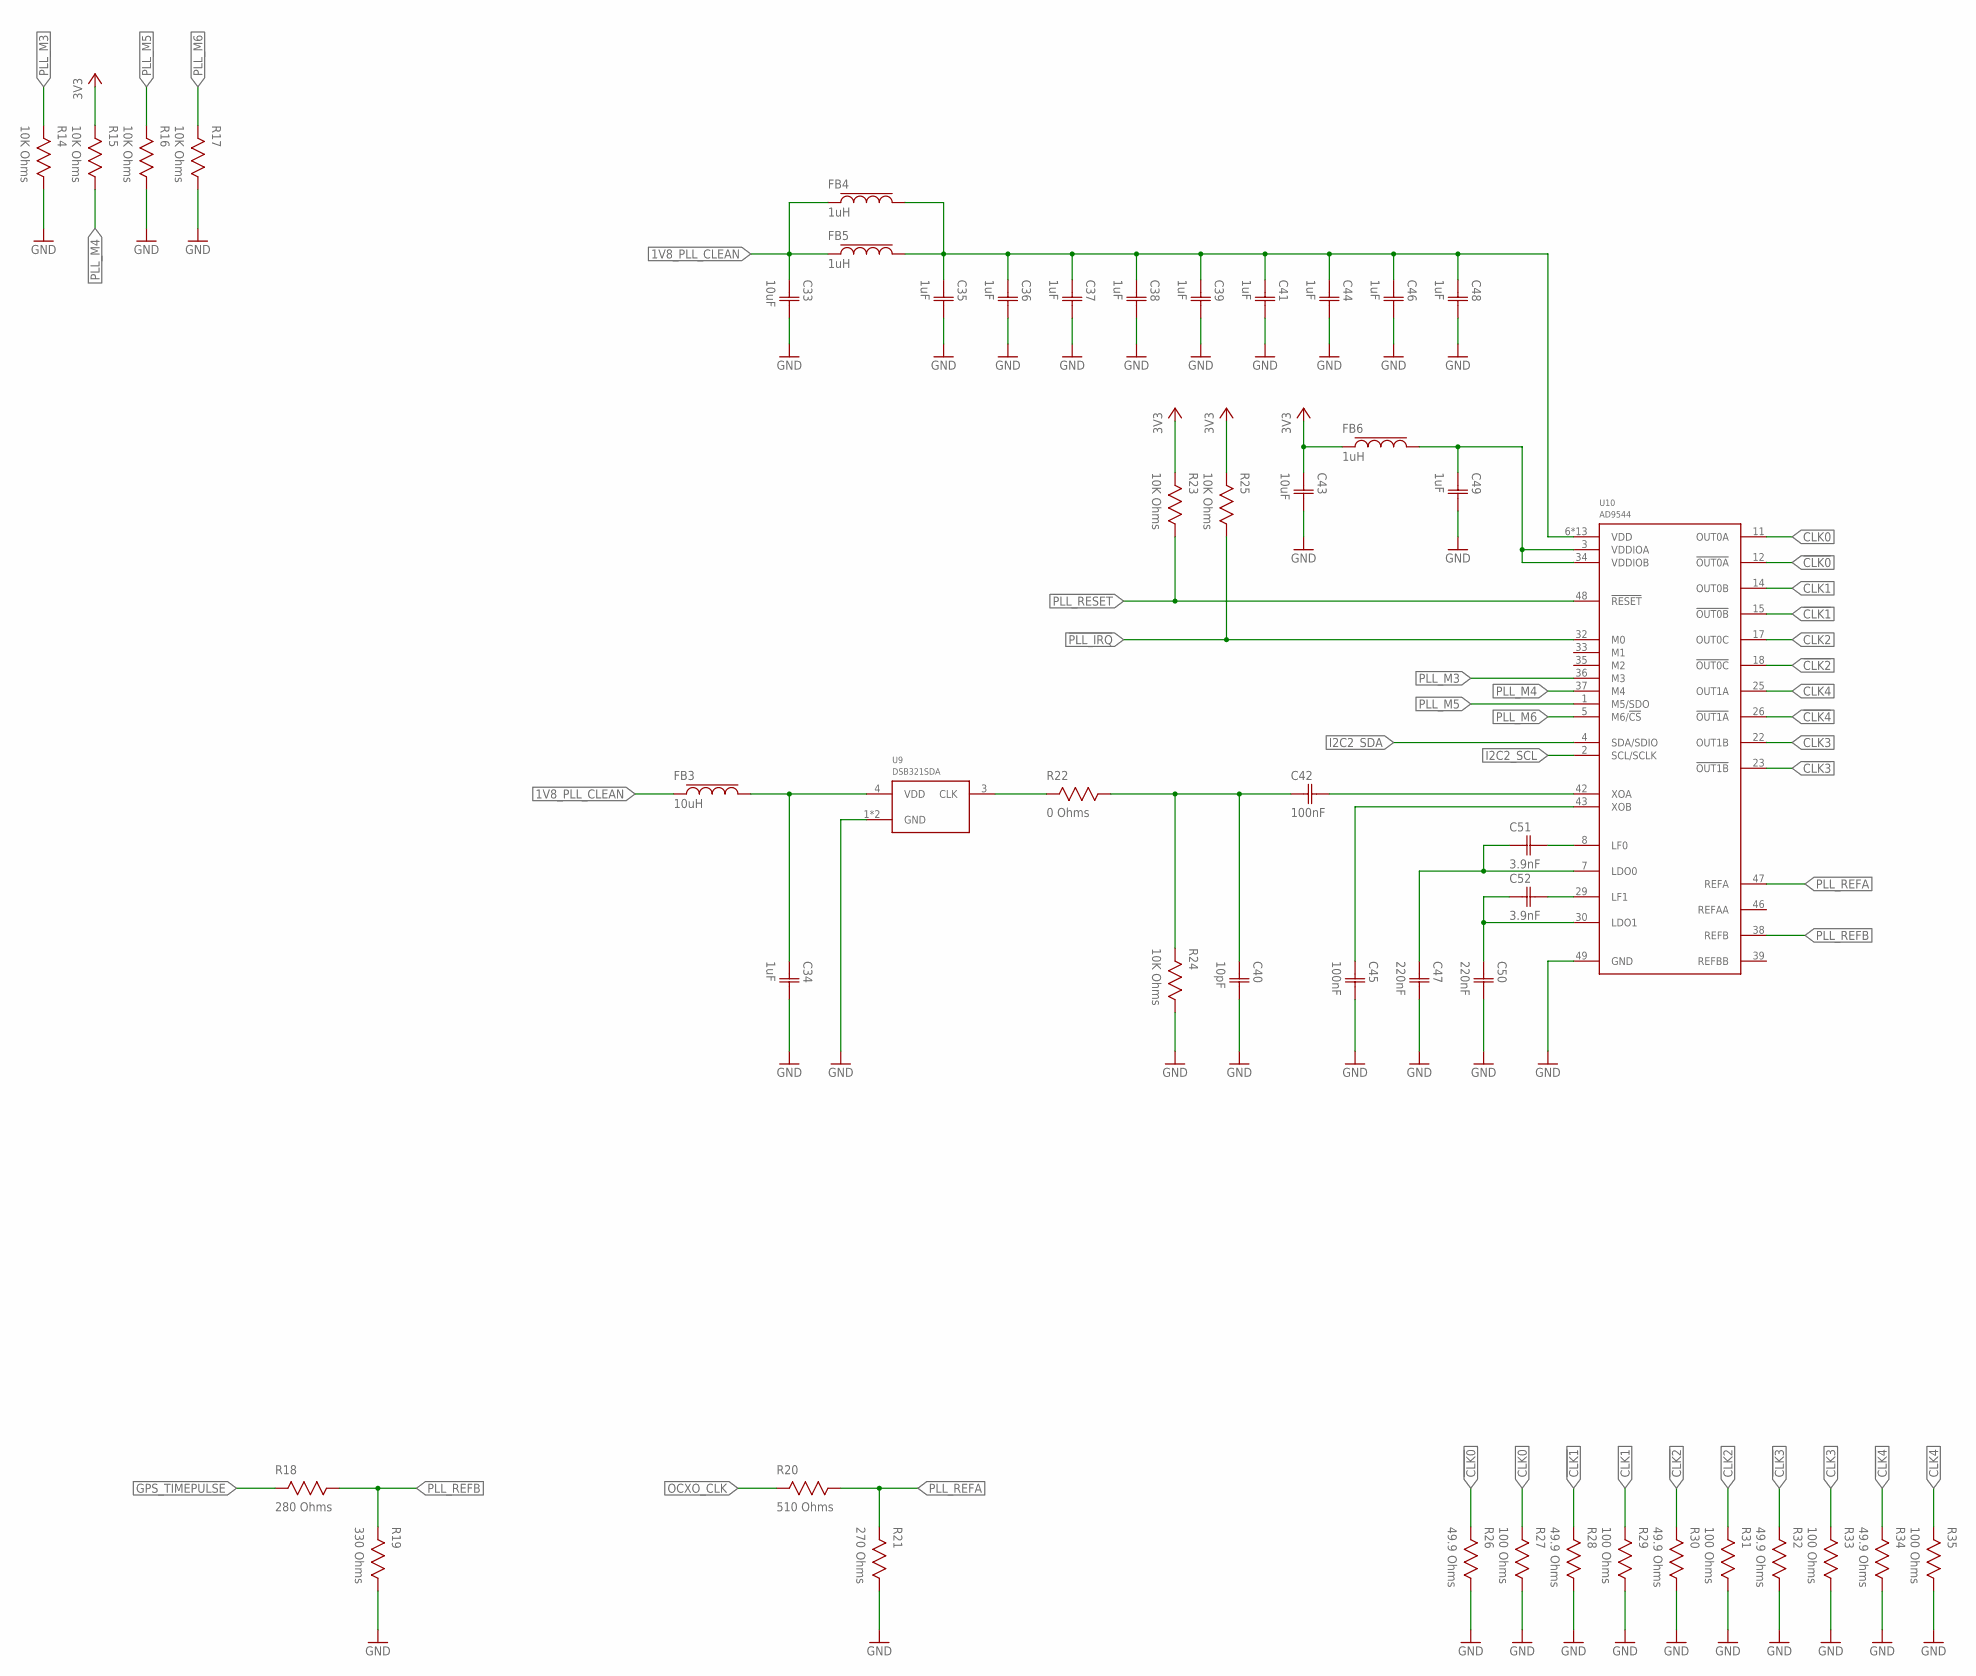
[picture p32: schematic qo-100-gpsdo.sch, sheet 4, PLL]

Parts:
C33, C43: 10uF; CAP0603
C34, C35, C36, C37, C38, C39, C41, C44, C46, C48, C49: 1uF; CAP0402
C40: 10pF; CAP0402
C42, C45: 100nF; CAP0402
C47, C50: 220nF; CAP0402
C51, C52: 3.9nF; CAP0402
FB3: 10uH; IND0603
FB4, FB5, FB6: 1uH; IND0603
R14, R15, R16, R17, R23, R24, R25: 10K Ohms; RES0402
R18: 280 Ohms; RES0402
R19: 330 Ohms; RES0402
R20: 510 Ohms; RES0402
R21: 270 Ohms; RES0402
R22: 0 Ohms; RES0402
R26, R28, R30, R32, R34: 49.9 Ohms; RES0402
R27, R29, R31, R33, R35: 100 Ohms; RES0402
U9: DSB321SDA; TCXO-3225
U10: AD9544; QFN48_2

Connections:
1V8_PLL_CLEAN: C33.1 (C1), FB3.1, FB4.1, FB5.1; also elsewhere on the board
1V8_PLL_CLEAN_FILT: C35.1 (C1), C36.1 (C1), C37.1 (C1), C38.1 (C1), C39.1 (C1), C41.1 (C1), C44.1 (C1), C46.1 (C1), C48.1 (C1), FB4.2, FB5.2, U10.6 (VDD), U10.9 (VDD), U10.10 (VDD), U10.13 (VDD), U10.19 (VDD), U10.20 (VDD), U10.24 (VDD), U10.27 (VDD), U10.28 (VDD), U10.31 (VDD), U10.40 (VDD), U10.41 (VDD), U10.45 (VDD)
3V3: C43.1 (C1), FB6.1, R15.2, R23.2, R25.2; also elsewhere on the board
3V3_PLL_FILT: C49.1 (C1), FB6.2, U10.3 (VDDIOA), U10.34 (VDDIOB)
!CLK0: R26.2, U10.12 (!OUT0A); also elsewhere on the board
!CLK1: R28.2, U10.15 (!OUT0B); also elsewhere on the board
!CLK2: R30.2, U10.18 (!OUT0C); also elsewhere on the board
!CLK3: R32.2, U10.23 (!OUT1B); also elsewhere on the board
!CLK4: R34.2, U10.26 (!OUT1A); also elsewhere on the board
!PLL_IRQ: R25.1, U10.32 (M0); also elsewhere on the board
!PLL_RESET: R23.1, U10.48 (!RESET); also elsewhere on the board
CLK0: R27.2, U10.11 (OUT0A); also elsewhere on the board
CLK1: R29.2, U10.14 (OUT0B); also elsewhere on the board
CLK2: R31.2, U10.17 (OUT0C); also elsewhere on the board
CLK3: R33.2, U10.22 (OUT1B); also elsewhere on the board
CLK4: R35.2, U10.25 (OUT1A); also elsewhere on the board
GND: C33.2 (C2), C34.2 (C2), C35.2 (C2), C36.2 (C2), C37.2 (C2), C38.2 (C2), C39.2 (C2), C40.2 (C2), C41.2 (C2), C43.2 (C2), C44.2 (C2), C45.2 (C2), C46.2 (C2), C47.2 (C2), C48.2 (C2), C49.2 (C2), C50.2 (C2), R14.1, R16.1, R17.1, R19.1, R21.1, R24.1, R26.1, R27.1, R28.1, R29.1, R30.1, R31.1, R32.1, R33.1, R34.1, R35.1, U9.1 (GND), U9.2 (GND), U10.49 (GND); also elsewhere on the board
GPS_TIMEPULSE: R18.2; also elsewhere on the board
I2C2_SCL: U10.2 (SCL/SCLK); also elsewhere on the board
I2C2_SDA: U10.4 (SDA/SDIO); also elsewhere on the board
unnamed: C40.1 (C1), C42.1 (C1), R22.1, R24.2
unnamed: R22.2, U9.3 (CLK)
unnamed: C50.1 (C1), C52.1 (C1), U10.30 (LDO1)
unnamed: C47.1 (C1), C51.1 (C1), U10.7 (LDO0)
unnamed: C52.2 (C2), U10.29 (LF1)
unnamed: C51.2 (C2), U10.8 (LF0)
unnamed: C45.1 (C1), U10.43 (XOB)
unnamed: C42.2 (C2), U10.42 (XOA)
unnamed: C34.1 (C1), FB3.2, U9.4 (VDD)
OCXO_CLK: R20.2; also elsewhere on the board
PLL_M3: R14.2, U10.36 (M3)
PLL_M4: R15.1, U10.37 (M4)
PLL_M5: R16.2, U10.1 (M5/SDO)
PLL_M6: R17.2, U10.5 (M6/!CS)
PLL_REFA: R20.1, R21.2, U10.47 (REFA)
PLL_REFB: R18.1, R19.2, U10.38 (REFB)

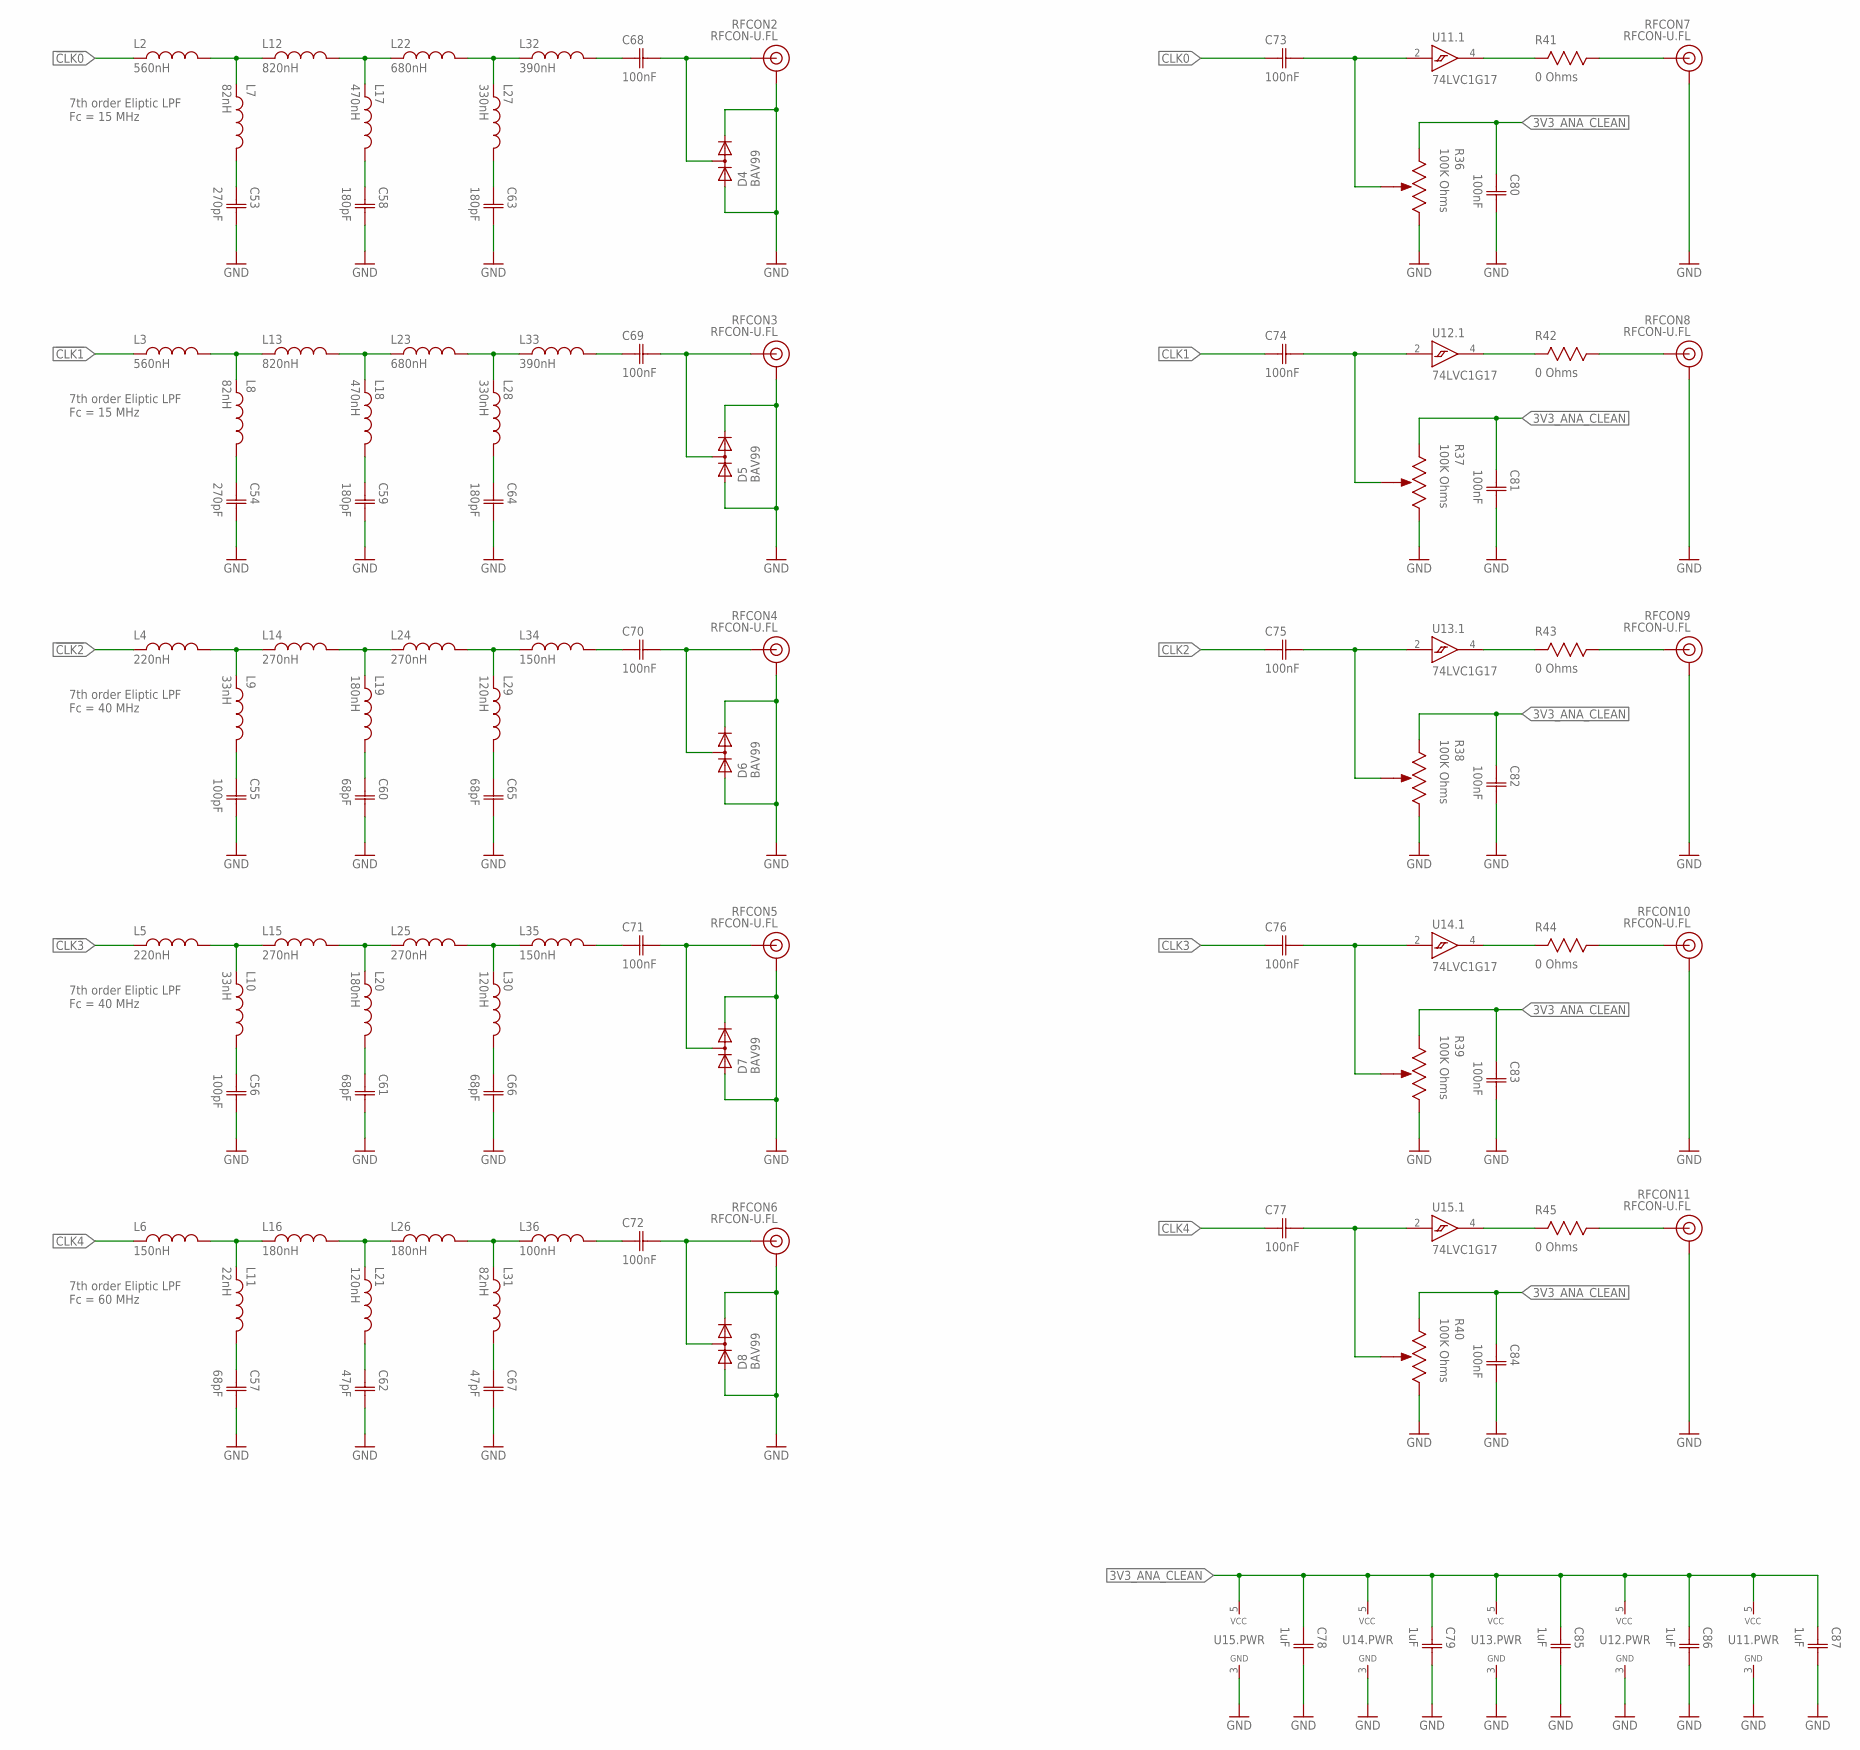
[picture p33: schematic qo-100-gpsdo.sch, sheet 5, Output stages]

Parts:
C53, C54: 270pF; CAP0402
C55, C56: 100pF; CAP0402
C57, C60, C61, C65, C66: 68pF; CAP0402
C58, C59, C63, C64: 180pF; CAP0402
C62, C67: 47pF; CAP0402
C68, C69, C70, C71, C72, C73, C74, C75, C76, C77, C80, C81, C82, C83, C84: 100nF; CAP0402
C78, C79, C85, C86, C87: 1uF; CAP0402
D4, D5, D6, D7, D8: BAV99; SOT23
L2, L3: 560nH; IND0402
L4, L5: 220nH; IND0402
L6, L34, L35: 150nH; IND0402
L7, L8, L31: 82nH; IND0402
L9, L10: 33nH; IND0402
L11: 22nH; IND0402
L12, L13: 820nH; IND0402
L14, L15, L24, L25: 270nH; IND0402
L16, L19, L20, L26: 180nH; IND0402
L17, L18: 470nH; IND0402
L21, L29, L30: 120nH; IND0402
L22, L23: 680nH; IND0402
L27, L28: 330nH; IND0402
L32, L33: 390nH; IND0402
L36: 100nH; IND0402
R36, R37, R38, R39, R40: 100K Ohms; POT3MM
R41, R42, R43, R44, R45: 0 Ohms; RES0402
RFCON2, RFCON3, RFCON4, RFCON5, RFCON6, RFCON7, RFCON8, RFCON9, RFCON10, RFCON11: RFCON-U.FL; U.FL
U11, U12, U13, U14, U15: 74LVC1G17; SC70-5

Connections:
3V3_ANA_CLEAN: C78.1 (C1), C79.1 (C1), C80.1 (C1), C81.1 (C1), C82.1 (C1), C83.1 (C1), C84.1 (C1), C85.1 (C1), C86.1 (C1), C87.1 (C1), R36.1 (CCW), R37.1 (CCW), R38.1 (CCW), R39.1 (CCW), R40.1 (CCW), U11.5 (VCC), U12.5 (VCC), U13.5 (VCC), U14.5 (VCC), U15.5 (VCC); also elsewhere on the board
!CLK0: L2.1; also elsewhere on the board
!CLK1: L3.1; also elsewhere on the board
!CLK2: L4.1; also elsewhere on the board
!CLK3: L5.1; also elsewhere on the board
!CLK4: L6.1; also elsewhere on the board
CLK0: C73.1 (C1); also elsewhere on the board
CLK1: C74.1 (C1); also elsewhere on the board
CLK2: C75.1 (C1); also elsewhere on the board
CLK3: C76.1 (C1); also elsewhere on the board
CLK4: C77.1 (C1); also elsewhere on the board
GND: C53.2 (C2), C54.2 (C2), C55.2 (C2), C56.2 (C2), C57.2 (C2), C58.2 (C2), C59.2 (C2), C60.2 (C2), C61.2 (C2), C62.2 (C2), C63.2 (C2), C64.2 (C2), C65.2 (C2), C66.2 (C2), C67.2 (C2), C78.2 (C2), C79.2 (C2), C80.2 (C2), C81.2 (C2), C82.2 (C2), C83.2 (C2), C84.2 (C2), C85.2 (C2), C86.2 (C2), C87.2 (C2), D4.1 (A), D4.2 (C), D5.1 (A), D5.2 (C), D6.1 (A), D6.2 (C), D7.1 (A), D7.2 (C), D8.1 (A), D8.2 (C), R36.3 (CW), R37.3 (CW), R38.3 (CW), R39.3 (CW), R40.3 (CW), RFCON2.P$1 (GND), RFCON2.P$2 (GND), RFCON3.P$1 (GND), RFCON3.P$2 (GND), RFCON4.P$1 (GND), RFCON4.P$2 (GND), RFCON5.P$1 (GND), RFCON5.P$2 (GND), RFCON6.P$1 (GND), RFCON6.P$2 (GND), RFCON7.P$1 (GND), RFCON7.P$2 (GND), RFCON8.P$1 (GND), RFCON8.P$2 (GND), RFCON9.P$1 (GND), RFCON9.P$2 (GND), RFCON10.P$1 (GND), RFCON10.P$2 (GND), RFCON11.P$1 (GND), RFCON11.P$2 (GND), U11.3 (GND), U12.3 (GND), U13.3 (GND), U14.3 (GND), U15.3 (GND); also elsewhere on the board
unnamed: C53.1 (C1), L7.2
unnamed: C58.1 (C1), L17.2
unnamed: C63.1 (C1), L27.2
unnamed: C68.1 (C1), L32.2
unnamed: L3.2, L8.1, L13.1
unnamed: L13.2, L18.1, L23.1
unnamed: R45.1, RFCON11.P$3 (SIGNAL)
unnamed: C69.2 (C2), D5.3 (MID), RFCON3.P$3 (SIGNAL)
unnamed: C77.2 (C2), R40.2 (WIPER), U15.2 (A)
unnamed: R45.2, U15.4 (Y)
unnamed: R44.1, RFCON10.P$3 (SIGNAL)
unnamed: R44.2, U14.4 (Y)
unnamed: C76.2 (C2), R39.2 (WIPER), U14.2 (A)
unnamed: L23.2, L28.1, L33.1
unnamed: C54.1 (C1), L8.2
unnamed: C59.1 (C1), L18.2
unnamed: C64.1 (C1), L28.2
unnamed: C69.1 (C1), L33.2
unnamed: L2.2, L7.1, L12.1
unnamed: L12.2, L17.1, L22.1
unnamed: C68.2 (C2), D4.3 (MID), RFCON2.P$3 (SIGNAL)
unnamed: L22.2, L27.1, L32.1
unnamed: L4.2, L9.1, L14.1
unnamed: L14.2, L19.1, L24.1
unnamed: C70.2 (C2), D6.3 (MID), RFCON4.P$3 (SIGNAL)
unnamed: L24.2, L29.1, L34.1
unnamed: C55.1 (C1), L9.2
unnamed: C60.1 (C1), L19.2
unnamed: C65.1 (C1), L29.2
unnamed: C70.1 (C1), L34.2
unnamed: L5.2, L10.1, L15.1
unnamed: L15.2, L20.1, L25.1
unnamed: C71.2 (C2), D7.3 (MID), RFCON5.P$3 (SIGNAL)
unnamed: L25.2, L30.1, L35.1
unnamed: C56.1 (C1), L10.2
unnamed: C61.1 (C1), L20.2
unnamed: C66.1 (C1), L30.2
unnamed: C71.1 (C1), L35.2
unnamed: L6.2, L11.1, L16.1
unnamed: L16.2, L21.1, L26.1
unnamed: C72.2 (C2), D8.3 (MID), RFCON6.P$3 (SIGNAL)
unnamed: L26.2, L31.1, L36.1
unnamed: C57.1 (C1), L11.2
unnamed: C62.1 (C1), L21.2
unnamed: C67.1 (C1), L31.2
unnamed: C72.1 (C1), L36.2
unnamed: R43.1, RFCON9.P$3 (SIGNAL)
unnamed: R43.2, U13.4 (Y)
unnamed: C75.2 (C2), R38.2 (WIPER), U13.2 (A)
unnamed: R42.1, RFCON8.P$3 (SIGNAL)
unnamed: R42.2, U12.4 (Y)
unnamed: C74.2 (C2), R37.2 (WIPER), U12.2 (A)
unnamed: R41.1, RFCON7.P$3 (SIGNAL)
unnamed: R41.2, U11.4 (Y)
unnamed: C73.2 (C2), R36.2 (WIPER), U11.2 (A)

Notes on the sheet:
7th order Eliptic LPF Fc = 15 MHz
7th order Eliptic LPF Fc = 40 MHz
7th order Eliptic LPF Fc = 60 MHz

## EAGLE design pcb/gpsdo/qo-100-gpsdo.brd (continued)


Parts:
C88, C89, C90, C101, C103, C104, C106, C107, C112, C114: 100nF; CAP0402
C91: 4.7uF; CAP0603
C92: 4.7uF; CAP0603; VOLTAGE 35V
C93, C96, C99, C109: 10nF; CAP0402
C94, C95: 1uF; CAP0603; VOLTAGE 50V
C97, C115, C116: 470pF; CAP0402
C98: 1uF; CAP0402
C100, C102, C113: 10uF; CAP0603
C105: 10pF; CAP0402
C108, C110, C111: 100uF; CAP1206
C117: 10uF; CAP1206; VOLTAGE 50V
CON4: 2EDG-2P-5MM
D9: LED0603; 0603
D10: LEDTH3MM; LED_3MM
D11: SMAJ24A; DO214AC
F1: 2.6A Hold; 1206
J1: DCJACK; DC-050
L37: 2.2uH; IND3515
L38: 4.7uH; IND0404
R46, R60: 75K Ohms; RES0402
R47, R48, R49, R50, R58: 10K Ohms; RES0402
R51: 41.2K Ohms; RES0402
R52: 309K Ohms; RES0402
R53: 71.5K Ohms; RES0402
R54: 1M Ohms; RES0402
R55: 226K Ohms; RES0402
R56: 510 Ohms; RES0402
R57, R59: 100K Ohms; RES0402
U16: ADM7171ACPZ-1.8; LFCSP8_3X3
U17: ADM7171ACPZ-5.0; LFCSP8_3X3
U18: MIC23155; DFN10
U19: LT8636; QFN20_ASYM_3X4_CORNER
U20: ADM7171ACPZ-3.3; LFCSP8_3X3

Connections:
1V8_PLL_CLEAN: C100.1 (C1), C101.1 (C1), U16.1 (VOUT), U16.2 (VOUT), U16.3 (SENSE); also elsewhere on the board
3V3: C89.1 (C1), C107.1 (C1), C108.1 (C1), L37.2, R49.2, R52.2, U16.7 (VIN), U16.8 (VIN), U18.3 (SNS); also elsewhere on the board
3V3_ANA_CLEAN: C113.1 (C1), C114.1 (C1), U20.1 (VOUT), U20.2 (VOUT), U20.3 (SENSE); also elsewhere on the board
3V3_FB: R52.1, R53.2, U18.4 (FB)
3V3_PGOOD: R49.1, U16.5 (EN), U18.5 (PG); also elsewhere on the board
3V3_SS: C97.1 (C1), U18.6 (SS)
3V3_SW: L37.1, U18.1 (SW)
5V0: C88.1 (C1), C90.1 (C1), C91.1 (C1), C105.1 (C1), C106.1 (C1), C110.1 (C1), C111.1 (C1), C112.1 (C1), L38.2, R50.2, R54.2, R56.2, R59.2, U17.7 (VIN), U17.8 (VIN), U18.8 (VIN), U18.9 (VIN), U19.2 (BIAS), U20.7 (VIN), U20.8 (VIN); also elsewhere on the board
5V0_ANA_OCXO_CLEAN: C102.1 (C1), C103.1 (C1), U17.1 (VOUT), U17.2 (VOUT), U17.3 (SENSE); also elsewhere on the board
5V0_BST: C104.2 (C2), U19.7 (BST)
5V0_EN: R46.1, R47.2, U19.14 (EN/UV)
5V0_FB: C105.2 (C2), R54.1, R55.2, U19.19 (FB), U19.20 (FB)
5V0_INTVCC: C98.1 (C1), U19.3 (INTVCC), U19.15 (SYNC/MODE)
5V0_PGOOD: R50.1, U18.2 (EN), U19.1 (PG), U20.5 (EN)
5V0_RT: R51.2, U19.17 (RT)
5V0_SS: C99.1 (C1), U19.18 (TR/SS)
5V0_SW: C104.1 (C1), L38.1, U19.8 (SW), U19.9 (SW), U19.10 (SW)
5V0_VSENSE: C116.1 (C1), R59.1, R60.2; also elsewhere on the board
GND: C88.2 (C2), C89.2 (C2), C90.2 (C2), C91.2 (C2), C92.2 (C2), C93.2 (C2), C94.2 (C2), C95.2 (C2), C96.2 (C2), C97.2 (C2), C98.2 (C2), C99.2 (C2), C100.2 (C2), C101.2 (C2), C102.2 (C2), C103.2 (C2), C106.2 (C2), C107.2 (C2), C108.2 (C2), C109.2 (C2), C110.2 (C2), C111.2 (C2), C112.2 (C2), C113.2 (C2), C114.2 (C2), C115.2 (C2), C116.2 (C2), C117.2 (C2), CON4.P$1, D9.C, D10.K (C), D11.A, J1.O, R47.1, R48.1, R51.1, R53.1, R55.1, R58.1, R60.1, U16.6 (GND), U16.9 (GND), U17.6 (GND), U17.9 (GND), U18.7 (AGND), U18.10 (PGND), U18.11 (PGND), U19.4 (GND), U19.5 (GND), U19.12 (GND), U19.13 (GND), U19.21 (GND), U19.M1 (GND), U19.M2 (GND), U19.M3 (GND), U19.M4 (GND), U20.6 (GND), U20.9 (GND); also elsewhere on the board
unnamed: C109.1 (C1), U20.4 (SS)
unnamed: C96.1 (C1), U17.4 (SS)
unnamed: CON4.P$2, F1.2, J1.C, J1.C' (C)
unnamed: C93.1 (C1), U16.4 (SS)
unnamed: D9.A, D10.A, R56.1
OCXO_EN: R48.2, U17.5 (EN); also elsewhere on the board
VIN: C92.1 (C1), C94.1 (C1), C95.1 (C1), C117.1 (C1), D11.C, F1.1, R46.2, R57.2, U19.6 (VIN), U19.11 (VIN)
VIN_VSENSE: C115.1 (C1), R57.1, R58.2; also elsewhere on the board

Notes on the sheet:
VIN 9 to 24V
LT8636 5.2V @ 5A
MIC23155 3.3V @ 2A
Digital Rail MCU
ADM7171 1.8V @ 1A
Analog Rail PLL core
Analog Rail Output stages
ADM7171 5V @ 1A
Analog Rail OCXO and comp. network
ADM7171 3.3V @ 1A
Enable



Board: 4 copper layers, 100.0 x 69.5 mm, 272 parts (3 on the bottom side), 145 nets.

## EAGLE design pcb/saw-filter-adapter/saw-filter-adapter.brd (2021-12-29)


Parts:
RFCON1, RFCON2, RFCON3, RFCON4: RFCON-SMA-EDGE; SMA-EDGE
U1: DEA162500LT-1212A1
U2: DEA162450BT-1260B3
U3: 2450BP15E0100

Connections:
GND: RFCON1.GND@0 (GND), RFCON1.GND@1 (GND), RFCON1.GND@2 (GND), RFCON1.GND@3 (GND), RFCON2.GND@0 (GND), RFCON2.GND@1 (GND), RFCON2.GND@2 (GND), RFCON2.GND@3 (GND), RFCON3.GND@0 (GND), RFCON3.GND@1 (GND), RFCON3.GND@2 (GND), RFCON3.GND@3 (GND), RFCON4.GND@0 (GND), RFCON4.GND@1 (GND), RFCON4.GND@2 (GND), RFCON4.GND@3 (GND), U1.1 (GND), U1.3 (GND), U1.4 (GND), U1.6 (GND), U2.2 (GND), U2.4 (GND), U3.1 (GND), U3.3 (GND)
unnamed: RFCON1.SIG (SIGNAL), U1.2 (RFIN)
unnamed: RFCON2.SIG (SIGNAL), U1.5 (RFOUT)
unnamed: RFCON4.SIG (SIGNAL), U2.3 (RFOUT), U3.2 (RFOUT)
unnamed: RFCON3.SIG (SIGNAL), U2.1 (RFIN), U3.4 (RFIN)


Board: 2 copper layers, 20.0 x 21.0 mm, 7 parts (0 on the bottom side), 5 nets.

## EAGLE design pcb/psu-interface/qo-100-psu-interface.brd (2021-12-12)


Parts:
CON1, CON4: HIGH-CURRENT-EDGE-64P
CON2, CON3: 2EDG-6P-5MM-V
CON5: 2EDG-2P-5MM-V
CON6, CON7: 6P-SH-SIDE; SH-06-SIDE
D1, D2: LED0603; 0603
LOGO1: JS-5MM; JS_5MM
R1, R2: 22K Ohms; RES0603
R3, R4: 330 Ohms; RES0603
SJ1, SJ2, SJ3, SJ4, SJ5, SJ6, SJ7, SJ8: SJS; SJ_S

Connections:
12V0: CON1.1, CON1.2, CON1.3, CON1.4, CON1.5, CON1.6, CON1.7, CON1.8, CON1.9, CON1.10, CON1.11, CON1.12, CON1.13, CON1.52, CON1.53, CON1.54, CON1.55, CON1.56, CON1.57, CON1.58, CON1.59, CON1.60, CON1.61, CON1.62, CON1.63, CON1.64, CON4.14, CON4.15, CON4.16, CON4.17, CON4.18, CON4.19, CON4.20, CON4.21, CON4.22, CON4.23, CON4.24, CON4.25, CON4.26, CON4.30, CON4.39, CON4.40, CON4.41, CON4.42, CON4.43, CON4.44, CON4.45, CON4.46, CON4.47, CON4.48, CON4.49, CON4.50, CON4.51, CON6.6, D2.C, SJ2.2, SJ6.1, SJ7.1, SJ8.1
!PSU0_ENABLE: CON1.33, CON7.3, SJ1.1
!PSU0_PRESENT: CON1.36, CON7.2, R1.1
!PSU1_ENABLE: CON4.33, CON6.3, SJ2.1
!PSU1_PRESENT: CON4.36, CON6.2, R2.1
GND: CON1.14, CON1.15, CON1.16, CON1.17, CON1.18, CON1.19, CON1.20, CON1.21, CON1.22, CON1.23, CON1.24, CON1.25, CON1.26, CON1.30, CON1.39, CON1.40, CON1.41, CON1.42, CON1.43, CON1.44, CON1.45, CON1.46, CON1.47, CON1.48, CON1.49, CON1.50, CON1.51, CON2.P$1, CON2.P$2, CON2.P$3, CON2.P$4, CON2.P$5, CON2.P$6, CON5.P$2, CON7.6, D1.C, SJ1.2, SJ3.1, SJ4.1, SJ5.1
unnamed: CON1.29, SJ5.2
unnamed: CON1.28, SJ4.2
unnamed: CON1.27, SJ3.2
unnamed: CON4.27, SJ6.2
unnamed: CON4.28, SJ7.2
unnamed: CON4.29, SJ8.2
unnamed: D1.A, R3.1
unnamed: D2.A, R4.1
PSU0_12V0_SB: CON1.37, CON5.P$1, CON7.1, R1.2
PSU0_ALARM: CON1.38
PSU0_IMON: CON1.34
PSU0_SCL: CON1.31, CON7.4
PSU0_SDA: CON1.32, CON7.5
PSU0_STATUS: CON1.35, R3.2
PSU1_12V0_SB: CON4.37, CON6.1, R2.2
PSU1_ALARM: CON4.38
PSU1_IMON: CON4.34
PSU1_SCL: CON4.31, CON6.4
PSU1_SDA: CON4.32, CON6.5
PSU1_STATUS: CON4.35, R4.2
VEXT: CON3.P$1, CON3.P$2, CON3.P$3, CON3.P$4, CON3.P$5, CON3.P$6, CON4.1, CON4.2, CON4.3, CON4.4, CON4.5, CON4.6, CON4.7, CON4.8, CON4.9, CON4.10, CON4.11, CON4.12, CON4.13, CON4.52, CON4.53, CON4.54, CON4.55, CON4.56, CON4.57, CON4.58, CON4.59, CON4.60, CON4.61, CON4.62, CON4.63, CON4.64



Board: 2 copper layers, 90.0 x 53.0 mm, 22 parts (7 on the bottom side), 23 nets.

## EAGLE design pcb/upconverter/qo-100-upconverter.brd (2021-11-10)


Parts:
C1, C2, C3, C4: 100nF; CAP0603
C5: 1uF; CAP0603
CON1: 3P-SH-SIDE; SH-03-SIDE
D1: LED0603; 0603
LOGO1: JS-5MM; JS_5MM
R1: 10K Ohms; RES0603
R2, R3, R4, R5: 1K Ohms; RES0603
R6, R7: 100 Ohms; RES0603
R8: 330 Ohms; RES0603
TC1: TC2050-IDC
U1: EFM32TG11B120F128GM32; QFN32_0.5P_TG

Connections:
3V3: C1.1 (C1), C2.1 (C1), C3.1 (C1), C4.1 (C1), R1.2, R2.2, R3.2, R4.2, R5.2, TC1.1, U1.4 (IOVDD0), U1.11 (AVDD), U1.14 (IOVDD0), U1.15 (AVDD), U1.20 (DVDD), U1.28 (IOVDD0); also elsewhere on the board
5V0_VSENSE: U1.12 (PB13); also elsewhere on the board
!MIXER_SHDN: U1.19 (PD7); also elsewhere on the board
!PLL_MUTE: U1.32 (PE13); also elsewhere on the board
!RESET: R1.1, TC1.10, U1.9 (!RESET)
GND: C1.2 (C2), C2.2 (C2), C3.2 (C2), C4.2 (C2), C5.2 (C2), CON1.3, D1.C, TC1.3, U1.33 (VSS); also elsewhere on the board
I2C0_SCL: R4.1, R7.2, U1.6 (PC1)
I2C0_SDA: R5.1, R6.2, U1.5 (PC0)
I2C1_SCL: R2.1, U1.17 (PD5); also elsewhere on the board
I2C1_SDA: R3.1, U1.16 (PD4); also elsewhere on the board
IF_ATT_LE: U1.18 (PD6); also elsewhere on the board
LED: R8.2, U1.10 (PB11)
unnamed: CON1.2, R7.1
unnamed: CON1.1, R6.1
unnamed: C5.1 (C1), U1.21 (DECOUPLE)
unnamed: D1.A, R8.1
PA_STG1_2_BIAS_EN: U1.7 (PB7); also elsewhere on the board
PA_STG3_BIAS_EN: U1.8 (PB8); also elsewhere on the board
PLL_EN: U1.23 (PC14); also elsewhere on the board
PLL_LE: U1.24 (PC15); also elsewhere on the board
PLL_MUXOUT: U1.30 (PE11); also elsewhere on the board
RF_ATT1_LE: U1.2 (PA1); also elsewhere on the board
RF_ATT2_LE: U1.3 (PA2); also elsewhere on the board
SPI_MOSI: U1.29 (PE10); also elsewhere on the board
SPI_SCK: U1.31 (PE12); also elsewhere on the board
SWCLK: TC1.4, U1.25 (PF0)
SWDIO: TC1.2, U1.26 (PF1)
SWO: TC1.6, U1.27 (PF2)
VIN_VSENSE: U1.13 (PB14); also elsewhere on the board
VPDET_SENSE: U1.1 (PA0); also elsewhere on the board

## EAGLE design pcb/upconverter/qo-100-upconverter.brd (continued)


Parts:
C6, C7, C8, C9, C11, C13, C15, C17: 100nF; CAP0603
C10, C12, C14, C16, C18: 10pF; CAP0603
C19, C20: 0.7pF; CAP0603
C21: 15pF; CAP0603
C22: 20nF; CAP0603
C23: 1nF; CAP0603
C24: 470pF; CAP0603
D2: LED0603; 0603
L1: 1uH; IND0603
L2, L4: 3.3nH; IND0603
L3: 10nH; IND0603
R9, R10: 100K Ohms; RES0603
R11, R17: 330 Ohms; RES0603
R12: 0 Ohms; RES0603
R13: 10K Ohms; RES0603
R14: 5.1K Ohms; RES0603
R15: DNP; RES0603
R16, R20: 105 Ohms; RES0603
R18: 61.9 Ohms; RES0603
R19: 1K Ohms; RES0603
RFCON1: RFCON-U.FL; U.FL
SHIELD1: SHIELD-TE-2118728; 2118728
TP1, TP2, TP3, TP4, TP5, TP6: TESTPOINT-1.27MM; PAD1.27MM
U2: DSB321SDA; TCXO-3225
U3: ADF4351; QFN32

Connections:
3V3_PLL_CLEAN: C6.1 (C1), C7.1 (C1), C8.1 (C1), C9.1 (C1), L1.2, L2.1, L3.2, U2.4 (VDD), U3.6 (VP), U3.10 (AVDD), U3.16 (VVCO), U3.17 (VVCO), U3.32 (SDVDD); also elsewhere on the board
!PLL_MUTE: R10.2, U3.26 (!PDRF); also elsewhere on the board
GND: C6.2 (C2), C7.2 (C2), C8.2 (C2), C9.2 (C2), C10.2 (C2), C11.2 (C2), C13.2 (C2), C14.2 (C2), C15.2 (C2), C16.2 (C2), C17.2 (C2), C18.2 (C2), C20.2 (C2), C23.2 (C2), C24.2 (C2), D2.C, R9.1, R10.1, R13.1, R14.1, R16.1, R17.1, R20.1, RFCON1.P$1 (GND), RFCON1.P$2 (GND), SHIELD1.1, SHIELD1.2, SHIELD1.3, SHIELD1.4, SHIELD1.5, SHIELD1.6, SHIELD1.7, SHIELD1.8, SHIELD1.9, SHIELD1.10, SHIELD1.11, SHIELD1.12, SHIELD1.13, SHIELD1.14, SHIELD1.15, SHIELD1.16, TP1.TP, TP2.TP, TP3.TP, TP4.TP, TP5.TP, TP6.TP, U2.1 (GND), U2.2 (GND), U3.8 (CPGND), U3.9 (AGND), U3.11 (AGNDVCO), U3.18 (AGNDVCO), U3.21 (AGNDVCO), U3.27 (DGND), U3.31 (SDGND), U3.33 (GND); also elsewhere on the board
MIXER_LO: R18.1, R20.2; also elsewhere on the board
unnamed: C19.2 (C2), C21.1 (C1), L4.2
unnamed: C11.1 (C1), L1.1, U3.28 (DVDD)
unnamed: D2.A, R11.1
unnamed: R12.2, RFCON1.P$3 (SIGNAL)
unnamed: C21.2 (C2), R16.2, R18.2
unnamed: C20.1 (C1), L3.1, L4.1, U3.13 (RFOUTA-)
unnamed: C19.1 (C1), L2.2, U3.12 (RFOUTA+)
unnamed: C22.2 (C2), R15.1, R17.2
unnamed: R14.2, U3.22 (RSET)
PLL_CP_VOUT: C22.1 (C1), C23.1 (C1), R19.2, U3.7 (CPOUT)
PLL_EN: R9.2, U3.4 (CE); also elsewhere on the board
PLL_FASTLOCK_SW: R15.2, U3.5 (SW)
PLL_LE: U3.3 (LE); also elsewhere on the board
PLL_LOCK: R11.2, U3.25 (LD)
PLL_MUXOUT: U3.30 (MUXOUT); also elsewhere on the board
PLL_REF_ACC: C12.2 (C2), U3.29 (REFIN)
PLL_REF_DCC: C10.1 (C1), C12.1 (C1), R12.1, R13.2, U2.3 (CLK)
PLL_TEMP: C17.1 (C1), C18.1 (C1), U3.19 (TEMP)
PLL_VCOM: C15.1 (C1), C16.1 (C1), U3.23 (VCOM)
PLL_VREF: C13.1 (C1), C14.1 (C1), U3.24 (VREF)
PLL_VTUNE: C24.1 (C1), R19.1, U3.20 (VTUNE)
SPI_MOSI: U3.2 (DATA); also elsewhere on the board
SPI_SCK: U3.1 (CLK); also elsewhere on the board


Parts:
C25: 1uF; CAP0603
C26: 1.2pF; CAP0603
C27, C28: 100nF; CAP0603
C29, C34: 100pF; CAP0603
C30: 47pF; CAP0603
C31, C32: DNP; CAP0603
C33: 12pF; CAP0603
C35: 220pF; CAP0603
L5, L6: 5.1nH; IND0603
L7, L13: 3.3nH; IND0603
L8, L11: 0 Ohms; IND0603
L9: 18nH; IND0603
L10: 1.8pF; IND0603
L12: 2.2pF; IND0603
L14: 1.8nH; IND0603
R21: 10K Ohms; RES0603
R22, R24, R27: 0 Ohms; RES0603
R23, R25, R26: DNP; RES0603
RFCON2: RFCON-SMA-EDGE; SMA-EDGE
RFCON3, RFCON4, RFCON5: RFCON-U.FL; U.FL
U4: F1958NBGK; QFN24_2
U5: MAX2671; SOT23-6

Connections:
3V3_IF_ATT_MIXER_CLEAN: C25.1 (C1), C27.1 (C1), C28.1 (C1), C30.1 (C1), L14.2, U4.2 (VDD), U4.3 (VMODE), U5.5 (VCC); also elsewhere on the board
!MIXER_SHDN: R21.2, U5.6 (!SHDN); also elsewhere on the board
GND: C25.2 (C2), C27.2 (C2), C28.2 (C2), C30.2 (C2), L5.1, L7.1, L10.1, L12.1, R21.1, RFCON2.GND@0 (GND), RFCON2.GND@1 (GND), RFCON2.GND@2 (GND), RFCON2.GND@3 (GND), RFCON3.P$1 (GND), RFCON3.P$2 (GND), RFCON4.P$1 (GND), RFCON4.P$2 (GND), RFCON5.P$1 (GND), RFCON5.P$2 (GND), U4.1 (D0), U4.4 (GND), U4.6 (GND), U4.7 (GND), U4.8 (GND), U4.9 (GND), U4.10 (GND), U4.11 (GND), U4.12 (GND), U4.13 (GND), U4.15 (GND), U4.19 (D6), U4.20 (D5), U4.21 (D4), U4.22 (D3), U4.23 (D2), U4.24 (D1), U4.25 (GND), U5.2 (GND); also elsewhere on the board
IF_ATT_ACC: L9.1, R24.1
IF_ATT_ACC_PROBE: C34.2 (C2), R23.1, R24.2
IF_ATT_DCC: C34.1 (C1), U4.5 (RF1)
IF_ATT_LE: U4.16 (LE); also elsewhere on the board
IF_IN_ACC: C29.2 (C2), U4.14 (RF2)
IF_IN_DCC: C29.1 (C1), RFCON2.SIG (SIGNAL)
MIXER_IN_DCC: L9.2, U5.3 (IFIN)
MIXER_LO: R22.1, R25.2; also elsewhere on the board
MIXER_OUT_ACC_PROBE: C35.2 (C2), R26.1, R27.2
MIXER_OUT_DCC: L13.1, U5.4 (RFOUT)
unnamed: C35.1 (C1), L13.2, L14.1
unnamed: R23.2, RFCON3.P$3 (SIGNAL)
unnamed: R26.2, RFCON5.P$3 (SIGNAL)
unnamed: C26.2 (C2), C31.1 (C1), L6.2, L7.2, L8.1
unnamed: C31.2 (C2), C32.1 (C1), L8.2, L10.2, L11.1
unnamed: C32.2 (C2), C33.1 (C1), L11.2, L12.2
unnamed: R22.2, U5.1 (LO)
unnamed: R25.1, RFCON4.P$3 (SIGNAL)
RF_ACC: C26.1 (C1), L5.2, L6.1, R27.1
RF_LOL_FLT_ACC: C33.2 (C2); also elsewhere on the board
SPI_MOSI: U4.18 (DATA); also elsewhere on the board
SPI_SCK: U4.17 (CLK); also elsewhere on the board


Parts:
C36: 100uF; CAP1206
C37, C39, C46: 1uF; CAP0603
C38, C41, C43, C48: 100nF; CAP0603
C40, C49: 33pF; CAP0603
C42: 0.8pF; CAP0603
C44: 10pF; CAP0603
C45: 47pF; CAP0603
C47, C50, C51: 15pF; CAP0603
C52: 22pF; CAP0603
C53: 0.7pF; CAP0603
D3: LED0603; 0603
L15: 1.5nH; IND0603
L16: 470nH; IND0603
L17: 2.2nH; IND0603
R28: 1K Ohms; RES0603
R29, R32: 0 Ohms; RES0603
R30: DNP; RES0603
R31: 1.5K Ohms; RES0603
R33: 510 Ohms; RES0603
RFCON6: RFCON-U.FL; U.FL
U6: 2450BP15E0100
U7: F1958NBGK; QFN24_2
U8: ADL5601; SOT89
U9: F1490NLGA; QFN16

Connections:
3V3_RF_ATT_PDET_CLEAN: C41.1 (C1), U7.2 (VDD), U7.3 (VMODE); also elsewhere on the board
5V0_PA_STG1_2_CLEAN: C36.1 (C1), C37.1 (C1), C38.1 (C1), C39.1 (C1), C40.1 (C1), C43.1 (C1), C45.1 (C1), C46.1 (C1), C47.1 (C1), C48.1 (C1), C49.1 (C1), L15.2, L16.2, L17.2, R28.2, R29.2, R31.2, R33.2; also elsewhere on the board
GND: C36.2 (C2), C37.2 (C2), C38.2 (C2), C39.2 (C2), C40.2 (C2), C41.2 (C2), C42.2 (C2), C43.2 (C2), C45.2 (C2), C46.2 (C2), C47.2 (C2), C48.2 (C2), C49.2 (C2), C53.2 (C2), D3.C, RFCON6.P$1 (GND), RFCON6.P$2 (GND), U6.1 (GND), U6.3 (GND), U7.1 (D0), U7.4 (GND), U7.6 (GND), U7.7 (GND), U7.8 (GND), U7.9 (GND), U7.10 (GND), U7.11 (GND), U7.12 (GND), U7.13 (GND), U7.15 (GND), U7.19 (D6), U7.20 (D5), U7.21 (D4), U7.22 (D3), U7.23 (D2), U7.24 (D1), U7.25 (GND), U8.2 (GND), U8.4 (GND), U9.1 (GND), U9.3 (GND), U9.5 (GND), U9.6 (GND), U9.7 (GND), U9.8 (GND), U9.9 (GND), U9.12 (GND), U9.17 (GND); also elsewhere on the board
unnamed: R29.1, U9.15 (GAIN_SEL)
unnamed: L15.1, U9.4 (VDD)
unnamed: R28.1, U9.14 (BIAS1)
unnamed: R31.1, U9.13 (BIAS2)
unnamed: D3.A, R33.1
unnamed: C44.2 (C2), U9.2 (RFIN)
unnamed: R30.2, RFCON6.P$3 (SIGNAL)
RF_ATT1_LE: U7.16 (LE); also elsewhere on the board
RF_LOL_FLT_ACC: U8.1 (RFIN); also elsewhere on the board
RF_PRE1_ACC: C51.2 (C2), U7.14 (RF2)
RF_PRE1_ATT_ACC: R32.1, U6.4 (RFIN)
RF_PRE1_ATT_ACC_PROBE: C50.2 (C2), R30.1, R32.2
RF_PRE1_ATT_DCC: C50.1 (C1), U7.5 (RF1)
RF_PRE1_ATT_FLT_ACC: C42.1 (C1), C44.1 (C1), U6.2 (RFOUT)
RF_PRE1_DCC: C51.1 (C1), L16.1, U8.3 (RFOUT)
RF_PRE2_ACC: C52.2 (C2), C53.1 (C1); also elsewhere on the board
RF_PRE2_DCC: C52.1 (C1), L17.1, U9.10 (RFOUT), U9.11 (RFOUT)
SPI_MOSI: U7.18 (DATA); also elsewhere on the board
SPI_SCK: U7.17 (CLK); also elsewhere on the board


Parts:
C54: 4.7uF; CAP0603
C55, C72: 100nF; CAP0603
C56, C61, C69, C71, C73: 15pF; CAP0603
C57, C60, C62, C67: 10nF; CAP0603
C58, C66: 1uF; CAP0603
C59: 10uF; CAP0603
C63: 100uF; CAP1206
C64, C68: 100pF; CAP0603
C65: 2pF; CAP0603
C70: 3.3pF; CAP0603
D4: LED0603; 0603
L18: 62nH; IND0603
L19: 0 Ohms; IND0603
R34: 0 Ohms; RES0603
R35: DNP; RES0603
R36: 1K Ohms; RES0603
R37: 2K Ohms; RES0603
R38: 100 Ohms; RES0603
R39: 49.9 Ohms; RES0603
R40: 510 Ohms; RES0603
RFCON7: RFCON-U.FL; U.FL
RFCON8: RFCON-SMA-EDGE; SMA-EDGE
U10: LTC5597; DFN8_2X2
U11: 2450BP15E0100
U12: MCP6V31; SOT23-5
U13: DC2337J5010AHF
U14: ADL5606; LFCSP16_4X4
U15: F1958NBGK; QFN24_2

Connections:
3V3_RF_ATT_PDET_CLEAN: C54.1 (C1), C55.1 (C1), C72.1 (C1), U10.1 (VCC), U10.8 (EN), U12.5 (V+), U15.2 (VDD), U15.3 (VMODE); also elsewhere on the board
5V0_PA_STG3_CLEAN: C59.1 (C1), C60.1 (C1), C63.1 (C1), C64.1 (C1), C66.1 (C1), C67.1 (C1), C68.1 (C1), C69.1 (C1), L18.2, R40.2, U14.3 (VCC), U14.4 (VBIAS); also elsewhere on the board
GND: C54.2 (C2), C55.2 (C2), C58.2 (C2), C59.2 (C2), C60.2 (C2), C62.2 (C2), C63.2 (C2), C64.2 (C2), C65.2 (C2), C66.2 (C2), C67.2 (C2), C68.2 (C2), C69.2 (C2), C70.2 (C2), C72.2 (C2), D4.C, R36.1, R39.1, RFCON7.P$1 (GND), RFCON7.P$2 (GND), RFCON8.GND@0 (GND), RFCON8.GND@1 (GND), RFCON8.GND@2 (GND), RFCON8.GND@3 (GND), U10.4 (GND), U10.5 (GND), U10.7 (GND), U10.9 (GND), U11.1 (GND), U11.3 (GND), U12.2 (V-), U13.3 (GND), U13.4 (GND), U14.2 (DISABLE), U14.5 (GND), U14.6 (GND), U14.7 (GND), U14.8 (GND), U14.13 (GND), U14.14 (GND), U14.15 (GND), U14.16 (GND), U14.17 (GND), U15.1 (D0), U15.4 (GND), U15.6 (GND), U15.7 (GND), U15.8 (GND), U15.9 (GND), U15.10 (GND), U15.11 (GND), U15.12 (GND), U15.13 (GND), U15.15 (GND), U15.19 (D6), U15.20 (D5), U15.21 (D4), U15.22 (D3), U15.23 (D2), U15.24 (D1), U15.25 (GND); also elsewhere on the board
unnamed: D4.A, R40.1
unnamed: C61.2 (C2), C65.1 (C1), U14.1 (RFIN)
unnamed: R36.2, R37.2, U12.4 (-IN)
unnamed: L19.2, U15.14 (RF2)
unnamed: R39.2, U13.5 (ISOLATED)
unnamed: C56.1 (C1), U10.6 (RFIN)
unnamed: C57.2 (C2), U10.3 (FLTR)
unnamed: R35.2, RFCON7.P$3 (SIGNAL)
RF_ATT2_LE: U15.16 (LE); also elsewhere on the board
RF_FINAL_ACC: C71.2 (C2), RFCON8.SIG (SIGNAL)
RF_FINAL_DCC: C70.1 (C1), C71.1 (C1), L18.1, U14.9 (RFOUT), U14.10 (RFOUT), U14.11 (RFOUT), U14.12 (RFOUT)
RF_PRE2_ACC: L19.1; also elsewhere on the board
RF_PRE2_ATT_ACC: C73.2 (C2), U11.4 (RFIN)
RF_PRE2_ATT_DCC: C73.1 (C1), U15.5 (RF1)
RF_PRE2_ATT_FLT_ACC: U11.2 (RFOUT), U13.1 (IN)
RF_PRE2_ATT_FLT_CPL_ACC: C56.2 (C2), R35.1, U13.2 (COUPLED)
RF_PRE2_ATT_FLT_THRU_ACC: C61.1 (C1), U13.6 (OUT)
SPI_MOSI: U15.18 (DATA); also elsewhere on the board
SPI_SCK: U15.17 (CLK); also elsewhere on the board
VPDET_AMP: R37.1, R38.2, U12.1 (OUT)
VPDET_FLT: C58.1 (C1), R34.1, U12.3 (+IN)
VPDET_RAW: C57.1 (C1), R34.2, U10.2 (OUT)
VPDET_SENSE: C62.1 (C1), R38.1; also elsewhere on the board

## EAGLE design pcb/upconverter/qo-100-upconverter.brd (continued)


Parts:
C74: 4.7uF; CAP0603; VOLTAGE 35V
C75, C83, C86, C87, C91, C92: 100nF; CAP0603
C76, C77: 470pF; CAP0603
C78: 4.7uF; CAP0603
C79, C80: 1uF; CAP0603; VOLTAGE 50V
C81, C89, C94, C95, C96, C97, C98: 1uF; CAP0603
C82: 10nF; CAP0603
C84, C85, C99, C100, C101: 10uF; CAP0603
C88: 10pF; CAP0603
C90: 100uF; CAP1206
C93: 22uF; CAP1206
C102, C103: 1nF; CAP0603
C104: 10uF; CAP1206; VOLTAGE 50V
CON2: 2EDG-2P-5MM
D5: SMAJ24A; DO214AC
D6: LED0603; 0603
F1: 2.6A Hold; 1206
L20: 4.7uH; IND0606
R41, R43, R51, R52: 100K Ohms; RES0603
R42, R48, R49: 10K Ohms; RES0603
R44: 75K Ohms; RES0603
R45: 41.2K Ohms; RES0603
R46: 1M Ohms; RES0603
R47: 221K Ohms; RES0603
R50: 0.03 Ohms; RES1206; TOLERANCE 1%
R53: 1K Ohms; RES0603
U16: MCP1700-330; SOT23
U17: LT8636; QFN20_ASYM_CORNER
U18: MCP3421-A0; SOT23-6
U19: MCP6C02-020; SOT23-6
U20, U21, U22: ADP7142AUJZ-3.3; SOT23-5
U23, U24: ADM7171ACPZ-5.0; LFCSP8_3X3

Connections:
3V3: C83.1 (C1), C84.1 (C1), C85.1 (C1), C86.1 (C1), U16.2 (VOUT), U18.5 (VDD); also elsewhere on the board
3V3_IF_ATT_MIXER_CLEAN: C99.1 (C1), U20.4 (SENSE/ADJ), U20.5 (VOUT); also elsewhere on the board
3V3_PLL_CLEAN: C101.1 (C1), U22.4 (SENSE/ADJ), U22.5 (VOUT); also elsewhere on the board
3V3_RF_ATT_PDET_CLEAN: C100.1 (C1), U21.4 (SENSE/ADJ), U21.5 (VOUT); also elsewhere on the board
5V0: C75.1 (C1), C78.1 (C1), C88.1 (C1), C89.1 (C1), C90.1 (C1), C92.1 (C1), L20.2, R43.2, R46.2, R50.2, R53.2, U16.3 (VIN), U17.2 (BIAS), U19.3 (VIP), U19.6 (VDD)
5V0_BST: C87.2 (C2), U17.7 (BST)
5V0_FB: C88.2 (C2), R46.1, R47.2, U17.19 (FB), U17.20 (FB)
5V0_INTVCC: C81.1 (C1), U17.3 (INTVCC), U17.15 (SYNC/MODE)
5V0_ISENSE: C93.1 (C1), C94.1 (C1), C95.1 (C1), C96.1 (C1), C97.1 (C1), C98.1 (C1), R50.1, U19.4 (VIM), U20.1 (VIN), U20.3 (EN), U21.1 (VIN), U21.3 (EN), U22.1 (VIN), U22.3 (EN), U23.7 (VIN), U23.8 (VIN), U24.7 (VIN), U24.8 (VIN)
5V0_ISENSE_VN: C91.2 (C2), R49.1, U18.6 (VIN-)
5V0_ISENSE_VP: C91.1 (C1), R48.1, U18.1 (VIN+)
5V0_PA_STG1_2_CLEAN: U23.1 (VOUT), U23.2 (VOUT), U23.3 (SENSE); also elsewhere on the board
5V0_PA_STG3_CLEAN: U24.1 (VOUT), U24.2 (VOUT), U24.3 (SENSE); also elsewhere on the board
5V0_RT: R45.2, U17.17 (RT)
5V0_SS: C82.1 (C1), U17.18 (TR/SS)
5V0_SW: C87.1 (C1), L20.1, U17.8 (SW), U17.9 (SW), U17.10 (SW)
5V0_VSENSE: C77.1 (C1), R43.1, R44.2; also elsewhere on the board
GND: C74.2 (C2), C75.2 (C2), C76.2 (C2), C77.2 (C2), C78.2 (C2), C79.2 (C2), C80.2 (C2), C81.2 (C2), C82.2 (C2), C83.2 (C2), C84.2 (C2), C85.2 (C2), C86.2 (C2), C89.2 (C2), C90.2 (C2), C92.2 (C2), C93.2 (C2), C94.2 (C2), C95.2 (C2), C96.2 (C2), C97.2 (C2), C98.2 (C2), C99.2 (C2), C100.2 (C2), C101.2 (C2), C102.2 (C2), C103.2 (C2), C104.2 (C2), CON2.P$1, D5.A, D6.C, R42.1, R44.1, R45.1, R47.1, R49.2, R51.1, R52.1, U16.1 (GND), U17.4 (GND), U17.5 (GND), U17.12 (GND), U17.13 (GND), U17.21 (GND), U17.M1 (GND), U17.M2 (GND), U17.M3 (GND), U17.M4 (GND), U18.2 (VSS), U19.2 (VSS), U19.5 (VREF), U20.2 (GND), U21.2 (GND), U22.2 (GND), U23.6 (GND), U23.9 (GND), U24.6 (GND), U24.9 (GND); also elsewhere on the board
I2C1_SCL: U18.3 (SCL); also elsewhere on the board
I2C1_SDA: U18.4 (SDA); also elsewhere on the board
unnamed: C103.1 (C1), U24.4 (SS)
unnamed: R48.2, U19.1 (VOUT)
unnamed: CON2.P$2, F1.2
unnamed: C102.1 (C1), U23.4 (SS)
unnamed: D6.A, R53.1
PA_STG1_2_BIAS_EN: R51.2, U23.5 (EN); also elsewhere on the board
PA_STG3_BIAS_EN: R52.2, U24.5 (EN); also elsewhere on the board
VIN: C74.1 (C1), C79.1 (C1), C80.1 (C1), C104.1 (C1), D5.C, F1.1, R41.2, U17.6 (VIN), U17.11 (VIN), U17.14 (EN/UV)
VIN_VSENSE: C76.1 (C1), R41.1, R42.2; also elsewhere on the board


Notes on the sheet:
ADP150/ADP7142 3.3V @ 150mA
VIN 7 to 24V
LT8636 5.2V @ 3A
MCP1700 3.3V @ 200mA
Digital Rail MCU, ADC, ...
Analog Rail LO Synthesizer
Analog Rail RF Attenuators, Power detector
Analog Rail IF Attenuator, Mixer
ADM7171 5.0V @ 1A
Analog Rail 1st and 2nd RF Amplifiers
Analog Rail Final RF Amplifier
Current sensing



Board: 4 copper layers, 100.0 x 70.0 mm, 227 parts (6 on the bottom side), 121 nets.

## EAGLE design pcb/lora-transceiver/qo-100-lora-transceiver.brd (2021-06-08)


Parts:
C1, C2, C3: 100nF; CAP0603
C4: 1uF; CAP0603
CON1: 3P-SH-SIDE; SH-03-SIDE
D1: LED0603; 0603
LOGO1: LORA-10MM; LORA_10MM
LOGO2: JS-10MM; JS_10MM
R1: 10K Ohms; RES0603
R2, R3: 47K Ohms; RES0603
R4, R5: 100 Ohms; RES0603
R6: 330 Ohms; RES0603
TC1: TC2050-IDC
U1: EFM32TG11B120F128GM32; QFN32_0.5P_TG

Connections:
3V3: C1.1 (C1), C2.1 (C1), C3.1 (C1), R1.2, R2.2, R3.2, TC1.1, U1.4 (IOVDD0), U1.11 (AVDD), U1.14 (IOVDD0), U1.15 (AVDD), U1.20 (DVDD), U1.28 (IOVDD0); also elsewhere on the board
5V0_VSENSE: U1.12 (PB13); also elsewhere on the board
!LORA_CS: U1.32 (PE13); also elsewhere on the board
!LORA_RESET: U1.10 (PB11); also elsewhere on the board
!RESET: R1.1, TC1.10, U1.9 (!RESET)
GND: C1.2 (C2), C2.2 (C2), C3.2 (C2), C4.2 (C2), CON1.3, D1.C, TC1.3, U1.33 (VSS); also elsewhere on the board
I2C0_SCL: R3.1, R5.2, U1.19 (PD7)
I2C0_SDA: R2.1, R4.2, U1.18 (PD6)
LED: R6.2, U1.8 (PB8)
LORA_!RX!/TX: U1.24 (PC15); also elsewhere on the board
LORA_DIO0: U1.7 (PB7); also elsewhere on the board
LORA_DIO1: U1.6 (PC1); also elsewhere on the board
LORA_DIO2: U1.5 (PC0); also elsewhere on the board
LORA_DIO3: U1.3 (PA2); also elsewhere on the board
LORA_DIO4: U1.2 (PA1); also elsewhere on the board
LORA_DIO5: U1.1 (PA0); also elsewhere on the board
unnamed: CON1.2, R5.1
unnamed: C4.1 (C1), U1.21 (DECOUPLE)
unnamed: D1.A, R6.1
unnamed: CON1.1, R4.1
SPI_MISO: U1.30 (PE11); also elsewhere on the board
SPI_MOSI: U1.29 (PE10); also elsewhere on the board
SPI_SCK: U1.31 (PE12); also elsewhere on the board
SWCLK: TC1.4, U1.25 (PF0)
SWDIO: TC1.2, U1.26 (PF1)
SWO: TC1.6, U1.27 (PF2)
VIN_VSENSE: U1.13 (PB14); also elsewhere on the board


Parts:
C5, C10, C11, C12, C13, C14, C15: 100nF; CAP0603
C6, C7: 10pF; CAP0603
C8: 220pF; CAP0603
C9, C19, C31, C32: 47pF; CAP0603
C16, C18, C25: 8.2pF; CAP0603
C17, C30: 1.5pF; CAP0603
C20: 33pF; CAP0603
C21: 22pF; CAP0603
C22, C26, C36, C37, C38, C40, C41: DNP; CAP0603
C23: 15pF; CAP0603
C24, C39: 4.7pF; CAP0603
C27: 2.7pF; CAP0603
C28, C35: 3.3pF; CAP0603
C29: 1.2pF; CAP0603
C33: 12pF; CAP0603
C34: 1.8pF; CAP0603
L1: 1uH; IND0603
L2: 2.2nH; IND0603
L3: 47nH; IND0603
L4, L5: 33nH; IND0603
L6, L15: 18nH; IND0603
L7: 22nH; IND0603
L8, L11: 10nH; IND0603
L9: 5.6nH; IND0603
L10: 4.7pF; IND0603
L12: 12nH; IND0603
L13: 6.2nH; IND0603
L14: 4.7nH; IND0603
L16, L17: 0 Ohms; IND0603
R7: 0 Ohms; RES0603
R8, R9, R10: 10K Ohms; RES0603
RFCON1: RFCON-U.FL; U.FL
RFCON2, RFCON3, RFCON4, RFCON5, RFCON6: RFCON-SMA-EDGE; SMA-EDGE
SHIELD1: SHIELD-TE-2118730; 2118730
U2: DSB321SDA; TCXO-3225
U3: SX1276; QFN28

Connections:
3V3: R9.2, R10.2; also elsewhere on the board
3V3_TRX_CLEAN: C5.1 (C1), C10.1 (C1), C12.1 (C1), L1.1, U2.4 (VDD), U3.3 (VBAT_ANA), U3.24 (VBAT_RF); also elsewhere on the board
!LORA_CS: R10.1, U3.19 (!SS); also elsewhere on the board
!LORA_RESET: R9.1, U3.7 (!RESET); also elsewhere on the board
GND: C5.2 (C2), C6.2 (C2), C8.2 (C2), C9.2 (C2), C10.2 (C2), C11.2 (C2), C12.2 (C2), C13.2 (C2), C14.2 (C2), C15.2 (C2), C16.2 (C2), C17.2 (C2), C18.2 (C2), C22.2 (C2), C23.2 (C2), C24.2 (C2), C25.2 (C2), C26.2 (C2), C28.2 (C2), C33.2 (C2), C34.2 (C2), C35.2 (C2), C39.2 (C2), C40.2 (C2), C41.2 (C2), L6.2, R8.1, RFCON1.P$1 (GND), RFCON1.P$2 (GND), RFCON2.GND@0 (GND), RFCON2.GND@1 (GND), RFCON2.GND@2 (GND), RFCON2.GND@3 (GND), RFCON3.GND@0 (GND), RFCON3.GND@1 (GND), RFCON3.GND@2 (GND), RFCON3.GND@3 (GND), RFCON4.GND@0 (GND), RFCON4.GND@1 (GND), RFCON4.GND@2 (GND), RFCON4.GND@3 (GND), RFCON5.GND@0 (GND), RFCON5.GND@1 (GND), RFCON5.GND@2 (GND), RFCON5.GND@3 (GND), RFCON6.GND@0 (GND), RFCON6.GND@1 (GND), RFCON6.GND@2 (GND), RFCON6.GND@3 (GND), SHIELD1.1, SHIELD1.2, SHIELD1.3, SHIELD1.4, SHIELD1.5, SHIELD1.6, SHIELD1.7, SHIELD1.8, SHIELD1.9, SHIELD1.10, SHIELD1.11, SHIELD1.12, SHIELD1.13, SHIELD1.14, SHIELD1.15, SHIELD1.16, SHIELD1.17, SHIELD1.18, SHIELD1.19, SHIELD1.20, SHIELD1.21, SHIELD1.22, SHIELD1.23, SHIELD1.24, SHIELD1.25, SHIELD1.26, SHIELD1.27, SHIELD1.28, U2.1 (GND), U2.2 (GND), U3.15 (GND), U3.23 (GND), U3.26 (GND), U3.29 (GND); also elsewhere on the board
LORA_!RX!/TX: U3.20 (!RX!/TX); also elsewhere on the board
LORA_DIO0: U3.8 (DIO0); also elsewhere on the board
LORA_DIO1: U3.9 (DIO1); also elsewhere on the board
LORA_DIO2: U3.10 (DIO2); also elsewhere on the board
LORA_DIO3: U3.11 (DIO3); also elsewhere on the board
LORA_DIO4: U3.12 (DIO4); also elsewhere on the board
LORA_DIO5: U3.13 (DIO5); also elsewhere on the board
LORA_TRX_VR_ANA: C13.1 (C1), U3.2 (VR_ANA)
LORA_TRX_VR_DIG: C14.1 (C1), U3.4 (VR_DIG)
LORA_TRX_VR_PA: C8.1 (C1), C9.1 (C1), C11.1 (C1), L3.1, L4.1, L5.1, U3.25 (VR_PA)
unnamed: C15.1 (C1), L1.2, U3.14 (VBAT_DIG)
unnamed: C16.1 (C1), C19.1 (C1), L3.2, U3.28 (RFO_LF)
unnamed: C19.2 (C2), L7.1
unnamed: C23.1 (C1), C27.1 (C1), L7.2, L12.1
unnamed: C27.2 (C2), C33.1 (C1), C36.1 (C1), L12.2, L15.1
unnamed: C22.1 (C1), L11.1, U3.21 (RFI_HF)
unnamed: L6.1, L10.1, U3.1 (RFI_LF)
unnamed: C26.1 (C1), C31.1 (C1), L10.2
unnamed: C17.1 (C1), C20.1 (C1), L4.2, U3.22 (RFO_HF)
unnamed: C20.2 (C2), L8.1
unnamed: C24.1 (C1), C29.1 (C1), L8.2, L13.1
unnamed: C29.2 (C2), C34.1 (C1), C37.1 (C1), L13.2, L16.1
unnamed: C37.2 (C2), C40.1 (C1), L16.2, RFCON3.SIG (SIGNAL)
unnamed: C28.1 (C1), C32.1 (C1), L11.2
unnamed: L2.1, U3.27 (PA_BOOST)
unnamed: C18.1 (C1), C21.1 (C1), L2.2, L5.2
unnamed: C36.2 (C2), C39.1 (C1), L15.2, RFCON6.SIG (SIGNAL)
unnamed: C21.2 (C2), L9.1
unnamed: C25.1 (C1), C30.1 (C1), L9.2, L14.1
unnamed: C30.2 (C2), C35.1 (C1), C38.1 (C1), L14.2, L17.1
unnamed: C38.2 (C2), C41.1 (C1), L17.2, RFCON4.SIG (SIGNAL)
unnamed: C31.2 (C2), RFCON5.SIG (SIGNAL)
unnamed: C32.2 (C2), RFCON2.SIG (SIGNAL)
unnamed: C7.2 (C2), U3.5 (XTA)
unnamed: R7.2, RFCON1.P$3 (SIGNAL)
PLL_REF_DCC: C6.1 (C1), C7.1 (C1), R7.1, R8.2, U2.3 (CLK)
SPI_MISO: U3.17 (MISO); also elsewhere on the board
SPI_MOSI: U3.18 (MOSI); also elsewhere on the board
SPI_SCK: U3.16 (SCK); also elsewhere on the board

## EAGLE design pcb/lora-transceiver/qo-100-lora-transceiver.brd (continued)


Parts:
C42, C50, C53, C57: 100nF; CAP0603
C43: 4.7uF; CAP0603; VOLTAGE 35V
C44: 4.7uF; CAP0603
C45, C51: 470pF; CAP0603
C46, C47: 1uF; CAP0603; VOLTAGE 50V
C48, C58: 1uF; CAP0603
C49: 10nF; CAP0603
C52, C59: 10uF; CAP0603
C54: 10pF; CAP0603
C55, C56: 100uF; CAP1206
C60: 10uF; CAP1206; VOLTAGE 50V
CON2: 2EDG-2P-5MM
D2: LED0603; 0603
D3: SMAJ24A; DO214AC
F1: 2.6A Hold; 1206
L18: 4.7uH; IND2520
R11, R13: 100K Ohms; RES0603
R12: 10K Ohms; RES0603
R14: 75K Ohms; RES0603
R15: 41.2K Ohms; RES0603
R16: 1M Ohms; RES0603
R17: 226K Ohms; RES0603
R18: 510 Ohms; RES0603
U4: MCP1700-330; SOT23
U5: LT8636; QFN20_ASYM_CORNER
U6: ADP7142AUJZ-3.3; SOT23-5

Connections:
3V3: C50.1 (C1), C52.1 (C1), U4.2 (VOUT); also elsewhere on the board
3V3_TRX_CLEAN: C59.1 (C1), U6.4 (SENSE/ADJ), U6.5 (VOUT); also elsewhere on the board
5V0: C42.1 (C1), C44.1 (C1), C54.1 (C1), C55.1 (C1), C56.1 (C1), C57.1 (C1), C58.1 (C1), L18.2, R13.2, R16.2, R18.2, U4.3 (VIN), U5.2 (BIAS), U6.1 (VIN), U6.3 (EN)
5V0_BST: C53.2 (C2), U5.7 (BST)
5V0_FB: C54.2 (C2), R16.1, R17.2, U5.19 (FB), U5.20 (FB)
5V0_INTVCC: C48.1 (C1), U5.3 (INTVCC), U5.15 (SYNC/MODE)
5V0_RT: R15.2, U5.17 (RT)
5V0_SS: C49.1 (C1), U5.18 (TR/SS)
5V0_SW: C53.1 (C1), L18.1, U5.8 (SW), U5.9 (SW), U5.10 (SW)
5V0_VSENSE: C51.1 (C1), R13.1, R14.2; also elsewhere on the board
GND: C42.2 (C2), C43.2 (C2), C44.2 (C2), C45.2 (C2), C46.2 (C2), C47.2 (C2), C48.2 (C2), C49.2 (C2), C50.2 (C2), C51.2 (C2), C52.2 (C2), C55.2 (C2), C56.2 (C2), C57.2 (C2), C58.2 (C2), C59.2 (C2), C60.2 (C2), CON2.P$1, D2.C, D3.A, R12.1, R14.1, R15.1, R17.1, U4.1 (GND), U5.4 (GND), U5.5 (GND), U5.12 (GND), U5.13 (GND), U5.21 (GND), U5.M1 (GND), U5.M2 (GND), U5.M3 (GND), U5.M4 (GND), U6.2 (GND); also elsewhere on the board
unnamed: CON2.P$2, F1.2
unnamed: D2.A, R18.1
VIN: C43.1 (C1), C46.1 (C1), C47.1 (C1), C60.1 (C1), D3.C, F1.1, R11.2, U5.6 (VIN), U5.11 (VIN), U5.14 (EN/UV)
VIN_VSENSE: C45.1 (C1), R11.1, R12.2; also elsewhere on the board


Board: 4 copper layers, 100.0 x 75.0 mm, 118 parts (0 on the bottom side), 67 nets.

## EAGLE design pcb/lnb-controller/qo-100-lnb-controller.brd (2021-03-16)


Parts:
C1, C2, C3: 100nF; CAP0603
C4: 1uF; CAP0603
CON1: 3P-SH-SIDE; SH-03-SIDE
D1: LED0603; 0603
LOGO1: JS-10MM; JS_10MM
R1: 10K Ohms; RES0603
R2, R3: 1K Ohms; RES0603
R4, R5: 100 Ohms; RES0603
R6: 330 Ohms; RES0603
R45, R46: 47K Ohms; RES0603
TC1: TC2050-IDC
U1: EFM32TG11B120F128GM32; QFN32_0.5P_TG

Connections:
3V3: C1.1 (C1), C2.1 (C1), C3.1 (C1), R1.2, R2.2, R3.2, R45.2, R46.2, TC1.1, U1.4 (IOVDD0), U1.11 (AVDD), U1.14 (IOVDD0), U1.15 (AVDD), U1.20 (DVDD), U1.28 (IOVDD0); also elsewhere on the board
5V0_VSENSE: U1.12 (PB13); also elsewhere on the board
!REF_SYNTH_OE: U1.23 (PC14); also elsewhere on the board
!RESET: R1.1, TC1.10, U1.9 (!RESET)
BIAS_REG_TEMP: U1.1 (PA0); also elsewhere on the board
GND: C1.2 (C2), C2.2 (C2), C3.2 (C2), C4.2 (C2), CON1.3, D1.C, TC1.3, U1.33 (VSS); also elsewhere on the board
I2C0_SCL: R5.2, R46.1, U1.19 (PD7)
I2C0_SDA: R4.2, R45.1, U1.18 (PD6)
I2C1_SCL: R3.1, U1.17 (PD5); also elsewhere on the board
I2C1_SDA: R2.1, U1.16 (PD4); also elsewhere on the board
LED: R6.2, U1.6 (PC1)
unnamed: CON1.2, R5.1
unnamed: C4.1 (C1), U1.21 (DECOUPLE)
unnamed: D1.A, R6.1
unnamed: CON1.1, R4.1
SWCLK: TC1.4, U1.25 (PF0)
SWDIO: TC1.2, U1.26 (PF1)
SWO: TC1.6, U1.27 (PF2)
VBIAS1_EN: U1.31 (PE12); also elsewhere on the board
VBIAS1_PG: U1.29 (PE10); also elsewhere on the board
VBIAS1_VSENSE: U1.2 (PA1); also elsewhere on the board
VBIAS2_EN: U1.32 (PE13); also elsewhere on the board
VBIAS2_PG: U1.30 (PE11); also elsewhere on the board
VBIAS2_VSENSE: U1.3 (PA2); also elsewhere on the board
VIN_VSENSE: U1.13 (PB14); also elsewhere on the board


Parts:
C5, C6, C9, C10: 100nF; CAP0603
C7, C8: 150pF; CAP0603
C11, C12, C19, C20: 330pF; CAP0603
C13, C14, C15, C16, C21, C22: 100pF; CAP0603
C17, C18: 1nF; CAP0603
C23, C24: 68pF; CAP0603
L1, L2, L3, L4, L5, L6, L13, L15: 470nH; IND0603
L7, L8, L14, L16: 120nH; IND0603
L9, L11: 43nH; IND0603
L10, L12: 330nH; IND0603
R7, R8: 43.2 Ohms; RES0603
R9, R10: 86.6 Ohms; RES0603
RFCON1, RFCON2: RFCON-F-EDGE; F-EDGE
RFCON3, RFCON4: RFCON-SMA-EDGE; SMA-EDGE

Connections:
GND: C5.2 (C2), C6.2 (C2), C7.2 (C2), C8.2 (C2), C17.2 (C2), C18.2 (C2), L9.2, L10.1, L11.2, L12.1, R9.1, R10.1, RFCON1.GND@0 (GND), RFCON1.GND@1 (GND), RFCON1.GND@2 (GND), RFCON1.GND@3 (GND), RFCON1.GND@4 (GND), RFCON1.GND@5 (GND), RFCON2.GND@0 (GND), RFCON2.GND@1 (GND), RFCON2.GND@2 (GND), RFCON2.GND@3 (GND), RFCON2.GND@4 (GND), RFCON2.GND@5 (GND), RFCON3.GND@0 (GND), RFCON3.GND@1 (GND), RFCON3.GND@2 (GND), RFCON3.GND@3 (GND), RFCON4.GND@0 (GND), RFCON4.GND@1 (GND), RFCON4.GND@2 (GND), RFCON4.GND@3 (GND); also elsewhere on the board
unnamed: C9.1 (C1), L3.2, RFCON1.SIGNAL
unnamed: C9.2 (C2), R7.2
unnamed: C21.1 (C1), L13.2
unnamed: C7.1 (C1), L1.2, L3.1
unnamed: C13.1 (C1), L5.2
unnamed: C13.2 (C2), C17.1 (C1), L9.1, L13.1
unnamed: C19.2 (C2), C23.1 (C1), L14.2
unnamed: C11.1 (C1), L5.1, L7.1, R7.1, R9.2
unnamed: C11.2 (C2), C15.1 (C1), C19.1 (C1), L7.2, L14.1
unnamed: C23.2 (C2), RFCON3.SIG (SIGNAL)
unnamed: C15.2 (C2), L10.2
unnamed: C10.1 (C1), L4.2, RFCON2.SIGNAL
unnamed: C10.2 (C2), R8.2
unnamed: C8.1 (C1), L2.2, L4.1
unnamed: C22.1 (C1), L15.2
unnamed: C14.1 (C1), L6.2
unnamed: C14.2 (C2), C18.1 (C1), L11.1, L15.1
unnamed: C12.1 (C1), L6.1, L8.1, R8.1, R10.2
unnamed: C12.2 (C2), C16.1 (C1), C20.1 (C1), L8.2, L16.1
unnamed: C24.2 (C2), RFCON4.SIG (SIGNAL)
unnamed: C16.2 (C2), L12.2
unnamed: C20.2 (C2), C24.1 (C1), L16.2
REF1: C21.2 (C2); also elsewhere on the board
REF2: C22.2 (C2); also elsewhere on the board
VBIAS1: C5.1 (C1), L1.1; also elsewhere on the board
VBIAS2: C6.1 (C1), L2.1; also elsewhere on the board


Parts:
C25, C26, C29, C30: 100nF; CAP0603
C27, C28: 10pF; CAP0603
R11: 100K Ohms; RES0603
R12: 10K Ohms; RES0603
R13, R14, R15, R16: 0 Ohms; RES0603
RFCON5, RFCON6: RFCON-U.FL; U.FL
U2: DSB321SDA; TCXO-3225
U3: SI5351C-B-GM; QFN20

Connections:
3V3: R11.2; also elsewhere on the board
3V3_REF_CLEAN: C25.1 (C1), C26.1 (C1), C29.1 (C1), C30.1 (C1), U2.4 (VDD), U3.10 (VDDOB), U3.11 (VDDOA), U3.14 (VDDOD), U3.18 (VDDOC), U3.20 (VDD); also elsewhere on the board
!REF_SYNTH_OE: R11.1, U3.7 (!OE); also elsewhere on the board
EXT_REF_IN: R13.2, RFCON5.P$3 (SIGNAL)
EXT_REF_OUT: R16.1, RFCON6.P$3 (SIGNAL)
GND: C25.2 (C2), C26.2 (C2), C27.2 (C2), C29.2 (C2), C30.2 (C2), R12.1, RFCON5.P$1 (GND), RFCON5.P$2 (GND), RFCON6.P$1 (GND), RFCON6.P$2 (GND), U2.1 (GND), U2.2 (GND), U3.21 (GND); also elsewhere on the board
I2C1_SCL: U3.4 (SCL); also elsewhere on the board
I2C1_SDA: U3.5 (SDA); also elsewhere on the board
unnamed: R16.2, U3.15 (CLK7)
unnamed: R15.2, U3.17 (CLK5)
unnamed: R14.2, U3.12 (CLK1)
unnamed: C27.1 (C1), C28.1 (C1), R12.2, U2.3 (CLK)
unnamed: C28.2 (C2), U3.1 (XA)
unnamed: R13.1, U3.6 (CLKIN)
REF1: R14.1; also elsewhere on the board
REF2: R15.1; also elsewhere on the board

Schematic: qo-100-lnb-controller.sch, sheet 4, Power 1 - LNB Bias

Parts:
C31: 1uF; CAP0603
C32, C33: 10nF; CAP0603
C34: 470pF; CAP0603
C35, C36, C45, C46, C47, C49, C50, C55, C56: 100nF; CAP0603
C37: 4.7uF; CAP0603; VOLTAGE 35V
C38, C39: 4.7pF; CAP0603
C40: 1uF; CAP0603; VOLTAGE 50V
C41, C42, C43, C44, C51, C52, C53, C54: 22uF; CAP1206; VOLTAGE 25V
C48: 10uF; CAP0603
D2, D3: LED0603; 0603
F1, F2: PTC0805; 0805
L17, L18: 4.7uH; IND0404
R17, R18, R20, R21: 100K Ohms; RES0603
R19: 15K Ohms; RES0603
R22: 1K Ohms; RES0603
R23, R24: 191K Ohms; RES0603
R25, R27: 1M Ohms; RES0603
R26, R28: 51K Ohms; RES0603
R29, R30: 2.55K Ohms; RES0603
U4: LT8650S-1; QFN28_ASYM_CORNER
U5: MCP4728-A2; MSOP10

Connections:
3V3: C48.1 (C1), C50.1 (C1), R20.2, R21.2, U5.1 (VDD), U5.4 (!LDAC); also elsewhere on the board
5V0: U4.22 (BIAS); also elsewhere on the board
BIAS_REG_TEMP: C34.1 (C1), R22.1; also elsewhere on the board
GND: C31.2 (C2), C32.2 (C2), C33.2 (C2), C34.2 (C2), C37.2 (C2), C40.2 (C2), C41.2 (C2), C42.2 (C2), C43.2 (C2), C44.2 (C2), C45.2 (C2), C46.2 (C2), C47.2 (C2), C48.2 (C2), C49.2 (C2), C50.2 (C2), C51.2 (C2), C52.2 (C2), C53.2 (C2), C54.2 (C2), C55.2 (C2), C56.2 (C2), D2.C, D3.C, R17.1, R18.1, R19.1, R26.1, R28.1, U4.2 (GND), U4.7 (GND), U4.29 (GND), U4.30 (GND), U4.31 (GND), U4.32 (GND), U4.33 (GND), U4.34 (GND), U4.35 (GND), U4.36 (GND), U4.37 (GND), U4.38 (GND), U5.10 (VSS); also elsewhere on the board
I2C1_SCL: U5.2 (SCL); also elsewhere on the board
I2C1_SDA: U5.3 (SDA); also elsewhere on the board
unnamed: R19.2, U4.1 (RT)
unnamed: R22.2, U4.10 (TEMP)
unnamed: D2.A, R29.1
unnamed: D3.A, R30.1
VBIAS1: C51.1 (C1), C53.1 (C1), C55.1 (C1), F1.1, R29.2; also elsewhere on the board
VBIAS1_BST: C35.2 (C2), U4.15 (BST)
VBIAS1_EN: R17.2, U4.9 (EN/UV); also elsewhere on the board
VBIAS1_FB: C38.2 (C2), R23.1, R25.1, R26.2, U4.27 (FB)
VBIAS1_PG: R20.1, U4.12 (PG); also elsewhere on the board
VBIAS1_SS: C32.1 (C1), U4.26 (SS)
VBIAS1_SW: C35.1 (C1), L17.1, U4.16 (SW), U4.17 (SW)
VBIAS1_UNFUSED: C38.1 (C1), C41.1 (C1), C43.1 (C1), C45.1 (C1), C47.1 (C1), F1.2, L17.2, R25.2
VBIAS1_VADJ: R23.2, U5.6 (VOUTA)
VBIAS2: C52.1 (C1), C54.1 (C1), C56.1 (C1), F2.1, R30.2; also elsewhere on the board
VBIAS2_BST: C36.2 (C2), U4.20 (BST)
VBIAS2_EN: R18.2, U4.8 (EN/UV); also elsewhere on the board
VBIAS2_FB: C39.2 (C2), R24.1, R27.1, R28.2, U4.24 (FB)
VBIAS2_PG: R21.1, U4.11 (PG); also elsewhere on the board
VBIAS2_SS: C33.1 (C1), U4.25 (SS)
VBIAS2_SW: C36.1 (C1), L18.1, U4.18 (SW), U4.19 (SW)
VBIAS2_UNFUSED: C39.1 (C1), C42.1 (C1), C44.1 (C1), C46.1 (C1), C49.1 (C1), F2.2, L18.2, R27.2
VBIAS2_VADJ: R24.2, U5.7 (VOUTB)
VBIAS_VCC: C31.1 (C1), U4.13 (SYNC), U4.21 (VCC), U4.23 (VC), U4.28 (VC)
VIN: C37.1 (C1), C40.1 (C1), U4.3 (VIN), U4.4 (VIN), U4.5 (VIN), U4.6 (VIN); also elsewhere on the board

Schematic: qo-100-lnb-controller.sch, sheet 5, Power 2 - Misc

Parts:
C57: 4.7uF; CAP0603; VOLTAGE 35V
C58: 4.7uF; CAP0603
C59, C60, C65, C69, C76: 470pF; CAP0603
C61, C62: 1uF; CAP0603; VOLTAGE 50V
C63, C73: 1uF; CAP0603
C64: 10nF; CAP0603
C66, C67, C72: 100nF; CAP0603
C68: 10pF; CAP0603
C70, C71: 100uF; CAP1206
C74: 10uF; CAP0603
C75: 10uF; CAP1206; VOLTAGE 50V
CON2: 2EDG-2P-5MM
D4: LED0603; 0603
D5: SMAJ24A; DO214AC
F3: 2.6A Hold; 1206
L19: 2.2uH; IND2520
L20: 4.7uH; IND2520
R31, R44: 100K Ohms; RES0603
R32: 10K Ohms; RES0603
R33, R38: 90.9K Ohms; RES0603
R34, R39: 12K Ohms; RES0603
R35: 41.2K Ohms; RES0603
R36: 309K Ohms; RES0603
R37: 71.5K Ohms; RES0603
R40: 1M Ohms; RES0603
R41: 226K Ohms; RES0603
R42: 510 Ohms; RES0603
R43: 75K Ohms; RES0603
U6: MIC23155; DFN10
U7: LT8636; QFN20_ASYM_CORNER
U8: ADP7142AUJZ-3.3; SOT23-5

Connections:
3V3: C66.1 (C1), C70.1 (C1), L19.2, R36.2, U6.3 (SNS); also elsewhere on the board
3V3_FB: R36.1, R37.2, U6.4 (FB)
3V3_REF_CLEAN: C74.1 (C1), U8.4 (SENSE/ADJ), U8.5 (VOUT); also elsewhere on the board
3V3_SOFTSTART: C60.1 (C1), U6.6 (SS)
3V3_SW: L19.1, U6.1 (SW)
5V0: C58.1 (C1), C68.1 (C1), C71.1 (C1), C72.1 (C1), C73.1 (C1), L20.2, R40.2, R42.2, R44.2, U6.2 (EN), U6.8 (VIN), U6.9 (VIN), U7.2 (BIAS), U8.1 (VIN), U8.3 (EN); also elsewhere on the board
5V0_BST: C67.2 (C2), U7.7 (BST)
5V0_FB: C68.2 (C2), R40.1, R41.2, U7.19 (FB), U7.20 (FB)
5V0_INTVCC: C63.1 (C1), U7.3 (INTVCC), U7.15 (SYNC/MODE)
5V0_RT: R35.2, U7.17 (RT)
5V0_SS: C64.1 (C1), U7.18 (TR/SS)
5V0_SW: C67.1 (C1), L20.1, U7.8 (SW), U7.9 (SW), U7.10 (SW)
5V0_VSENSE: C76.1 (C1), R43.2, R44.1; also elsewhere on the board
GND: C57.2 (C2), C58.2 (C2), C59.2 (C2), C60.2 (C2), C61.2 (C2), C62.2 (C2), C63.2 (C2), C64.2 (C2), C65.2 (C2), C66.2 (C2), C69.2 (C2), C70.2 (C2), C71.2 (C2), C72.2 (C2), C73.2 (C2), C74.2 (C2), C75.2 (C2), C76.2 (C2), CON2.P$1, D4.C, D5.A, R32.1, R34.1, R35.1, R37.1, R39.1, R41.1, R43.1, U6.7 (AGND), U6.10 (PGND), U6.11 (PGND), U7.4 (GND), U7.5 (GND), U7.12 (GND), U7.13 (GND), U7.21 (GND), U7.M1 (GND), U7.M2 (GND), U7.M3 (GND), U7.M4 (GND), U8.2 (GND); also elsewhere on the board
unnamed: CON2.P$2, F3.2
unnamed: D4.A, R42.1
VBIAS1: R33.2; also elsewhere on the board
VBIAS1_VSENSE: C65.1 (C1), R33.1, R34.2; also elsewhere on the board
VBIAS2: R38.2; also elsewhere on the board
VBIAS2_VSENSE: C69.1 (C1), R38.1, R39.2; also elsewhere on the board
VIN: C57.1 (C1), C61.1 (C1), C62.1 (C1), C75.1 (C1), D5.C, F3.1, R31.2, U7.6 (VIN), U7.11 (VIN), U7.14 (EN/UV); also elsewhere on the board
VIN_VSENSE: C59.1 (C1), R31.1, R32.2; also elsewhere on the board


Board: 2 copper layers, 70.0 x 100.0 mm, 168 parts (0 on the bottom side), 90 nets.

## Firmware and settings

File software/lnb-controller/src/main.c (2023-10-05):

#include <em_device.h>
#include <stdlib.h>
#include <math.h>
#include "debug_macros.h"
#include "utils.h"
#include "nvic.h"
#include "atomic.h"
#include "systick.h"
#include "rmu.h"
#include "emu.h"
#include "cmu.h"
#include "gpio.h"
#include "msc.h"
#include "rtcc.h"
#include "adc.h"
#include "crc.h"
#include "usart.h"
#include "i2c.h"
#include "si5351.h"
#include "mcp4728.h"
#include "wdog.h"

// Structs

// Helper macros
#define I2C_SLAVE_ADDRESS                           0x3C
#define I2C_SLAVE_REGISTER_COUNT                    256
#define I2C_SLAVE_REGISTER(t, a)                    (*(t *)&ubI2CRegister[(a)])
#define I2C_SLAVE_REGISTER_WRITE_MASK(t, a)         (*(t *)&ubI2CRegisterWriteMask[(a)])
#define I2C_SLAVE_REGISTER_READ_MASK(t, a)          (*(t *)&ubI2CRegisterReadMask[(a)])
#define I2C_SLAVE_REGISTER_STATUS                   0x00 // 8-bit
#define I2C_SLAVE_REGISTER_CONFIG                   0x01 // 8-bit
#define I2C_SLAVE_REGISTER_LNB1_BIAS_VOLTAGE_SET    0x10 // 32-bit
#define I2C_SLAVE_REGISTER_LNB1_BIAS_VOLTAGE        0x14 // 32-bit
#define I2C_SLAVE_REGISTER_LNB2_BIAS_VOLTAGE_SET    0x18 // 32-bit
#define I2C_SLAVE_REGISTER_LNB2_BIAS_VOLTAGE        0x1C // 32-bit
#define I2C_SLAVE_REGISTER_LNB1_REF_FREQ            0x30 // 32-bit
#define I2C_SLAVE_REGISTER_LNB2_REF_FREQ            0x34 // 32-bit
#define I2C_SLAVE_REGISTER_VIN_VOLTAGE              0xB0 // 32-bit
#define I2C_SLAVE_REGISTER_5V0_VOLTAGE              0xB4 // 32-bit
#define I2C_SLAVE_REGISTER_AVDD_VOLTAGE             0xC0 // 32-bit
#define I2C_SLAVE_REGISTER_DVDD_VOLTAGE             0xC4 // 32-bit
#define I2C_SLAVE_REGISTER_IOVDD_VOLTAGE            0xC8 // 32-bit
#define I2C_SLAVE_REGISTER_CORE_VOLTAGE             0xCC // 32-bit
#define I2C_SLAVE_REGISTER_EMU_TEMP                 0xD0 // 32-bit
#define I2C_SLAVE_REGISTER_ADC_TEMP                 0xD4 // 32-bit
#define I2C_SLAVE_REGISTER_BIAS_REG_TEMP            0xD8 // 32-bit
#define I2C_SLAVE_REGISTER_UPTIME                   0xE0 // 64-bit
#define I2C_SLAVE_REGISTER_RESET_DATA               0xE8 // 8-bit
#define I2C_SLAVE_REGISTER_SW_VERSION               0xF4 // 16-bit
#define I2C_SLAVE_REGISTER_DEV_UIDL                 0xF8 // 32-bit
#define I2C_SLAVE_REGISTER_DEV_UIDH                 0xFC // 32-bit

#define LNB1_INDEX  0
#define LNB2_INDEX  1

// Forward declarations
static void reset() __attribute__((noreturn));
static void sleep();

static uint32_t get_free_ram();

static void get_device_core_name(char *pszDeviceCoreName, uint32_t ulDeviceCoreNameSize);
static void get_device_name(char *pszDeviceName, uint32_t ulDeviceNameSize);
static uint16_t get_device_revision();

static void wdog_warning_isr();

static void i2c_slave_register_init();
static uint8_t i2c_slave_addr_isr(uint8_t ubRnW);
static uint8_t i2c_slave_tx_data_isr();
static uint8_t i2c_slave_rx_data_isr(uint8_t ubData);

static void lnb_ref_clk_synth_init();
static void lnb_set_ref_frequency(uint8_t ubChannel, uint32_t ulFrequency);
static uint32_t lnb_get_ref_frequency(uint8_t ubChannel);

static void lnb_set_bias_voltage(uint8_t ubChannel, float fVoltage);
static float lnb_get_bias_voltage(uint8_t ubChannel);

// Variables
volatile uint8_t ubI2CRegister[I2C_SLAVE_REGISTER_COUNT];
volatile uint8_t ubI2CRegisterWriteMask[I2C_SLAVE_REGISTER_COUNT];
volatile uint8_t ubI2CRegisterReadMask[I2C_SLAVE_REGISTER_COUNT];
volatile uint8_t ubI2CBuffer[I2C_SLAVE_REGISTER_COUNT];
volatile uint8_t ubI2CRegisterPointer = 0x00;
volatile uint8_t ubI2CByteCount = 0;
volatile uint8_t ubI2CReadSize = 0;
volatile uint8_t ubI2CChecksum = 0;
volatile uint8_t ubI2CChecksumOK = 0;
volatile uint8_t ubBiasVoltageChanged = 0;
volatile uint8_t ubRefFrequencyChanged = 0;

// ISRs

// Functions
void reset()
{
    SCB->AIRCR = 0x05FA0000 | _VAL2FLD(SCB_AIRCR_SYSRESETREQ, 1);

    while(1);
}
void sleep()
{
    rtcc_set_alarm(rtcc_get_time() + 5);

    SCB->SCR |= SCB_SCR_SLEEPDEEP_Msk; // Configure Deep Sleep (EM2/3)

    ATOMIC_BLOCK(ATOMIC_RESTORESTATE)
    {
        IRQ_CLEAR(RTCC_IRQn);

        __DMB(); // Wait for all memory transactions to finish before memory access
        __DSB(); // Wait for all memory transactions to finish before executing instructions
        __ISB(); // Wait for all memory transactions to finish before fetching instructions
        __SEV(); // Set the event flag to ensure the next WFE will be a NOP
        __WFE(); // NOP and clear the event flag
        __WFE(); // Wait for event
        __NOP(); // Prevent debugger crashes

        cmu_init();
        cmu_update_clocks();
    }
}

uint32_t get_free_ram()
{
    ATOMIC_BLOCK(ATOMIC_RESTORESTATE)
    {
        extern void *_sbrk(int);

        void *pCurrentHeap = _sbrk(1);

        if(!pCurrentHeap)
            return 0;

        uint32_t ulFreeRAM = (uint32_t)__get_MSP() - (uint32_t)pCurrentHeap;

        _sbrk(-1);

        return ulFreeRAM;
    }
}

void get_device_core_name(char *pszDeviceCoreName, uint32_t ulDeviceCoreNameSize)
{
    uint8_t ubImplementer = (SCB->CPUID & SCB_CPUID_IMPLEMENTER_Msk) >> SCB_CPUID_IMPLEMENTER_Pos;
    const char* szImplementer = "?";

    switch(ubImplementer)
    {
        case 0x41: szImplementer = "ARM"; break;
    }

    uint16_t usPartNo = (SCB->CPUID & SCB_CPUID_PARTNO_Msk) >> SCB_CPUID_PARTNO_Pos;
    const char* szPartNo = "?";

    switch(usPartNo)
    {
        case 0xC20: szPartNo = "Cortex-M0"; break;
        case 0xC60: szPartNo = "Cortex-M0+"; break;
        case 0xC21: szPartNo = "Cortex-M1"; break;
        case 0xD20: szPartNo = "Cortex-M23"; break;
        case 0xC23: szPartNo = "Cortex-M3"; break;
        case 0xD21: szPartNo = "Cortex-M33"; break;
        case 0xC24: szPartNo = "Cortex-M4"; break;
        case 0xC27: szPartNo = "Cortex-M7"; break;
    }

    uint8_t ubVariant = (SCB->CPUID & SCB_CPUID_VARIANT_Msk) >> SCB_CPUID_VARIANT_Pos;
    uint8_t ubRevision = (SCB->CPUID & SCB_CPUID_REVISION_Msk) >> SCB_CPUID_REVISION_Pos;

    snprintf(pszDeviceCoreName, ulDeviceCoreNameSize, "%s %s r%hhup%hhu", szImplementer, szPartNo, ubVariant, ubRevision);
}
void get_device_name(char *pszDeviceName, uint32_t ulDeviceNameSize)
{
    uint8_t ubFamily = (DEVINFO->PART & _DEVINFO_PART_DEVICE_FAMILY_MASK) >> _DEVINFO_PART_DEVICE_FAMILY_SHIFT;
    const char* szFamily = "?";

    switch(ubFamily)
    {
        case 0x10: szFamily = "EFR32MG1P";  break;
        case 0x11: szFamily = "EFR32MG1B";  break;
        case 0x12: szFamily = "EFR32MG1V";  break;
        case 0x13: szFamily = "EFR32BG1P";  break;
        case 0x14: szFamily = "EFR32BG1B";  break;
        case 0x15: szFamily = "EFR32BG1V";  break;
        case 0x19: szFamily = "EFR32FG1P";  break;
        case 0x1A: szFamily = "EFR32FG1B";  break;
        case 0x1B: szFamily = "EFR32FG1V";  break;
        case 0x1C: szFamily = "EFR32MG12P"; break;
        case 0x1D: szFamily = "EFR32MG12B"; break;
        case 0x1E: szFamily = "EFR32MG12V"; break;
        case 0x1F: szFamily = "EFR32BG12P"; break;
        case 0x20: szFamily = "EFR32BG12B"; break;
        case 0x21: szFamily = "EFR32BG12V"; break;
        case 0x25: szFamily = "EFR32FG12P"; break;
        case 0x26: szFamily = "EFR32FG12B"; break;
        case 0x27: szFamily = "EFR32FG12V"; break;
        case 0x28: szFamily = "EFR32MG13P"; break;
        case 0x29: szFamily = "EFR32MG13B"; break;
        case 0x2A: szFamily = "EFR32MG13V"; break;
        case 0x2B: szFamily = "EFR32BG13P"; break;
        case 0x2C: szFamily = "EFR32BG13B"; break;
        case 0x2D: szFamily = "EFR32BG13V"; break;
        case 0x2E: szFamily = "EFR32ZG13P"; break;
        case 0x31: szFamily = "EFR32FG13P"; break;
        case 0x32: szFamily = "EFR32FG13B"; break;
        case 0x33: szFamily = "EFR32FG13V"; break;
        case 0x34: szFamily = "EFR32MG14P"; break;
        case 0x35: szFamily = "EFR32MG14B"; break;
        case 0x36: szFamily = "EFR32MG14V"; break;
        case 0x37: szFamily = "EFR32BG14P"; break;
        case 0x38: szFamily = "EFR32BG14B"; break;
        case 0x39: szFamily = "EFR32BG14V"; break;
        case 0x3A: szFamily = "EFR32ZG14P"; break;
        case 0x3D: szFamily = "EFR32FG14P"; break;
        case 0x3E: szFamily = "EFR32FG14B"; break;
        case 0x3F: szFamily = "EFR32FG14V"; break;
        case 0x47: szFamily = "EFM32G";     break;
        case 0x48: szFamily = "EFM32GG";    break;
        case 0x49: szFamily = "EFM32TG";    break;
        case 0x4A: szFamily = "EFM32LG";    break;
        case 0x4B: szFamily = "EFM32WG";    break;
        case 0x4C: szFamily = "EFM32ZG";    break;
        case 0x4D: szFamily = "EFM32HG";    break;
        case 0x51: szFamily = "EFM32PG1B";  break;
        case 0x53: szFamily = "EFM32JG1B";  break;
        case 0x55: szFamily = "EFM32PG12B"; break;
        case 0x57: szFamily = "EFM32JG12B"; break;
        case 0x64: szFamily = "EFM32GG11B"; break;
        case 0x67: szFamily = "EFM32TG11B"; break;
        case 0x6A: szFamily = "EFM32GG12B"; break;
        case 0x78: szFamily = "EZR32LG";    break;
        case 0x79: szFamily = "EZR32WG";    break;
        case 0x7A: szFamily = "EZR32HG";    break;
    }

    uint8_t ubPackage = (DEVINFO->MEMINFO & _DEVINFO_MEMINFO_PKGTYPE_MASK) >> _DEVINFO_MEMINFO_PKGTYPE_SHIFT;
    char cPackage = '?';

    if(ubPackage == 74)
        cPackage = '?';
    else if(ubPackage == 76)
        cPackage = 'L';
    else if(ubPackage == 77)
        cPackage = 'M';
    else if(ubPackage == 81)
        cPackage = 'Q';

    uint8_t ubTempGrade = (DEVINFO->MEMINFO & _DEVINFO_MEMINFO_TEMPGRADE_MASK) >> _DEVINFO_MEMINFO_TEMPGRADE_SHIFT;
    char cTempGrade = '?';

    if(ubTempGrade == 0)
        cTempGrade = 'G';
    else if(ubTempGrade == 1)
        cTempGrade = 'I';
    else if(ubTempGrade == 2)
        cTempGrade = '?';
    else if(ubTempGrade == 3)
        cTempGrade = '?';

    uint16_t usPartNumber = (DEVINFO->PART & _DEVINFO_PART_DEVICE_NUMBER_MASK) >> _DEVINFO_PART_DEVICE_NUMBER_SHIFT;
    uint8_t ubPinCount = (DEVINFO->MEMINFO & _DEVINFO_MEMINFO_PINCOUNT_MASK) >> _DEVINFO_MEMINFO_PINCOUNT_SHIFT;

    snprintf(pszDeviceName, ulDeviceNameSize, "%s%huF%hu%c%c%hhu", szFamily, usPartNumber, FLASH_SIZE >> 10, cTempGrade, cPackage, ubPinCount);
}
uint16_t get_device_revision()
{
    uint16_t usRevision;

    /* CHIP MAJOR bit [3:0]. */
    usRevision = ((ROMTABLE->PID0 & _ROMTABLE_PID0_REVMAJOR_MASK) >> _ROMTABLE_PID0_REVMAJOR_SHIFT) << 8;
    /* CHIP MINOR bit [7:4]. */
    usRevision |= ((ROMTABLE->PID2 & _ROMTABLE_PID2_REVMINORMSB_MASK) >> _ROMTABLE_PID2_REVMINORMSB_SHIFT) << 4;
    /* CHIP MINOR bit [3:0]. */
    usRevision |= (ROMTABLE->PID3 & _ROMTABLE_PID3_REVMINORLSB_MASK) >> _ROMTABLE_PID3_REVMINORLSB_SHIFT;

    return usRevision;
}

void wdog_warning_isr()
{
    DBGPRINTLN_CTX("Watchdog warning!");
}
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
int main()
{
    // I2C Slave Register block
    i2c_slave_register_init();

    // LNB Bias
    lnb_bias_init();

    // LNB Reference synthesizer
    lnb_ref_clk_synth_init();

    //lnb_set_ref_frequency(LNB1_INDEX, 25800000);
    //lnb_set_ref_output_enable(LNB1_INDEX, 1);
    //lnb_set_ref_frequency(LNB2_INDEX, 25000000);
    //lnb_set_ref_output_enable(LNB2_INDEX, 1);
    //lnb_set_bias_voltage(LNB1_INDEX, 13500);
    //VBIAS1_ENABLE();
    //lnb_set_bias_voltage(LNB2_INDEX, 13500);
    //VBIAS2_ENABLE();

    while(1)
    {
        wdog_feed();

        if(I2C_SLAVE_REGISTER(uint8_t, I2C_SLAVE_REGISTER_CONFIG) & BIT(7))
        {
            delay_ms(20);

            reset();
        }

        if(I2C_SLAVE_REGISTER(uint64_t, I2C_SLAVE_REGISTER_UPTIME) != g_ullSystemTick / 1000)
        {
            ATOMIC_BLOCK(ATOMIC_RESTORESTATE)
            {
                I2C_SLAVE_REGISTER(uint64_t, I2C_SLAVE_REGISTER_UPTIME) = g_ullSystemTick / 1000;
            }
        }

        volatile uint8_t ubStatus = 0x00;
        volatile uint8_t ubConfig = 0x00;

        ATOMIC_BLOCK(ATOMIC_RESTORESTATE)
        {
            ubStatus = I2C_SLAVE_REGISTER(uint8_t, I2C_SLAVE_REGISTER_STATUS) & (BIT(4) | BIT(5));
            ubConfig = I2C_SLAVE_REGISTER(uint8_t, I2C_SLAVE_REGISTER_CONFIG);
        }

        if(ubConfig & BIT(0))
            VBIAS1_ENABLE();
        else
            VBIAS1_DISABLE();
        if(ubConfig & BIT(1))
            VBIAS2_ENABLE();
        else
            VBIAS2_DISABLE();

        if(VBIAS1_STATUS())
            ubStatus |= BIT(0);
        if(VBIAS2_STATUS())
            ubStatus |= BIT(1);
        if(VBIAS1_POWER_GOOD())
            ubStatus |= BIT(2);
        if(VBIAS2_POWER_GOOD())
            ubStatus |= BIT(3);

        if((ubConfig & BIT(4)) && !(ubStatus & BIT(4)))
        {
            lnb_set_ref_output_enable(LNB1_INDEX, 1);

            ubStatus |= BIT(4);
        }
        else if(!(ubConfig & BIT(4)) && (ubStatus & BIT(4)))
        {
            lnb_set_ref_output_enable(LNB1_INDEX, 0);

            ubStatus &= ~BIT(4);
        }

        if((ubConfig & BIT(5)) && !(ubStatus & BIT(5)))
        {
            lnb_set_ref_output_enable(LNB2_INDEX, 1);

            ubStatus |= BIT(5);
        }
        else if(!(ubConfig & BIT(5)) && (ubStatus & BIT(5)))
        {
            lnb_set_ref_output_enable(LNB2_INDEX, 0);

            ubStatus &= ~BIT(5);
        }

        if(ubConfig & BIT(6))
            REF_SYNTH_OUT_EN();
        else
            REF_SYNTH_OUT_DIS();

        if(REF_SYNTH_OUT_STAT())
            ubStatus |= BIT(6);

        ATOMIC_BLOCK(ATOMIC_RESTORESTATE)
            I2C_SLAVE_REGISTER(uint8_t, I2C_SLAVE_REGISTER_STATUS) = ubStatus;

        if(ubBiasVoltageChanged)
        {
            for(uint8_t i = 0; i < 2; i++)
            {
                ATOMIC_BLOCK(ATOMIC_RESTORESTATE)
                {
                    if(!(ubBiasVoltageChanged & BIT(i)))
                        continue;

                    lnb_set_bias_voltage(i, I2C_SLAVE_REGISTER(float, I2C_SLAVE_REGISTER_LNB1_BIAS_VOLTAGE_SET + 2 * i * sizeof(float)));
                    I2C_SLAVE_REGISTER(float, I2C_SLAVE_REGISTER_LNB1_BIAS_VOLTAGE_SET + 2 * i * sizeof(float)) = lnb_get_bias_voltage(i);

                    ubBiasVoltageChanged &= ~BIT(i);
                }
            }
        }

        if(ubRefFrequencyChanged)
        {
            for(uint8_t i = 0; i < 2; i++)
            {
                ATOMIC_BLOCK(ATOMIC_RESTORESTATE)
                {
                    if(!(ubRefFrequencyChanged & BIT(i)))
                        continue;

                    lnb_set_ref_frequency(i, I2C_SLAVE_REGISTER(uint32_t, I2C_SLAVE_REGISTER_LNB1_REF_FREQ + i * sizeof(uint32_t)));
                    I2C_SLAVE_REGISTER(uint32_t, I2C_SLAVE_REGISTER_LNB1_REF_FREQ + i * sizeof(uint32_t)) = lnb_get_ref_frequency(i);

                    ubRefFrequencyChanged &= ~BIT(i);
                }
            }
        }

        static uint64_t ullLastHeartBeat = 0;
        static uint64_t ullLastTelemetryUpdate = 0;

        if((g_ullSystemTick > 0 && ullLastHeartBeat == 0) || g_ullSystemTick - ullLastHeartBeat > 2000)
        {
            ullLastHeartBeat = g_ullSystemTick;

            LED_TOGGLE();

            if(LED_STATUS())
                ullLastHeartBeat -= 1900;
        }

        if((g_ullSystemTick > 0 && ullLastTelemetryUpdate == 0) || g_ullSystemTick - ullLastTelemetryUpdate > 5000)
        {
            ullLastTelemetryUpdate = g_ullSystemTick;

            // System Temperatures
            float fADCTemp = adc_get_temperature();
            float fEMUTemp = emu_get_temperature();
            float fBiasRegTemp = adc_get_bias_reg_temperature();

            ATOMIC_BLOCK(ATOMIC_RESTORESTATE)
            {
                I2C_SLAVE_REGISTER(float, I2C_SLAVE_REGISTER_ADC_TEMP) = fADCTemp;
                I2C_SLAVE_REGISTER(float, I2C_SLAVE_REGISTER_EMU_TEMP) = fEMUTemp;
                I2C_SLAVE_REGISTER(float, I2C_SLAVE_REGISTER_BIAS_REG_TEMP) = fBiasRegTemp;
            }

            DBGPRINTLN_CTX("----------------------------------");
            DBGPRINTLN_CTX("ADC Temperature: %.2f C", fADCTemp);
            DBGPRINTLN_CTX("EMU Temperature: %.2f C", fEMUTemp);
            DBGPRINTLN_CTX("Bias Regulator Temperature: %.2f C", fBiasRegTemp);

            // System Voltages/Currents
            float fVIN = adc_get_vin();
            float f5V0 = adc_get_5v0();
            float fAVDD = adc_get_avdd();
            float fDVDD = adc_get_dvdd();
            float fIOVDD = adc_get_iovdd();
            float fCoreVDD = adc_get_corevdd();

            ATOMIC_BLOCK(ATOMIC_RESTORESTATE)
            {
                I2C_SLAVE_REGISTER(float, I2C_SLAVE_REGISTER_VIN_VOLTAGE) = fVIN;
                I2C_SLAVE_REGISTER(float, I2C_SLAVE_REGISTER_5V0_VOLTAGE) = f5V0;
                I2C_SLAVE_REGISTER(float, I2C_SLAVE_REGISTER_AVDD_VOLTAGE) = fAVDD;
                I2C_SLAVE_REGISTER(float, I2C_SLAVE_REGISTER_DVDD_VOLTAGE) = fDVDD;
                I2C_SLAVE_REGISTER(float, I2C_SLAVE_REGISTER_IOVDD_VOLTAGE) = fIOVDD;
                I2C_SLAVE_REGISTER(float, I2C_SLAVE_REGISTER_CORE_VOLTAGE) = fCoreVDD;
            }

            DBGPRINTLN_CTX("----------------------------------");
            DBGPRINTLN_CTX("AVDD Voltage: %.2f mV", fAVDD);
            DBGPRINTLN_CTX("DVDD Voltage: %.2f mV", fDVDD);
            DBGPRINTLN_CTX("IOVDD Voltage: %.2f mV", fIOVDD);
            DBGPRINTLN_CTX("Core Voltage: %.2f mV", fCoreVDD);
            DBGPRINTLN_CTX("VIN Voltage: %.2f mV", fVIN);
            DBGPRINTLN_CTX("5V0 Voltage: %.2f mV", f5V0);

            // LNB Bias Voltages
            float fVBiasSet1 = lnb_get_bias_voltage(LNB1_INDEX);
            float fVBias1 = adc_get_vbias1();
            float fVBiasSet2 = lnb_get_bias_voltage(LNB2_INDEX);
            float fVBias2 = adc_get_vbias2();

            // Only update at first to initialize registers, otherwise race conditions can occur
            static uint8_t ubBiasSetVoltageInitialized = 0;

            if(!ubBiasSetVoltageInitialized)
            {
                ATOMIC_BLOCK(ATOMIC_RESTORESTATE)
                {
                    I2C_SLAVE_REGISTER(float, I2C_SLAVE_REGISTER_LNB1_BIAS_VOLTAGE_SET) = fVBiasSet1;
                    I2C_SLAVE_REGISTER(float, I2C_SLAVE_REGISTER_LNB2_BIAS_VOLTAGE_SET) = fVBiasSet2;
                }

                ubBiasSetVoltageInitialized = 1;
            }

            ATOMIC_BLOCK(ATOMIC_RESTORESTATE)
            {
                I2C_SLAVE_REGISTER(float, I2C_SLAVE_REGISTER_LNB1_BIAS_VOLTAGE) = fVBias1;
                I2C_SLAVE_REGISTER(float, I2C_SLAVE_REGISTER_LNB2_BIAS_VOLTAGE) = fVBias2;
            }

            DBGPRINTLN_CTX("----------------------------------");
            DBGPRINTLN_CTX("LNB #1 Enable status: %s", VBIAS1_STATUS() ? "ON" : "OFF");
            DBGPRINTLN_CTX("LNB #1 Power status: %s", VBIAS1_POWER_GOOD() ? "POWER GOOD" : "POWER NOT GOOD");
            DBGPRINTLN_CTX("LNB #1 Set Bias Voltage: %.2f mV", fVBiasSet1);
            DBGPRINTLN_CTX("LNB #1 Bias Voltage: %.2f mV", fVBias1);
            DBGPRINTLN_CTX("LNB #1 Reference Frequency: %lu Hz", lnb_get_ref_frequency(LNB1_INDEX));
            DBGPRINTLN_CTX("LNB #2 Enable status: %s", VBIAS2_STATUS() ? "ON" : "OFF");
            DBGPRINTLN_CTX("LNB #2 Power status: %s", VBIAS2_POWER_GOOD() ? "POWER GOOD" : "POWER NOT GOOD");
            DBGPRINTLN_CTX("LNB #2 Set Bias Voltage: %.2f mV", fVBiasSet2);
            DBGPRINTLN_CTX("LNB #2 Bias Voltage: %.2f mV", fVBias2);
            DBGPRINTLN_CTX("LNB #2 Reference Frequency: %lu Hz", lnb_get_ref_frequency(LNB2_INDEX));
        }
    }

    return 0;
}

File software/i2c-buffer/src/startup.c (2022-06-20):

#include <em_device.h>

extern void _estack(); // Not really a function, just to be compatible with array later

extern uint32_t _svect; // ISR Vectors
extern uint32_t _evect;

extern uint32_t _stext; // Main program
extern uint32_t _etext;

extern uint32_t _siiram0; // RAM code source
extern uint32_t _siram0; // RAM code destination
extern uint32_t _eiram0;

extern uint32_t _sidata; // Data source
extern uint32_t _sdata; // Data destination
extern uint32_t _edata;

extern uint32_t _sbss; // BSS destination
extern uint32_t _ebss;

extern uint32_t _end;


void _default_isr()
{
    while(1);
}

void __attribute__ ((weak)) __libc_init_array()
{

}

extern int init();
extern int main();

#define DEFAULT_ISR "_default_isr"

void _reset_isr()
{
    volatile uint32_t *src, *dst;

    src = &_siiram0;
    dst = &_siram0;

    while (dst < &_eiram0) // Copy RAM code
        *(dst++) = *(src++);

    src = &_sidata;
    dst = &_sdata;

    while (dst < &_edata) // Copy data
        *(dst++) = *(src++);

    src = 0;
    dst = &_sbss;

    while (dst < &_ebss) // Zero BSS
        *(dst++) = 0;

    __libc_init_array();

    SCB->VTOR = (uint32_t)&_svect; // ISR Vectors offset
    SCB->AIRCR = 0x05FA0000 | (5 << 8); // Interrupt priority - 2 bits Group, 0 bits Sub-group

    init();
    main();

    __disable_irq();
    while(1);
}

void _nmi_isr()                           __attribute__ ((weak,  alias (DEFAULT_ISR)));
void _hardfault_isr()                     __attribute__ ((weak,  alias (DEFAULT_ISR)));
void _svc_isr()                           __attribute__ ((weak,  alias (DEFAULT_ISR)));
void _pendsv_isr()                        __attribute__ ((weak,  alias (DEFAULT_ISR)));
void _systick_isr()                       __attribute__ ((weak,  alias (DEFAULT_ISR)));
void _emu_isr()                           __attribute__ ((weak,  alias (DEFAULT_ISR)));
void _wdog0_isr()                         __attribute__ ((weak,  alias (DEFAULT_ISR)));
void _ldma_isr()                          __attribute__ ((weak,  alias (DEFAULT_ISR)));
void _gpio_even_isr()                     __attribute__ ((weak,  alias (DEFAULT_ISR)));
void _smu_isr()                           __attribute__ ((weak,  alias (DEFAULT_ISR)));
void _timer0_isr()                        __attribute__ ((weak,  alias (DEFAULT_ISR)));
void _usart0_isr()                        __attribute__ ((weak,  alias (DEFAULT_ISR)));
void _acmp0_1_isr()                       __attribute__ ((weak,  alias (DEFAULT_ISR)));
void _adc0_isr()                          __attribute__ ((weak,  alias (DEFAULT_ISR)));
void _i2c0_isr()                          __attribute__ ((weak,  alias (DEFAULT_ISR)));
void _i2c1_isr()                          __attribute__ ((weak,  alias (DEFAULT_ISR)));
void _gpio_odd_isr()                      __attribute__ ((weak,  alias (DEFAULT_ISR)));
void _timer1_isr()                        __attribute__ ((weak,  alias (DEFAULT_ISR)));
void _usart1_isr()                        __attribute__ ((weak,  alias (DEFAULT_ISR)));
void _usart2_isr()                        __attribute__ ((weak,  alias (DEFAULT_ISR)));
void _uart0_isr()                         __attribute__ ((weak,  alias (DEFAULT_ISR)));
void _leuart0_isr()                       __attribute__ ((weak,  alias (DEFAULT_ISR)));
void _letimer0_isr()                      __attribute__ ((weak,  alias (DEFAULT_ISR)));
void _pcnt0_isr()                         __attribute__ ((weak,  alias (DEFAULT_ISR)));
void _rtcc_isr()                          __attribute__ ((weak,  alias (DEFAULT_ISR)));
void _cmu_isr()                           __attribute__ ((weak,  alias (DEFAULT_ISR)));
void _msc_isr()                           __attribute__ ((weak,  alias (DEFAULT_ISR)));
void _crypto0_trng0_isr()                 __attribute__ ((weak,  alias (DEFAULT_ISR)));
void _cryotimer_isr()                     __attribute__ ((weak,  alias (DEFAULT_ISR)));
void _usart3_isr()                        __attribute__ ((weak,  alias (DEFAULT_ISR)));
void _wtimer0_isr()                       __attribute__ ((weak,  alias (DEFAULT_ISR)));
void _wtimer1_isr()                       __attribute__ ((weak,  alias (DEFAULT_ISR)));
void _vdac0_isr()                         __attribute__ ((weak,  alias (DEFAULT_ISR)));
void _csen_isr()                          __attribute__ ((weak,  alias (DEFAULT_ISR)));
void _lesense_isr()                       __attribute__ ((weak,  alias (DEFAULT_ISR)));
void _lcd_isr()                           __attribute__ ((weak,  alias (DEFAULT_ISR)));
void _can0_isr()                          __attribute__ ((weak,  alias (DEFAULT_ISR)));

__attribute__ ((section(".isr_vector"))) void (* const g_pfnVectors[])() = {
    _estack,
    _reset_isr,
    _nmi_isr,
    _hardfault_isr,
    0,
    0,
    0,
    0,
    0,
    0,
    0,
    _svc_isr,
    0,
    0,
    _pendsv_isr,
    _systick_isr,
    _emu_isr,
    _wdog0_isr,
    _ldma_isr,
    _gpio_even_isr,
    _smu_isr,
    _timer0_isr,
    _usart0_isr,
    _acmp0_1_isr,
    _adc0_isr,
    _i2c0_isr,
    _i2c1_isr,
    _gpio_odd_isr,
    _timer1_isr,
    _usart1_isr,
    _usart2_isr,
    _uart0_isr,
    _leuart0_isr,
    _letimer0_isr,
    _pcnt0_isr,
    _rtcc_isr,
    _cmu_isr,
    _msc_isr,
    _crypto0_trng0_isr,
    _cryotimer_isr,
    _usart3_isr,
    _wtimer0_isr,
    _wtimer1_isr,
    _vdac0_isr,
    _csen_isr,
    _lesense_isr,
    _lcd_isr,
    _can0_isr
};

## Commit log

2020-05-28 Add PA bias simulation Add Pre amplifier bias simulation Fix pin-1 mark not visible in PA transistor
    [pa-bias-simulation.sch, preamp-bias-simulation.sch, qo-100-pa.brd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]
2020-06-05 Lots of changes PCBs in production Stencil in production Added and changed simulation files
    [pa-lpf-simulation.sch, pcb-configs.txt, qo-100-pa.brd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]
2020-06-16 Added LNB controller schematic and PCB Added GPSDO schematic Added example firmware
    [qo-100-gpsdo.sch, qo-100-lnb-controller.brd, qo-100-lnb-controller.sch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]
2020-07-08 GPSDO progress Added general filter PCB
    [qo-100-general-filter.brd, qo-100-general-filter.sch, qo-100-gpsdo.sch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]
2020-07-19 Change some component values
    [qo-100-lnb-controller.brd, qo-100-lnb-controller.sch, qo-100-upconverter.brd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]
2020-08-04 Finish general filter PCB Fix screw not connected to GND on upconverter PCB Some work on upconverter software
    [qo-100-general-filter.brd, qo-100-upconverter.brd]
2020-08-31 Matched PA to 2.4 GHz
    [qo-100-pa.brd, qo-100-pa.sch]
2020-09-07 Change upconverter input attenuation Rename general filter to generic filter Generate generic filter panel Change capacitor value on LNB controller Add PA gain response
    [qo-100-generic-filter.brd, qo-100-generic-filter.sch, qo-100-lnb-controller.brd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]
2020-09-07 Fixed generic filter holes with soldermask Added RF switch PCB
    [qo-100-generic-filter.brd, qo-100-rf-switch.brd, qo-100-rf-switch.sch]
2020-09-08 Changed PA package to include bottom exposed pad Enlarged PA PCB exposed GND on the bottom side to improve heat transfer
    [qo-100-pa.brd, qo-100-pa.sch]
2020-09-16 Finished RF switch Added Digital RF power detector Added Orange Pi control hat
    [qo-100-digital-power-meter.brd, qo-100-digital-power-meter.sch, qo-100-opi-control-hat.brd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]
2020-09-24 Renamed RF Power meter Added Power meter Added IO expander to RF switch PCB to make it work thru I2C
    [qo-100-digital-power-meter.sch, qo-100-digital-rf-power-meter.brd, qo-100-digital-rf-power-meter.sch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]
2020-09-24 Added new future PA documentation
    [BLC2425M9LS250_ref_pcb.dxf, BLP27M810_ref_pcb.dxf, BLP9G0722-20G_2100MHz_ref_pcb.dwg]
2020-09-24 Renamed Orange Pi hat to Orange Pi dock Finished OPi dock routing
    [qo-100-opi-dock.brd, qo-100-opi-dock.sch]
2020-09-24 Change some leaded packages to DFN
    [qo-100-gpsdo.sch]
2020-09-24 Updated libs on upconverter
    [qo-100-upconverter.sch]
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2020-09-26 LNB controller v2 work
    [qo-100-lnb-controller.brd, qo-100-lnb-controller.sch]
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2020-09-28 Start upconverter redesign
    [qo-100-upconverter.brd, qo-100-upconverter.sch]
2020-10-03 Update libraries on RF switch
    [qo-100-rf-switch.brd]
2020-10-03 Update 2EDG connector on power meter
    [qo-100-digital-power-meter.brd, qo-100-digital-power-meter.sch]
2020-10-03 Update SI5351 library on GPSDO
    [qo-100-gpsdo.sch]
2020-10-03 Update 2EDG library on PA
    [qo-100-pa.brd, qo-100-pa.sch]
2020-10-03 Work on LNB Controller
    [qo-100-lnb-controller.brd, qo-100-lnb-controller.sch]
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2020-10-03 Work on OPi dock
    [qo-100-opi-dock.brd, qo-100-opi-dock.sch]
2020-10-08 Add Ripple blocker to RF power meter
    [qo-100-digital-rf-power-meter.brd, qo-100-digital-rf-power-meter.sch]
2020-10-08 Add directional couplers PCB Add directional couplers generation data Add directional couplers test data
    [dir_cpl_2.4g_20dB.brd, dir_cpl_2.4g_35dB.brd, dir_cpl_525m_20dB.brd]
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2020-10-08 Work on OPi dock Added connector for reed switches for intrusion detection
    [qo-100-opi-dock.brd, qo-100-opi-dock.sch]
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2020-10-08 Add relay controller PCB
    [qo-100-relay-controller.brd, qo-100-relay-controller.sch]
2020-10-09 Rename old PA to PA-20W Add new 250W PA
    [qo-100-pa-20W.brd, qo-100-pa-20W.sch, qo-100-pa-250W.brd]
2020-10-09 Remove old PA files
    [qo-100-pa.brd, qo-100-pa.sch]
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2020-10-18 Add 10W PA driver Generated PDFs so they can be printed in the same sheet without overlapping
    [qo-100-pa-10W-driver.brd]
2020-10-25 Fix typo in CMU function
    [cmu.c]
2020-11-02 Nothing to do on RF Siwtch
    [qo-100-rf-switch.brd]
2020-11-02 Nothing to do on LNB Controller
    [qo-100-lnb-controller.brd, qo-100-lnb-controller.sch]
2020-11-02 Nothing to do on Upconverter
    [qo-100-upconverter.brd, qo-100-upconverter.sch]
2020-11-02 Nothing to do on Relay Controller
    [qo-100-relay-controller.brd]
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2020-12-19 Change IO expander to MCU in relay controller to allow later flexibility
    [qo-100-relay-controller.brd, qo-100-relay-controller.sch]
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2020-12-19 Fix typo in PSU uptime
    [index.js]
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2021-02-22 RF Switch v2: Allow chosing interface or standalone power in software
    [qo-100-rf-switch.brd, qo-100-rf-switch.sch]
2021-02-22 Fix Relay controller software Change Relay controller I2C address because it was conflicting with ZMOD4510 sensor
    [gpio.c, main.c, startup.c]
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2021-03-12 Fix tiny DRC error
    [qo-100-rf-switch.brd]
2021-03-12 Update I2C slave resistors to minimize load effect when powered down
    [qo-100-lnb-controller.brd, qo-100-lnb-controller.sch, qo-100-pa-bias-controller.brd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]
2021-03-12 Fix tiny typo in all I2C device libraries Add ZMOD4510 library Add OAQ library Add SI1133 library
    [index.js]
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2021-03-16 Revert I2C resistor chnges because they do not work
    [qo-100-lnb-controller.brd, qo-100-lnb-controller.sch, qo-100-pa-bias-controller.brd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]
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2021-03-22 Upconverter v3 software Upconverter assembly and tuning schematic changes Upconverter test documentation added
    [qo-100-upconverter.brd, qo-100-upconverter.sch]
2021-06-08 Fix power detector voltage reading
    [adc.c, main.c]
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2021-07-10 Fix PSU output power scaling factor
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2021-09-15 Add missing via under MCU in GPSDO Generate new gerbers
    [qo-100-gpsdo.brd, qo-100-gpsdo.sch]
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2021-11-10 Separate pa and pa-driver PCBs Remove PA driver output products to prepare for re-design
    [qo-100-pa-10W-driver.brd, qo-100-pa-driver.brd, qo-100-pa-driver.sch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]
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2021-11-17 Added notes on PWR_SENSE and PWR_SWITCH_EN on RF Switch schematic
    [qo-100-rf-switch.sch]
2021-11-27 Modify 250W PA PCB to fit heat spreader
    [qo-100-pa-250W.brd]
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2021-12-12 Changes to 250W PA Added smaller version of 250W PA
    [qo-100-pa-250W-small.brd]
2021-12-12 Change wrong resistor name in upconverter schematic
    [qo-100-upconverter.sch]
2021-12-13 Rework GPSDO to fit a BGA MCU instead of a QFN since it is unobtanium
    [qo-100-gpsdo-bom.csv, qo-100-gpsdo-pnp.csv, qo-100-gpsdo.brd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]
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2022-06-19 Add PA directional coupler file that was missing
2022-06-20 Fix wrong ISR vector order (SMU swapped with GPIO EVEN)
    [startup.c]
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2022-06-28 Add small delay when I2C bus GPIO toggles high, to prevent errors due to devices not found
2022-06-28 Fix some issues with Relay Controller software
    [main.c]
2022-06-29 Change TEC DAC I2C speed to 100 kHz to prevent errors, since it runs off-board
    [main.c]
2022-06-29 Change lNB Synth and DAC I2C speed to 100 kHz to prevent errors
    [main.c]
2022-06-29 Revert "Change lNB Synth and DAC I2C speed to 100 kHz to prevent errors"
    This reverts commit 7b9e43df3512c0060b9fe4b607c55ae74ed20bee.
    [main.c]
2022-06-29 Revert "Change TEC DAC I2C speed to 100 kHz to prevent errors, since it runs off-board"
    This reverts commit 4a6fbfacadff4b2348cfb4926b3ca797ca379aeb.
    [main.c]
2022-06-29 Fix race condition on bias voltage setting
    [main.c]
2022-06-29 Fix race condition on TEC voltage setting
    [main.c]
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2022-07-22 Add PnP and BOM files for I2C Buffer assembly
    [qo-100-i2c-buffer-bom.csv, qo-100-i2c-buffer-pnp.csv]
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2022-08-17 Update GPSDO cover names Add OLED GPSDO cover
    [qo-100-gpsdo-covers-oled.brd, qo-100-gpsdo-covers.brd]
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2022-10-19 Move MQTT credentials to separate file for security reasons, since now using an exposed broker
    [index.js]
2023-02-26 Fix some bugs with the SSH server Update SSH server keys Update npm package versions
    [index.js]
2023-09-05 Add I2C Buffer Add checksums, uptime and reset data features to Relay, PA Bias and LNB controllers Fix some bugs and compatibility issues with new GCC
    [adc.c, adc.h, gpio.c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]
2023-09-07 Add moving median to workaround outliers in PA Bias Controller temperature measurements
    [main.c]
2023-10-05 Changes in Si5351 library to remove double usage Fix print typos in LNB Controller software
    [main.c, si5351.c]
